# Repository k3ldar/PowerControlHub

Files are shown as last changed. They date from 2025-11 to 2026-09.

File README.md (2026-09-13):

# PowerControlHub  
PowerControlHub is an Arduino-based 12V power distribution and control system for marine and off-grid applications. It provides configurable fused relay switching, multi-protocol sensor telemetry, WiFi/BLE/MQTT connectivity, and a companion touchscreen control panel — all managed through a unified serial command protocol and EEPROM-persisted configuration.

> Current firmware version: **1.0.0.0** — see [`FirmwareVersion.h`](PowerControlHub/FirmwareVersion.h).

---

## Table of Contents

- [Overview](#overview)
- [Prototype PCBs](#prototype-pcbs)
- [Key Features](#key-features)
- [Architecture](#architecture)
- [Board Support](#board-support)
- [Installation](#installation)
- [Configuration](#configuration)
- [Usage](#usage)
- [Subsystem Reference](#subsystem-reference)
- [Limitations and Known Issues](#limitations-and-known-issues)
- [Documentation](#documentation)
- [License](#license)

## Overview

PowerControlHub is a single-unit firmware target running on an Arduino Uno R4 WiFi or ESP32 NodeMCU-32. The Nextion touchscreen display is driven directly by the PCH controller over a dedicated hardware serial port (`Serial2` for GPS; display connected via `NextionControl`).

The firmware entry point is `PowerControlHubApp`, which owns all subsystem instances and wires them together at startup. Host and debug communication uses a text-based framed serial protocol:

```
<CMD>:<key>=<value>;<key>=<value>\n
```

Commands are grouped by prefix (`F`, `C`, `R`, `H`, `W`, `S`, `M`, `N`, `E`, `T`) and are available over serial, USB, and — where applicable — the HTTP REST API. See [Docs/Commands.md](Docs/Commands.md) for the full reference.

---

## Prototype PCBs

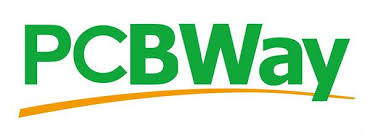
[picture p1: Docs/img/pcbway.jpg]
Prototype PCBs for PowerControlHub were supported by PCBWay

Prototype PCBs for **PowerControlHub** were supported by [PCBWay](https://www.pcbway.com), enabling rapid iteration from design to real-world testing.

See the [PCB Sponsorship & Manufacturing](Docs/pcbway.md) page for photos, build details, and ongoing testing.

---
## Key Features

### Relay Control
- Up to **8 independently configurable relay channels**, pin-assigned at runtime via configuration.
- **Linked relays** — any relay can be configured to mirror the state of another.
- **Default-on state** — individual relays can be initialised to active at boot.
- **Pulse mode** — relay activates for a configurable duration (seconds) then turns off automatically.
- **Named relays** — short name (5 chars) and long name (20 chars) stored in EEPROM for display use.
- **Action types** — relays can be designated as `Default`, `Horn` (COLREGS sound signal output), or `NightRelay` (automatic day/night switching driven by the LDR sensor).
- **Relay status bitmask** broadcast via `MessageBus` on every state change.

### Sensor Pipeline

All sensors inherit from `BaseSensor` and are registered with `SensorController`. The `RemoteSensor` class provides an extensibility point for sensors on external devices that push readings via serial.

| Sensor | Class | Poll Interval | Notes |
|---|---|---|---|
| **DHT11** | `Dht11SensorHandler` | 2 500 ms | Temperature (°C) and relative humidity (%). Raises `TemperatureSensorFailure` warning on read error; clears automatically on recovery. |
| **Light (LDR)** | `LightSensorHandler` | 30 000 ms | Rolling average over 10 readings. 3-reading debounce before day/night state change. Configurable ADC threshold (default 512). Drives a `NightRelay` automatically. |
| **Water Level** | `WaterSensorHandler` | Configurable | 15-reading rolling average. Active-pin corrosion-reduction control (power applied only during measurement). |
| **GPS** | `GpsSensorHandler` | Continuous | GY-GPS6MV2 (NMEA). Reports latitude, longitude, altitude, speed (km/h), course, cumulative distance. Provides UTC time for automatic RTC synchronisation. Raises `GpsFailure` warning if no valid fix for 30 seconds. |
| **System Diagnostics** | `SystemSensorHandler` | Configurable | Free heap memory, CPU usage percentage, WiFi/BT enabled state, SD log file size (bytes), system uptime (`d HH:MM:SS`), active warning count. |

Sensors expose data over Serial, WiFi REST, BLE, and MQTT. Custom local or remote sensors can be added with minimal boilerplate; see [Docs/Sensors.md](Docs/Sensors.md).

### Connectivity

#### WiFi
- Operates in **Access Point** or **Client** mode, selectable via `C12`.
- Implements **persistent HTTP connections** to reduce TCP handshake overhead on resource-constrained hardware.
- Supports up to **8 concurrent clients** (`MaxConcurrentClients`).
- Automatic reconnection with exponential backoff in Client mode.
- RSSI monitoring — raises `WeakWifiSignal` warning when signal falls below −70 dBm.
- Full REST API across 9 route groups:

| Route | Handler | Purpose |
|---|---|---|
| `/api/relay` | `RelayNetworkHandler` | Relay state read/write |
| `/api/sensor` | `SensorNetworkHandler` | Sensor telemetry |
| `/api/sound` | `SoundNetworkHandler` | COLREGS horn signals |
| `/api/system` | `SystemNetworkHandler` | System status, heartbeat, OTA |
| `/api/config` | `ConfigNetworkHandler` | Configuration read/write |
| `/api/warning` | `WarningNetworkHandler` | Warning bitmask access |
| `/api/timer` | `SchedulerNetworkHandler` | Scheduled event read |
| `/api/externalsensor` | `ExternalSensorNetworkHandler` | Remote sensor config |
| `/` | `WebIndexNetworkHandler` | Index page |

Uses a platform-abstraction interface (`IWifiRadio`) to isolate board-specific WiFi drivers from application logic.

#### Bluetooth BLE
- Available on boards with `BLUETOOTH_SUPPORT` defined.
- Exposes three GATT services via `BluetoothManager`:
  - `BluetoothSystemService` — system diagnostics characteristics.
  - `BluetoothSensorService` — sensor telemetry characteristics with notifications.
  - `BluetoothRelayService` — relay state read and write characteristics.
- Single-client model. Advertising restarts automatically after disconnect.
- No pairing or bonding. Device advertises as **"Power Control Hub"**.
- Uses `IBluetoothRadio` interface — higher-level code operates exclusively through the interface pointer, with runtime null-checks replacing compile-time guards.
- **Arduino Uno R4 WiFi constraint:** WiFi and BLE share the RF path on the ANNA-B112/ESP32-S3 modules; `BLUETOOTH_SUPPORT` and `WIFI_SUPPORT` are mutually exclusive on this board. Enforced by a compile-time `#error`. On ESP32, both can operate simultaneously.

#### MQTT
- Custom **MQTT 3.1.1** client implementation (`MQTTClient`) — no third-party MQTT library dependency.
- **Home Assistant auto-discovery** — all sensors and relays register as HA entities on connect.
- Configurable broker address (64 chars), credentials (32 chars each), device ID, discovery prefix, port (default 1883), and keepalive interval (default 60 s).
- Requires `WIFI_SUPPORT`. Guarded by `#if defined(WIFI_SUPPORT)` in `BoardConfig.h`.

### Warning System

A **32-bit bitmask** tracks up to 32 independent typed conditions within `WarningManager`.

- **Sensor failure aggregation**: any sensor warning (bits 21–31) automatically raises `SensorFailure` (bit 20). `SensorFailure` clears only when all sensor warnings are cleared.
- Warning state changes are broadcast on the `MessageBus` via `WarningChanged`.
- Full warning type reference: [Docs/Warnings.md](Docs/Warnings.md).

### Scheduler

Event-driven relay automation engine with EEPROM-persisted configuration.

- Up to **20 events** (6 on boards with ≤ 1 KB EEPROM) stored in `SchedulerSettings`.
- Each event specifies an independent **trigger**, **condition guard**, and **action**.

| Dimension | Supported Values |
|---|---|
| **Triggers** | `TimeOfDay`, `Sunrise`, `Sunset`, `Interval`, `DayOfWeek`, `Date` |
| **Conditions** | `TimeWindow`, `DayOfWeek`, `IsDark`, `IsDaylight`, `RelayIsOn`, `RelayIsOff` |
| **Actions** | `RelayOn`, `RelayOff`, `RelayToggle`, `RelayPulse`, `AllRelaysOn`, `AllRelaysOff`, `SetPinHigh`, `SetPinLow` |

Sunrise and sunset triggers are computed in real time from GPS coordinates by `SunCalculator`. The `IsDark` / `IsDaylight` conditions fall back to the LDR sensor when GPS is unavailable.

### Message Bus

`MessageBus` provides a **lightweight publish/subscribe event system** for internal component decoupling. No dynamic allocation occurs at publish time — subscriber lists use function-local statics.

Key events: `WarningChanged`, `RelayStatusChanged`, `TemperatureUpdated`, `HumidityUpdated`, `LightSensorUpdated`, `WaterLevelUpdated`, `GpsLocationUpdated`, `GpsAltitudeUpdated`, `GpsSpeedUpdated`, `WifiConnectionStateChanged`, `WifiSignalStrengthChanged`, `SystemMetricsUpdated`. Full reference: [Docs/MessageBus.md](Docs/MessageBus.md).

### Over-the-Air Updates (OTA)

- Available on **ESP32 + `WIFI_SUPPORT` + `OTA_AUTO_UPDATE`** only.
- Polls the GitHub Releases API (`k3ldar/PowerControlHub`) every **24 hours**.
- Downloads asset `PowerControlHub-esp32-v{major}.{minor}.{patch}.{build}.bin` with SHA-256 checksum verification.
- TLS connections use pinned root CA certificates (Sectigo E46 for `api.github.com`; ISRG Root X1 for `assets.githubusercontent.com`).
- **Auto-apply is disabled by default.** Enable via `F12:apply=1` or the `OtaFlagAutoApply` bit in `SystemHeader::reserved[0]`.
- OTA state (`idle`, `checking`, `available`, `downloading`, `rebooting`, `failed`, `uptodate`) is queryable at any time via `F13`.

### Diagnostics and Logging

- **SD card logging** via `SdCardLogger` / `MicroSdDriver`. Configurable SPI pins (`C4`). Raises `SpiPinConfigError`, `SdCardMissing`, `SdCardError`, or `SdCardLowSpace` warnings as appropriate.
- Optional **SD card config loader** (`CARD_CONFIG_LOADER`) — reads `config.txt` at boot to override EEPROM settings without reflashing.
- **DS1302 RTC** (`RtcDS1302Driver`) with configurable pins (`C18`). Automatically synchronised from GPS UTC time on each valid GPS fix.
- **CPU usage monitoring** via `SystemCpuMonitor`. Available over serial, WiFi, and MQTT.
- **Boot counter** and **crash counter** tracked in `SystemHeader` with magic number validation (`0x53464201`).
- **RGB LED warning indicator** (HW479) driven on configurable pins (`C8`).
- **PinGuard** — compile-time GPIO validation layer that rejects flash-reserved, input-only, and strapping pins at the point of assignment, returning `ACK:<cmd>=Invalid pin` before the value reaches EEPROM. Board-specific tables are selected automatically from the IDF toolchain macros — no manual configuration required. See [Docs/PinGuard.md](Docs/PinGuard.md).
- **Crash loop guard** — `crashCounter` in `SystemHeader` is incremented at the start of every boot and only reset after full initialisation succeeds. If the counter reaches `CrashCounterThreshold` (default 3), the firmware resets the config to safe defaults before any hardware initialisation runs, breaking a watchdog reset loop caused by invalid pin configuration.

### Nextion Display

- `NavigationController` manages an ordered list of active pages, rebuilt dynamically when the location type changes — no reboot required.
- Maritime-specific pages (buoys, cardinal markers, flags, VHF radio, COLREGS sound signals) are included in the page list only when `LocationType` is `Power`, `Sail`, `Fishing`, or `Yacht`.
- Pages included: Splash, Home, Relay, Relay Settings, Environment, System, Warning, Settings, About, Buoys, Cardinal Markers, Flags, Moon Phase, Sound (Fog / Maneuvering / Overtaking / Emergency / Other / Signals), VHF (Channels / Distress / Radio).

### Security

- **API key and HMAC key** fields (32 chars each) are reserved in the `Config` struct for future HTTP authentication.

---

## Architecture

### Repository Structure

```
PowerControlHub/    Firmware source (relays, sensors, WiFi, BLE, MQTT, OTA, SD, Nextion display)
Docs/            Reference documentation
TestData/        Serial command test scripts
```

### Subsystem Dependency Graph

```
PowerControlHubApp
├── MessageBus                  Pub/sub event bus (no dynamic allocation)
├── RelayController             Relay switching, linking, pulse, action types
├── SoundController             COLREGS signal sequencer -> horn relay
├── SensorController            Sensor pipeline (local + remote)
│   ├── Dht11SensorHandler
│   ├── LightSensorHandler
│   ├── WaterSensorHandler
│   ├── GpsSensorHandler
│   ├── SystemSensorHandler
│   └── RemoteSensor (xN)
├── ConfigController            EEPROM config lifecycle
├── WarningManager              32-bit bitmask, sensor failure aggregation
├── ScheduleController          Event engine: trigger -> condition -> action
├── WifiController              WiFi lifecycle, HTTP REST API
│   └── WifiServer              Connection state machine, request routing
├── BluetoothController         BLE lifecycle (BLUETOOTH_SUPPORT)
│   └── BluetoothManager
│       ├── BluetoothSystemService
│       ├── BluetoothSensorService
│       └── BluetoothRelayService
├── MQTTController              MQTT 3.1.1 client, HA auto-discovery (MQTT_SUPPORT)
├── SdCardLogger                SD card log writer (SD_CARD_SUPPORT)
├── RtcDS1302Driver             DS1302 real-time clock
├── OtaManager                  GitHub OTA (OTA_AUTO_UPDATE + ESP32 + WIFI_SUPPORT)
├── BroadcastManager            Centralised serial broadcast to computer/debug port
├── NavigationController        Nextion page navigation (NEXTION_DISPLAY_DEVICE)
└── SerialCommandManager        Framed serial command dispatch (USB/debug)
```

### Interface Abstraction Pattern

WiFi and Bluetooth subsystems are each accessed through a platform-agnostic interface (`IWifiRadio`, `IBluetoothRadio`). Board-specific drivers (`R4WifiRadio`, `Esp32WifiRadio`, `BluetoothController`) are constructed only inside `PowerControlHubApp` under the appropriate `#if defined(...)` guard. All higher-level code operates through interface pointers with runtime null-checks, minimising preprocessor usage and enabling straightforward test doubles.

### Configuration Persistence

The `Config` struct is a versioned, packed POD serialised to EEPROM. The current layout version is **6** (`ConfigVersion6`). The `SystemHeader` (32 bytes) precedes the config payload and contains a magic number (`0x53464201`), boot count, crash counter, reset reason, OTA flags, and a 16-bit checksum. A config version mismatch triggers migration logic in `ConfigManager` and raises `DefaultConfigurationFuseBox`.

---

## Board Support

| Board | WiFi | BLE | MQTT | OTA | Notes |
|---|---|---|---|---|---|
| **Arduino Uno R4 WiFi** | Yes | Yes | Yes | No | WiFi and BLE are mutually exclusive (shared RF path) |
| **Arduino Uno R4 Minima** | No | No | No | No | Serial and sensor support only |
| **ESP32 NodeMCU-32** | Yes | Yes | Yes | Yes | Full feature support; WiFi and BLE simultaneous |

Board selection is controlled by a single `#define` in `Local.h` using the trailing-underscore convention. `BoardConfig.h` derives all capability flags, EEPROM limits, and enforces incompatible feature combinations at compile time.

---

## Installation

### Prerequisites

| Requirement | Details |
|---|---|
| **Arduino IDE** | 1.8.19 or Arduino IDE 2.x |
| **Git for Windows** | Standard installation |
| **Windows 10 / 11** | No special configuration required |

### Required Libraries (Arduino Library Manager)

| Library | Source |
|---|---|
| `SerialCommandManager` | Si Carter |
| `DHT sensor library` | Adafruit |
| `QMC5883LCompass` | Arduino Library Manager |
| `NextionControl` | Custom — copy `NextionControl/` folder to Arduino `libraries/` directory |

### Steps

1. Clone the repository:

   ```
   git clone https://github.com/k3ldar/PowerControlHub
   ```

2. Install all required libraries via the Arduino IDE Library Manager, and copy `NextionControl` manually.

3. Open `k3ldar/PowerControlHub.ino` in the Arduino IDE.

4. Edit `Local.h` to activate the correct board and feature flags (see [Configuration](#configuration)).

5. Select the target board and COM port, then upload.

Full setup walkthrough: [Docs/SETUP.md](Docs/SETUP.md).

---

## Configuration

All hardware-specific configuration is isolated in a single file: `PowerControlHub/Local.h`. No other file requires modification for a standard hardware setup.

### Board Selection

Exactly one board define must be active. Remove the trailing underscore to activate:

```cpp
#define ARDUINO_UNO_R4       // Arduino Uno R4 WiFi
#define ARDUINO_R4_MINIMA_   // Arduino Uno R4 Minima (inactive)
#define ESP32_NODE_32_       // ESP32 NodeMCU-32 (inactive)
```

### Feature Flags

| Define | Default | Approx. Flash | Description |
|---|---|---|---|
| `FUSE_BOX_CONTROLLER` | Active | — | Enables the full SFB subsystem stack |
| `WIFI_SUPPORT` | Active | — | WiFi controller and HTTP REST API |
| `MQTT_SUPPORT` | Active | ~40 KB | MQTT client and HA auto-discovery (requires `WIFI_SUPPORT`) |
| `BLUETOOTH_SUPPORT` | Inactive | ~144 KB | BLE services (mutually exclusive with WiFi on Uno R4) |
| `SD_CARD_SUPPORT` | Active | ~32 KB | SD card logger and SPI driver |
| `NEXTION_DISPLAY_DEVICE` | Active | ~52 KB | Nextion display page system |
| `OTA_AUTO_UPDATE` | Active | ~165 KB | GitHub OTA (ESP32 + WiFi only) |
| `LED_MANAGER` | Inactive | — | Arduino R4 WiFi LED matrix (experimental) |
| `CARD_CONFIG_LOADER` | Inactive | — | Load config overrides from SD `config.txt` at boot |

### Relay Count

```cpp
constexpr uint8_t ConfigRelayCount = 8;  // number of relay channels
```

Pins are assigned at runtime via the `R11` serial command and persisted to EEPROM. `0xFF` marks a pin as unassigned.

Full configuration reference: [Docs/Local.md](Docs/Local.md).

---

## Usage

### Serial / USB Commands (Quick Reference)

Commands follow the frame format: `<CMD>:<key>=<value>;<key>=<value>\n`

```
# Save config to EEPROM
C0

# Enable WiFi in client mode, set SSID and password
C11:v=1
C12:v=1
C13:YourSSID
C14:YourPassword
C0

# Switch relay 0 on / off
R3:i=0;v=1
R3:i=0;v=0

# Query all relay states
R2

# Read temperature and humidity
S0
S1

# Enable MQTT and set broker
M0:v=1
M1:192.168.1.100
C0

# Enable Home Assistant auto-discovery
M6:v=1

# Query OTA status (ESP32 only)
F13

# Check for firmware update
F12

# Apply firmware update immediately
F12:apply=1
```

Full command reference (all groups, all parameters): [Docs/Commands.md](Docs/Commands.md).

### HTTP REST API (WiFi)

```
# Relay control
POST /api/relay/R3?i=0&v=1

# Sensor data
GET /api/sensor/S0

# System status
GET /api/system/F2

# OTA status
GET /api/system/F13
```

---

## Subsystem Reference

| Document | Contents |
|---|---|
| [Docs/Commands.md](Docs/Commands.md) | Full serial and REST command reference (all groups F, C, R, H, W, S, M, N, E, T) |
| [Docs/Local.md](Docs/Local.md) | `Local.h` configuration reference: board selection, feature flags, pin layout |
| [Docs/PinGuard.md](Docs/PinGuard.md) | GPIO validation: board pin tables, blocked pin tiers, crash loop guard |
| [Docs/Sensors.md](Docs/Sensors.md) | Sensor classes, poll intervals, MQTT channels, warning behaviour, extensibility guide |
| [Docs/Warnings.md](Docs/Warnings.md) | 32-bit warning type reference, `WarningManager` API, propagation model |
| [Docs/Wifi.md](Docs/Wifi.md) | WiFi architecture: connection state machine, persistent connection model, handler pattern |
| [Docs/BluetoothBle.md](Docs/BluetoothBle.md) | BLE service/characteristic reference, connection model, adding new services |
| [Docs/ScheduleEvents.md](Docs/ScheduleEvents.md) | Scheduler data structures, trigger/condition/action types, EEPROM layout |
| [Docs/MessageBus.md](Docs/MessageBus.md) | Event reference, publish/subscribe API |
| [Docs/SETUP.md](Docs/SETUP.md) | Prerequisites, library installation, build instructions |
| [Docs/BOM.md](Docs/BOM.md) | Bill of materials: hardware, fasteners, connectors, 3D-printed parts |

---

## Limitations and Known Issues

- **Arduino Uno R4 WiFi**: WiFi and BLE cannot operate simultaneously due to the shared RF hardware path. This is enforced at compile time.
- **Arduino Uno R4 Minima**: No radio support. Serial, sensors, and Nextion display only.
- **OTA updates**: Restricted to ESP32 targets with WiFi in client mode and `OTA_AUTO_UPDATE` defined. Not available on Arduino Uno R4.
- **Scheduler capacity**: Limited to 6 events on boards with 1 KB or less of EEPROM.
- **LED matrix manager** (`LED_MANAGER`): Experimental on Arduino R4 WiFi; not recommended for production use.
- **SD card support**: Marked experimental in `Local.h`. SPI pin configuration must be correct or `SpiPinConfigError` is raised.
- **Single BLE client**: Only one BLE central can be connected at a time. No pairing or bonding is implemented.

---

## Documentation

| Getting Started | Configuration | Connectivity |
|:---|:---|:---|
| [Setup Guide](Docs/SETUP.md) | [Local.h Reference](Docs/Local.md) | [WiFi Architecture](Docs/Wifi.md) |
| [Bill of Materials](Docs/BOM.md) | [Scheduled Events](Docs/ScheduleEvents.md) | [Bluetooth BLE](Docs/BluetoothBle.md) |
| [Sensor Reference](Docs/Sensors.md) | [Warning System](Docs/Warnings.md) | [Message Bus](Docs/MessageBus.md) |
| [Command Reference](Docs/Commands.md) | [PinGuard & Crash Loop](Docs/PinGuard.md) | |

---

## License

PowerControlHub is released under the **GNU General Public License v3.0**.  
See [LICENSE](LICENSE) for the full licence text.

Copyright &copy; 2025 Simon Carter (`s1cart3r@gmail.com`)

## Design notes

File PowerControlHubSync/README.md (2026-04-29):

# SmartFuseSync

A lightweight console utility for applying configuration updates to SmartFuseBox devices over a COM port serial connection.

---

## Commands

Run `SmartFuseSync -?` for a full list of available commands.

### `Config Update` — Apply a configuration file to a device

Reads a `.dat` configuration file and sends each non-blank line to the device one at a time, waiting for an `ACK` or `ERR` response before proceeding to the next command.

| Option | Abbreviation | Required | Description |
|---|---|---|---|
| `filePath` | `-f` | Yes | Path to the `.dat` configuration file |
| `portName` | `-p` | Yes | COM port name (e.g. `COM3`, `COM7`) |
| `baudRate` | `-b` | No | Baud rate (default: `9600`) |

**Examples:**

Using full option names:
```
SmartFuseSync Config Update --filePath:"C:\Configs\MyDevice.dat" --portName:COM7 --baudRate:115200
```

Using abbreviations:
```
SmartFuseSync Config Update -f:"C:\Configs\MyDevice.dat" -p:COM7 -b:115200
```

**Using a `.bat` file (recommended for repeated use):**

Create a `.bat` file with the same base name as your `.dat` file, e.g. `UpdateBasementSensor.bat`:
```bat
SmartFuseSync Config Update -f:"C:\GitProjects\SFB\UpdateBasementSensor.dat" -p:COM7 -b:115200
```

Double-click the `.bat` file or run it from a terminal to apply the configuration.

---

### `Config ListPorts` — List available COM ports

Displays all COM ports currently detected on the system. Useful for identifying the correct port before running an update.

```
SmartFuseSync Config ListPorts
```

---

### `Config Test` — Test connection to a device

Opens the specified COM port and confirms a connection can be established.

| Option | Abbreviation | Required | Description |
|---|---|---|---|
| `portName` | `-p` | Yes | COM port name (e.g. `COM3`, `COM7`) |
| `baudRate` | `-b` | No | Baud rate (default: `9600`) |

```
SmartFuseSync Config Test -p:COM7 -b:115200
```

---

### `Config Read` — Read current configuration from a device

Sends a `READ_CONFIG` request to the device and displays the response. Optionally saves the output to a file.

| Option | Abbreviation | Required | Description |
|---|---|---|---|
| `portName` | `-p` | Yes | COM port name (e.g. `COM3`, `COM7`) |
| `outputPath` | `-o` | No | File path to save the received configuration |
| `baudRate` | `-b` | No | Baud rate (default: `9600`) |

```
SmartFuseSync Config Read -p:COM7 -b:115200
SmartFuseSync Config Read -p:COM7 -b:115200 -o:"C:\Configs\Backup.dat"
```

---

## Configuration file format

Configuration files (`.dat`) contain one command per line. Blank lines are ignored. Each line is sent verbatim to the device.

**Example `UpdateBasementSensor.dat`:**
```
C11:v=1
C12:v=MyNetwork
M0:v=1
M1:v=0
```

The device responds to each command with:
- `ACK:<command>=ok:...` — command accepted
- `ERR:<command>:...` — command rejected (logged as a warning, processing continues)

---

## Serial port settings

All commands use the following fixed serial settings:

| Setting | Value |
|---|---|
| Parity | None |
| Data bits | 8 |
| Stop bits | 1 |
| Handshake | None |

The baud rate is configurable via `-b` (default `9600`). Use `-b:115200` for faster devices.

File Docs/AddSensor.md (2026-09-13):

# Adding a New Sensor Type

This guide lists every file that must be touched when adding a new local sensor type to PowerControlHub. It uses the Reed contact sensor (`S24`, `SensorIdList::ReedSensor` / `SensorType.ReedSwitch`) as the reference implementation.

## Overview

A sensor type spans two projects:

| Project | Path | Language |
|---|---|---|
| Firmware | `PowerControlHub\` | C++ (Arduino / ESP32) |
| App | `PowerControlHubApp\` | C# / .NET MAUI |

Configuration plumbing (add / remove / rename / pin / options) is **type-agnostic** and driven by the `SensorDescriptors` table in `SensorConfig.h`. Most of the integration work is metadata: describe the sensor's pins and options, then implement its runtime behaviour.

## Quick-reference touch-point table

| # | File | Change |
|---|---|---|
| 1 | `PowerControlHub\SystemDefinitions.h` | Add `SensorIdList` value + telemetry command constant |
| 2 | `PowerControlHub\SensorConfig.h` | Add `SensorTypeDescriptor` entry |
| 3 | `PowerControlHub\<NewSensor>Handler.h` | New handler class |
| 4 | `PowerControlHub\SensorFactory.h` | `#include` + factory `case` |
| 5 | `PowerControlHub\SensorNetworkHandler.cpp` | WiFi telemetry dispatch |
| 6 | `PowerControlHub\SensorCommandHandler.cpp/.h` | Serial query/push (only if polled over COM) |
| 7 | `PowerControlHub\WarningType.h` | New failure warning (only if needed) |
| 8 | `PowerControlHubApp\Models\SensorType.cs` | App enum mirror |
| 9 | `PowerControlHubApp\Internal\Constants.cs` | `SensorEnumXxx` constant |
| 10 | `PowerControlHubApp\Models\LocalSensorConfigModel.cs` | `TypeName` switch case |
| 11 | `PowerControlHubApp\Models\ExternalSensorConfigModel.cs` | `SensorIdNames` array entry |
| 12 | `PowerControlHubApp\Views\Templates\SensorTemplateSelector.cs` | Template mapping |
| 13 | `PowerControlHubApp\ViewModels\LocalSensorDetailViewModel.cs` | Fallback picker entry |
| 14 | `PowerControlHubApp\ViewModels\ExternalSensorDetailViewModel.cs` | Fallback picker entry |
| 15 | `PowerControlHubApp\Resources\Localization\AppResources.resx` (+ locales + `.Designer.cs`) | Display strings |
| 16 | `PowerControlHubApp\Models\Json\SensorsModel.cs` (+ optional XAML template) | Dashboard card fields |
| 17 | `Docs\Commands.md` | Command documentation |

---

## 1. Firmware

### 1.1 `SystemDefinitions.h`

Two additions:

1. A unique enum value in `SensorIdList`, inserted **before** `Count` (`None = 0xFF` stays last):

```cpp
enum class SensorIdList : uint8_t
{
    // ... existing values ...
    ReedSensor = 0x7,

    Count,
    None = 0xFF
};
```

2. A telemetry command ID constant. Pick the next free number after the existing `S7`–`S21` range (Binary Presence is `S22`, Voltage is `S23`, Reed is `S24`):

```cpp
constexpr char SensorReed[] = "S24";
```

### 1.2 `SensorConfig.h`

Add a `SensorTypeDescriptor` entry indexed by the new enum value. This table drives the MAUI config UI (pin slots, options, ranges, defaults) and PinGuard validation, so it is the single source of truth for how the sensor is configured over both COM and WiFi.

```cpp
[static_cast<size_t>(SensorIdList::ReedSensor)] = {
    .name = "Reed",
    .pins = {
        { "Sensor Pin", "gpio", 0, 39, 255, PinUse::Sensor },
        { "Active Pin", "gpio", 0, 39, 255, PinUse::Output },
        { "Unused", "none", 0, 0, 0, PinUse::Sensor },
        { "Unused", "none", 0, 0, 0, PinUse::Sensor },
    },
    .options1 = {
        { "NO/NC", "int8", 0, 1, 0, PinUse::Sensor },
        { "Unused", "none", 0, 0, 0, PinUse::Sensor },
    },
    .options2 = { { "Unused", "none", 0, 0, 0, PinUse::Sensor }, { "Unused", "none", 0, 0, 0, PinUse::Sensor } },
},
```

Notes:

- `pins` has `ConfigMaxSensorPins` (4) slots; `options1`/`options2` have 2 slots each.
- `type` is `"gpio"`, `"int8"`, `"int16"`, or `"none"`. Only `"gpio"` slots go through PinGuard.
- `defaultValue` `255` (`PinDisabled`) means "not fitted" for a pin.
- The existing `static_assert(std::size(SensorDescriptors) == SensorIdList::Count, ...)` will fail until you add this entry.

### 1.3 Create the handler class

Create `PowerControlHub\<NewSensor>Handler.h`. Derive from `BaseSensor` (and `BroadcastLoggerSupport` if the sensor sends debug/telemetry):

| Member | Purpose |
|---|---|
| `initialize()` | Set `pinMode`, initial state, optional output pin |
| `update()` | Poll the hardware; return the poll interval in ms; publish state changes |
| `formatStatusJson()` | Serialize current values; this becomes the sensor's dashboard JSON |
| `getSensorIdType()` | Return the new `SensorIdList` value |
| `getSensorType()` | Return `SensorType::Local` |
| `getSensorCommandId()` | Return the `SensorXxx` command constant |
| `getMqttChannelCount()/getMqttChannel()/getMqttValue()` | MQTT channel metadata (under `#if defined(MQTT_SUPPORT)`) |

For binary sensors, `formatStatusJson()` should emit a `"state":"detected"|"clear"` string — the app's `SensorsModel` maps these to red/green icons.

Self-broadcasting sensors call `sendCommand(SensorXxx, params, count)` from `update()` to push telemetry over serial/WiFi. See `ReedSensorHandler.h`, `BinaryPresenceSensor.cpp`, and `VoltageSensorHandler.h` for the pattern.

### 1.4 `SensorFactory.h`

1. Add `#include "<NewSensor>Handler.h"` at the top.
2. Add a `case SensorIdList::<NewSensor>:` inside `createOne()`. Validate the required pin (`entry.pins[0] != PinDisabled`), raise the appropriate `WarningType` on failure, and map `entry.pins`/`entry.options1`/`entry.options2` into the constructor arguments.

### 1.5 `SensorNetworkHandler.cpp`

Add the new command constant to the `S7`–`S24` telemetry dispatch condition so `/api/sensor` can query the sensor's status over WiFi:

```cpp
SystemFunctions::commandMatches(command, SensorReed)
```

### 1.6 `SensorCommandHandler.cpp` / `.h` (serial COM)

This centralized handler stores last values for `S7`–`S21` and answers no-param serial polls. Sensors such as Binary Presence (`S22`), Voltage (`S23`), and Reed (`S24`) **self-broadcast** via `BroadcastLoggerSupport::sendCommand` instead of storing state here.

- If the new sensor self-broadcasts and does **not** need a serial poll query, no change is required.
- If you want a no-param serial poll (e.g. `S24` returns the current value), add a query branch in `handleCommand()` and the command to `supportedCommands()`.

### 1.7 `WarningType.h` (conditional)

Only if the new sensor needs its own distinct failure warning. Add a bit flag and a `PROGMEM` string, then raise it from `SensorFactory::createOne()`. Otherwise reuse an existing warning (e.g. `SensorFailure` or `BinarySensorFailure`).

`Config.h` needs **no change** for a typical sensor — `SensorEntry` already provides `pins[4]`, `options1[2]`, and `options2[2]`.

---

## 2. MAUI app

The app mirrors the firmware enum and provides config UI and dashboard rendering.

### 2.1 `Models\SensorType.cs`

Add an enum value matching the firmware `SensorIdList` numeric value:

```csharp
ReedSwitch = 0x7,
```

### 2.2 `Internal\Constants.cs`

Add the numeric constant used by the config models:

```csharp
public const int SensorEnumReed = 7;
```

### 2.3 `Models\LocalSensorConfigModel.cs`

Add a `SensorEnumXxx => SensorTypeXxx` case to the `TypeName` switch.

### 2.4 `Models\ExternalSensorConfigModel.cs`

Add an entry to the `SensorIdNames` array at the index matching the enum value:

```csharp
SensorTypeReed,        // 7  Reed
```

### 2.5 `Views\Templates\SensorTemplateSelector.cs`

Map the new `SensorType` to an existing template (e.g. `BinaryPresenceTemplate`) or `GenericTemplate`:

```csharp
SensorType.ReedSwitch => BinaryPresenceTemplate ?? GenericTemplate,
```

### 2.6 View models (config picker fallback)

Add the picker label to the fallback list in **both**:

- `ViewModels\LocalSensorDetailViewModel.cs`
- `ViewModels\ExternalSensorDetailViewModel.cs`

```csharp
SensorTypeOptions.Add(SensorTypeReedPicker);
```

(This fallback is only used when the device's `?meta=1` descriptor cache is unavailable; otherwise the list is built from `SensorDescriptors`.)

### 2.7 Localization strings

Add `SensorTypeReed` ("Reed") and `SensorTypeReedPicker` ("Reed (7)") to:

- `Resources\Localization\AppResources.resx`
- each localized variant (e.g. `AppResources.de-DE.resx`, etc.)
- `AppResources.Designer.cs` (regenerated by Visual Studio from the `.resx`)

### 2.8 Dashboard card (optional)

- `Models\Json\SensorsModel.cs`: add computed properties that read the new sensor's fields from `ExtraFields` (parsed from `formatStatusJson()`).
- If a dedicated card is wanted, create `Views\Templates\<NewSensor>Template.xaml` (+ code-behind), register it in `Views\DashboardPage.xaml`, and add a `DataTemplate` property to `SensorTemplateSelector`.

`Services\DashboardConnection.cs` already casts the firmware `idType` to `SensorType` via `(SensorType)idType`, so no change is needed there as long as the enum value matches.

---

## 3. Documentation

Update `Docs\Commands.md`:

1. Add the new value to the `SensorIdList` table.
2. Add a field-mapping row for the sensor's pins/options under sensor configuration.
3. Add a telemetry row under `Sensor Telemetry — S7–S24` describing the params it emits.

---

## 4. Verification checklist

1. Firmware builds (Visual Micro / VS `PowerControlHub.ino` project).
2. MAUI app builds (`dotnet build` on `PowerControlHubApp.csproj`).
3. Sensor appears in `?meta=1` descriptors and can be added/configured over COM (`S0`–`S6`) and WiFi (`/api/sensorconfig`).
4. Telemetry appears in `/api/index` (`formatStatusJson`) and, if applicable, the serial telemetry query.
5. MQTT discovery publishes the expected channels (when `MQTT_SUPPORT` is enabled).

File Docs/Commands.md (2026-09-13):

# PowerControlHub Command Reference

## Overview

This document describes every command the PowerControlHub (PCH) firmware understands.
Commands travel over two transports:

| Transport | Format | Direction |
|---|---|---|
| **Serial / USB** | `<CMD>:<key>=<val>;<key>=<val>\n` | Bidirectional |
| **WiFi REST** | `POST /api/<group>/<CMD>?<key>=<val>&…` | Client → PCH |

### Command-group prefix summary

| Prefix | Group | Handler | WiFi route |
|---|---|---|---|
| `F` | System | `SystemCommandHandler` | `/api/system` |
| `C` | Configuration | `ConfigCommandHandler` / `ConfigNetworkHandler` | `/api/config` |
| `R` | Relay control & config | `RelayCommandHandler` / `RelayNetworkHandler` | `/api/relay` |
| `H` | Sound / fog-horn signals | `SoundCommandHandler` / `SoundNetworkHandler` | `/api/sound` |
| `W` | Warnings | `WarningCommandHandler` / `WarningNetworkHandler` | `/api/warning` |
| `S` | Sensor config & telemetry | `SensorConfigCommandHandler` / `SensorCommandHandler` / `SensorNetworkHandler` | `/api/sensor` |
| `M` | MQTT configuration | `MQTTConfigCommandHandler` | `/api/config` |
| `N` | Nextion display config | `NextionConfigCommandHandler` / `ConfigNetworkHandler` | `/api/config` |
| `E` | External (remote) sensor config | `ExternalSensorConfigCommandHandler` / `ExternalSensorNetworkHandler` | `/api/externalsensor` |
| `T` | Timer / scheduler | `SchedulerCommandHandler` / `SchedulerNetworkHandler` | `/api/timer` |
| `ACK` | Acknowledgement | `AckCommandHandler` | — |

### General conventions

- All commands and parameters are **case-sensitive**.
- Serial frame format: `CMD:key=val;key=val\n` — delimiter `:`, param separator `;`, key/value separator `=`.
- Up to **5 parameters** per command on the serial transport.
- Responses follow the same frame format; multi-value responses send multiple frames.
- Every mutating command that requires a **reboot** to take effect returns `reboot=1` in its ACK.
- Use `C0` (Save Settings) to persist in-memory changes to EEPROM before powering off.
- `255` / `0xFF` means **disabled / not fitted** for any pin field.

---

## System Commands — `F`

These are commands used to configure the system settings and can only be sent from a computer, they are not used for internal communication.

| Command | Example | Purpose |
|---|---|---|
| `F0` — Heart beat | `F0:w=0x00` or `F0:w=0x00;t=1733328600` | Send at rated intervals to monitor connection health. If no ACK received, indicates connection loss. **Params:** `w=<hex_warnings>` - bitmask of active local warnings (hex format). `t=<timestamp>` - Unix timestamp for continuous time sync. PowerControlHub automatically updates clock from `t=` parameter. |
| `F1` — System Initialized | `F1` | Sent by the system when initialization is complete to signal readiness. No params. Used to notify connected devices or software that the control panel is ready for operation. |
| `F2` — Free Memory | `F2` | When received will return the amount of free memory. |
| `F3` — Cpu Usage | `F3` | When received will return the current CPU usage. No params. |
| `F4` — Bluetooth Enabled | `F4` | When received will return the current enabled state of bluetooth 0 off 1 on. No params. |
| `F5` — Wifi Enabled | `F5` | When received will return the current enabled state of wifi 0 off 1 on. No params. |
| `F6` — Set DateTime | `F6:v=1733328600` | Set current date/time. Accepts Unix timestamp (seconds since epoch). Returns current stored time. |
| `F7` — Get DateTime | `F7` | Get current date/time as ISO 8601 datetime string `YYYY-MM-DDTHH:MM:SS`. |
| `F8` — SD Card Present | `F8` | Query if SD card is present. Returns `v=0` (not present) or `v=1` (present). No params. |
| `F9` — SD Card Log File Size | `F9` | Get current log file size in bytes. Returns `v=<bytes>` where bytes is the size of the active log file. Returns `v=0` if no file is open. No params. |
| `F10` — RTC Diagnostic | `F10` | Perform DS1302 RTC diagnostics. Returns status message with RTC health (availability, running state, write protection, time validity). Returns error message if RTC fails any check. No params. |
| `F11` — Uptime | F11 | Returns system uptime as "days HH:MM:SS" (e.g. 2d 03:12:45). No params. |
| `F12` — OTA Check / Apply | `F12` or `F12:apply=1` | Trigger an OTA firmware check against the latest GitHub release. Without params (or `apply=0`) checks only and returns current status. With `apply=1` downloads and applies the update if one is available (or queues apply if a check is already in progress). Response params: `v=<current>` current firmware version, `av=<available>` available version tag (empty if none found yet), `s=<state>` OTA state string. **PCH only** — requires `OTA_AUTO_UPDATE`, ESP32 and WiFi in client mode. |
| `F13` — OTA Status | `F13` | Query current OTA state without triggering a check. Response params: `v=<current>` current firmware version, `av=<available>` available version tag, `s=<state>` OTA state string (`idle`, `checking`, `available`, `downloading`, `rebooting`, `failed`, `uptodate`), `auto=<0\|1>` whether auto-apply is enabled. **PCH only** — requires `OTA_AUTO_UPDATE`, ESP32 and WiFi in client mode. |
| `F14` — PinGuard Mode | `F14` or `F14:a=true` or `F14:a=false;b=false` | Read or write the persistent PinGuard mode flags stored in `SystemHeader::pinGuardFlags`. **Params:** `a=<bool>` — AllowAdvisory: when `true`, advisory (strapping/UART) pins are permitted. `b=<bool>` — Bypass: when `true`, all PinGuard checks are skipped (no validation at all). If both `a` and `b` are `true`, Bypass takes precedence and the system returns `Safe` immediately. Changes are persisted immediately via `saveHeader()` and take effect at runtime without reboot. **Response:** `a=<0\|1>` current AllowAdvisory state, `b=<0\|1>` current Bypass state. No params = read-only. |
| `F15` — Pin Usage | `F15` | Returns a list of all GPIO pins currently assigned in configuration. Pins set to `0xFF` (disabled / not fitted) are omitted. **Serial response:** `v=pin1,pin2,...` (single frame). **WiFi response:** JSON object with a `pins` array. No params. |
| `F16` — Pin Restrictions | `F16` | Returns the compile-time pin restriction table for the current target MCU. Pins are classified as `Hard` (always blocked, e.g. flash-reserved, PSRAM) or `Advisory` (strapping, UART0, USB, JTAG — usable only when PinGuard AllowAdvisory is enabled). **Serial response:** one line per pin as `pin - category` followed by `ACK:F16=ok`. **WiFi response:** JSON object with `"hard"` and `"advisory"` integer arrays. No params. |
| `F17` — Location Types | `F17` | Returns all `LocationType` enum values as descriptors. Each entry has `id` (uint8), `type` (`boat` or `other`), and `desc` (human-readable name). **Serial response:** one line per descriptor as `F17:id=<id>;type=<boat\|other>;desc=<name>` followed by `ACK:F17=ok`. **WiFi response:** JSON object with `"success"`, `"command"`, and `"locations"` array of `{"id", "type", "description"}` objects. No params. |

**OTA behaviour (F12 / F13):**
- Automatic periodic check every 24 hours (first check fires 24 h after boot).
- `F12` without params (or `apply=0`) triggers a check only — it does **not** apply automatically.
- `F12:apply=1` downloads and applies immediately; if a check is in progress the apply is queued.
- Auto-apply is **off by default**; enable via `OtaFlagAutoApply (0x01)` in `SystemHeader::reserved[0]`.
- State transitions broadcast an `F12` automatically as they occur.
- `F13` is read-only — it never triggers any OTA activity.
- OTA is only active when `OTA_AUTO_UPDATE` is defined, the board is an ESP32, `WIFI_SUPPORT` is defined, and WiFi is in connected client mode.

### WiFi system commands
Route: `/api/system/{command}`  
Example: `GET /api/system/F2`

---

## Configuration Commands — `C`

| Command | Example | Purpose |
|---|---|---|
| `C0` — Save Settings | `C0` | Persist current in-memory config to EEPROM. Responds `SAVED` on success. No params. |
| `C1` — Get Settings | `C1` | Request full config dump. PCH replies with multiple frames covering all groups (see below). No params. |
| `C2` — Reset Settings | `C2` | Full reset of all config to factory defaults. No params. |
| `C3` — Rename Location | `C3:Sea Wolf` | Set the location name. Value directly, no `v=` prefix. Empty name → error. |
| `C4` — SPI Pins | `C4:sck=12;mosi=11;miso=13` | Set SD card SPI bus pins. Params: `sck=<pin>;mosi=<pin>;miso=<pin>`. Use `255` to clear any pin. Call `C0` to persist. |
| `C5` — Map Home Button | `C5:1=3` (map) — `C5:1=255` (unmap) | Map a home-page slot (0..3) to a relay (0..7), or `255` to unmap. |
| `C6` — XpdzTone Pin | `C6:v=12` | Set XpdzTone buzzer/piezo pin. `v=255` to disable. Call `C0` to persist. |
| `C7` — Location Type | `C7:v=1` | Set location type: `0`=Motor, `1`=Sail, `2`=Fishing, `3`=Yacht. |
| `C8` — Hw479Rgb Pins | `C8:r=12;g=13;b=14` | Set RGB LED warning indicator pins. Use `255` for any pin not fitted. Call `C0` to persist. |
| `C9` — Sound Start Delay | `C9:v=500` | Delay in milliseconds before sound starts, allowing other processing to complete. |
| `C10` — Bluetooth Enabled | `C10:v=1` | Enable (`1`) / disable (`0`) Bluetooth. Restart required. |
| `C11` — WiFi Enabled | `C11:v=1` | Enable (`1`) / disable (`0`) WiFi. Restart required. |
| `C12` — WiFi Access Mode | `C12:v=1` | Access mode: `0`=AP, `1`=Client. |
| `C13` — WiFi SSID | `C13:RouterName` | Set WiFi SSID (client mode only). Value directly, no `v=` prefix. |
| `C14` — WiFi Password | `C14:Password123` | Set WiFi password. Value directly, no `v=` prefix. |
| `C15` — WiFi Port | `C15:v=80` | Set listen port. Default `80`. Zero or invalid → error. |
| `C16` — WiFi Connection State | `C16` | Returns current `WifiConnectionState` value. Read-only, no params. |
| `C17` — WiFi AP IP Address | `C17:192.168.4.1` | Set AP-mode IP address. Value directly, no `v=` prefix. |
| `C18` — RTC Pins | `C18:dat=4;clk=5;rst=6` | Set DS1302 RTC pins. Use `255` for any pin not fitted. Call `C0` to persist. |
| `C19` — Network Authentication | `C19:e=1;k=MyApiKey;h=MyHmacKey` or `C19:g=1` | Configure WiFi API authentication. **Params:** `e=<0\|1>` enable/disable auth (disabled by default). `k=<key>` set API key (max 31 chars). `h=<key>` set HMAC-SHA256 key (max 31 chars). `g=1` auto-generate device-unique keys from the WiFi MAC address. No params returns current state as `e=<0\|1>;k=<apiKey>;h=<hmacKey>`. Call `C0` to persist. When enabled, all `/api/*` endpoints require either an `X-API-Key` header matching the configured key, or valid `X-Auth-Timestamp` + `X-Auth-Signature` HMAC headers. See [Network Authentication](#network-authentication) below. |
| `C20` — Timezone Offset | `C20:v=-5` | Set UTC timezone offset in hours. Valid range: −12 to +14. |
| `C21` — MMSI | `C21:v=123456789` | Set 9-digit Maritime Mobile Service Identity. Value directly. |
| `C22` — Call Sign | `C22:v=ABCD123` | Set location call sign. Value directly, truncated to max length. |
| `C23` — Home Port | `C23:v=Miami` | Set location home port. Value directly, truncated to max length. |
| `C24` — LED Color | `C24:t=0;c=0;r=255;g=50;b=213` | Set LED RGB color. `t`: `0`=day, `1`=night. `c`: `0`=good, `1`=bad. RGB values 0–255. |
| `C25` — LED Brightness | `C25:t=0;b=75` | Set LED brightness 0–100. `t`: `0`=day, `1`=night. |
| `C26` — LED Auto Switch | `C26:v=1` | Enable/disable automatic day/night LED switching. |
| `C27` — LED Enable States | `C27:g=1;w=1;s=0` | Enable/disable individual LEDs. `g`=GPS, `w`=Warning, `s`=System. |
| `C28` — Control Panel Tones | `C28:t=0;h=400;d=500;p=0;r=30000` | Configure tones. `t`: `0`=good, `1`=bad. `h`=Hz, `d`=duration ms. `p`=preset: `0`=custom, `1`=submarine ping, `2`=double beep, `3`=rising chirp, `4`=descending alert, `5`=nautical bell, `255`=silent. `r`=repeat interval ms (bad only, `0`=no repeat). |
| `C29` — Reload Config from SD | `C29` | **Serial only.** Reload configuration from SD card `config.txt`. |
| `C30` — Export Config to SD | `C30` | **Serial only.** Export current config to SD card. |
| `C31` — SD Card Init Speed | `C31:v=4` | Set SD card SPI init speed in MHz. Valid: 4, 8, 12, 16, 20, 24. Default 4 MHz. Higher speeds should only be used with cards that support high-speed SPI; reduce to 4–8 MHz if experiencing init failures. |
| `C32` — SD Card CS Pin | `C32:v=10` | Set SD card chip-select GPIO pin. Use `255` to disable. Call `C0` to persist. |
| `C33` — Light Sensor Threshold | `C33:v=512` | Analogue threshold (0–1023) above which daytime is detected. Default 512. Uses a rolling average of the last 10 samples; 3 consecutive consistent readings required before day/night state changes (see `S16`). |

**C1 response sequence:**  
PCH sends back: `C3` (name), `C4` (SPI pins), `C5` (home-button mappings), `C7` (location type), `C9` (sound delay), `C10`–`C17` (WiFi/Bluetooth — PCH only), `C18` (RTC pins), `C19` (network auth), `C20`–`C23` (location identity), `C24`–`C27` (LED config), `C28` (tones), `N1`–`N6` (Nextion config), `R6` per relay (names), `R7` per relay (colours), `R8` per relay (default states), `R9` (linked pairs), `R10` (action types), `R11` (pins), `S0` per sensor (sensor config), then `ACK:C1=ok`.

Common errors: `Missing param`, `Empty name`, `Invalid boat type`, `Invalid offset (-12 to +14)`, `MMSI must be 9 digits`, `Invalid speed (4, 8, 12, 16, 20, or 24 MHz)`, `Config not available`, `EEPROM commit failed`.

### WiFi configuration commands
Route: `/api/config/{command}`  
Example: `POST /api/config/C6?v=12`

---

## Nextion Display Configuration Commands — `N`

Each field is its own command so no message exceeds the 5-parameter serial limit.  
**Reboot required** for changes to take effect. Every mutating ACK carries `reboot=1`.  
Serial and network share the same handler — N-commands travel via `/api/config` on the network transport.

| Command | Example | Purpose |
|---|---|---|
| `N0` — Get Nextion Config | `N0` | Returns current config as individual `N1`–`N6` responses. No params. |
| `N1` — Enabled | `N1:v=1` | Enable (`1`) / disable (`0`) the Nextion display. Call `C0` to persist. |
| `N2` — Hardware Serial | `N2:v=1` | Serial mode: `1`=HardwareSerial, `0`=SoftwareSerial (uses rxPin/txPin). Call `C0` to persist. |
| `N3` — RX Pin | `N3:v=16` | Set RX pin. Use `255` to clear. Call `C0` to persist. |
| `N4` — TX Pin | `N4:v=17` | Set TX pin. Use `255` to clear. Call `C0` to persist. |
| `N5` — Baud Rate | `N5:v=9600` | Set serial baud rate. Call `C0` to persist. |
| `N6` — UART Number | `N6:v=1` | ESP32 UART peripheral index. Valid values: `1` or `2` (UART0 reserved for USB/debug). Call `C0` to persist. |

**WiFi route:** `/api/config/{command}`  
**Example:** `POST /api/config/N1?v=1`

**Setup example:**
```
N1:v=1    # Enable Nextion
N2:v=1    # Hardware serial
N3:v=16   # RX pin
N4:v=17   # TX pin
N5:v=9600 # Baud rate
N6:v=1    # UART1
C0        # Save to EEPROM
```

---

## External Sensor Configuration Commands — `E`

These commands configure the `RemoteSensorsConfig` array used to construct `RemoteSensor` instances dynamically at boot. Because each sensor record has more fields than the 5-parameter serial limit, add/update is split across two commands (`E1` for core fields, `E2` for MQTT detail fields).

**Reboot required** for changes to take effect. Every mutating ACK carries `reboot=1`.

| Command | Example | Purpose |
|---|---|---|
| `E0` — Get All | `E0` | Returns two frames per configured sensor (core fields then MQTT fields). No params. |
| `E1` — Set Core Fields | `E1:i=0;id=3;n=Gps;mn=Latitude;ms=latitude` | Set identity and core MQTT fields for sensor at index `i`. Params: `i=<idx>` (0-based, max `ConfigMaxSensors`); `id=<sensorId>` (`SensorIdList` enum value); `n=<name>` (≤20 chars — also used as the serial command ID that external devices push updates to); `mn=<mqttName>` (≤15 chars); `ms=<mqttSlug>` (≤15 chars). Call `C0` to persist. |
| `E2` — Set MQTT Fields | `E2:i=0;mt=latitude;md=;mu=°;bin=0` | Set MQTT type/device-class/unit fields for sensor at index `i`. Params: `i=<idx>`; `mt=<mqttTypeSlug>` (≤15 chars); `md=<mqttDeviceClass>` (≤15 chars, empty to clear); `mu=<mqttUnit>` (≤10 chars, empty to clear); `bin=<0\|1>` (binary sensor flag). Call `C0` to persist. |
| `E3` — Remove | `E3:0` | Remove sensor at index. Remaining entries are compacted down. Call `C0` to persist. |
| `E4` — Rename | `E4:0=GpsUnit` | Rename sensor at index. Param format: `<idx>=<name>`. Call `C0` to persist. |

**`E0` response format (two frames per sensor):**
```
E0:i=<idx>;id=<sensorId>;n=<name>;mn=<mqttName>;ms=<mqttSlug>
E0:i=<idx>;mt=<mqttTypeSlug>;md=<mqttDeviceClass>;mu=<mqttUnit>;bin=<0|1>
```

**`SensorIdList` values for the `id` parameter:**

| Value | Name |
|---|---|
| `0` | WaterSensor |
| `1` | Dht11Sensor |
| `2` | LightSensor |
| `3` | GpsSensor |
| `4` | SystemSensor |
| `5` | BinaryPresenceSensor |
| `6` | VoltageSensor |
| `7` | ReedSensor |

**How external sensors receive value updates:**  
After boot the `name` field doubles as the sensor's serial command ID. An external device pushes readings by sending the name as a command:
```
Gps:lat=51.507351;lon=-0.127758
```
`SensorCommandHandler` routes this to the matching `RemoteSensor` which stores the values for MQTT publishing and status queries.

**WiFi route:** `/api/externalsensor/{command}`  
**GET** `/api/externalsensor/` returns a JSON status block with all configured sensors.  
**Example:** `POST /api/externalsensor/E1?i=0&id=3&n=Gps&mn=Latitude&ms=latitude`

**Setup example (GPS sensor with two channels):**
```
E1:i=0;id=3;n=Gps;mn=Latitude;ms=latitude
E2:i=0;mt=latitude;md=;mu=°;bin=0
E1:i=1;id=3;n=Gps;mn=Longitude;ms=longitude
E2:i=1;mt=longitude;md=;mu=°;bin=0
C0    # Save to EEPROM — reboot to activate
```

Common errors: `Config not available`, `Invalid sensor index`, `Invalid or missing parameters`, `Missing sensor index`, `Missing parameters`, `Missing name`.

---

## Acknowledgement — `ACK`

Every command returns an ACK frame on the serial transport:

| Example | Meaning |
|---|---|
| `ACK:R3=ok` | Command `R3` processed successfully. |
| `ACK:R3=Index out of range` | Command `R3` failed with the given error message. |

WiFi commands return JSON (`{"success":true}` or `{"success":false,"message":"…"}`) rather than ACK frames.

---

## Relay Control & Configuration Commands — `R`

| Command | Example | Purpose |
|---|---|---|
| `R0` — Turn All Off | `R0` | Turn off all relays. No params. |
| `R1` — Turn All On | `R1` | Turn on all relays. No params. |
| `R2` — Retrieve States | `R2` | Return the current state of all relays. |
| `R3` — Set Relay State | `R3:3=1` | Set relay `idx` on (`1`) or off (`0`). Param: `<idx>=<state>`. `idx` 0..7. |
| `R4` — Get Relay State | `R4:3` | Return state of relay at `idx`. Param: `<idx>`. |
| `R5` — Get All Relay Config | `R5` | Returns full relay config as a series of `R6`–`R11` responses. No params. |
| `R6` — Relay Rename | `R6:2=Bilge` or `R6:2=Bilge\|Bilge Pump` | Rename relay `idx`. Param: `<idx>=<shortName>` or `<idx>=<short\|long>`. Short ≤5 chars (home page), long ≤20 chars (buttons page). |
| `R7` — Set Button Color | `R7:2=4` or `R7:2=255` (clear) | Set active (on) button colour for relay `idx`. `0`=Blue, `1`=Green, `2`=Orange, `3`=Purple, `4`=Red, `5`=Yellow, `255`=clear. |

| `R7` — Set Button Color | `R7:2=4` or `R7:2=255` (clear) | Set active (on) button colour for relay `idx`. Accepts Nextion picture IDs (as stored on the device): `2`=Blue, `3`=Green, `4`=Grey, `5`=Orange, `6`=Red, `7`=Yellow, `255`=clear. |
| `R8` — Set Default State | `R8:3=1` | Power-on default state for relay `idx`: `0`=off, `1`=on. |
| `R9` — Link Relays | `R9:3=4` (link) — `R9:3=255` (unlink) | Link two relays so toggling one toggles the other. `255` to unlink. |
| `R10` — Set Action Type | `R10:2=0` / `R10:2=1` / `R10:2=2` | Set relay action type: `0`=Default, `1`=Horn (activates sound system), `2`=NightRelay (activates at night per light sensor). Only one relay per type at a time. |
| `R11` — Set Pin | `R11:2=15` | Set GPIO pin for relay `idx`. Must be a valid non-zero pin number or 255 to disable |

### WiFi relay commands
Route: `/api/relay/{command}`  
Example: `POST /api/relay/R3?3=1`

---

## Sound / Fog-Horn Signal Commands — `H`

| Command | Example | Purpose |
|---|---|---|
| `H0` — Cancel All | `H0` | Cancel all active sound signals immediately. No params. |
| `H1` — Is Active | `H1` | Returns active status as `<SoundType>=<SoundState>` pairs. No params. |
| `H2` — SOS / Danger | `H2` | Activates SOS horn sound (`...---...`) until cancelled. No params. |
| `H3` — Fog Signal | `H3` | Activates fog signal (location-type dependent) every 2 minutes until cancelled. No params. |
| `H4` — Manoeuvre Starboard | `H4` | One short blast. No params. |
| `H5` — Manoeuvre Port | `H5` | Two short blasts. No params. |
| `H6` — Manoeuvre Astern | `H6` | Three short blasts. No params. |
| `H7` — Manoeuvre Danger | `H7` | Five short rapid blasts. No params. |
| `H8` — Overtake Starboard | `H8` | Two prolonged + one short blast. No params. |
| `H9` — Overtake Port | `H9` | Two prolonged + two short blasts. No params. |
| `H10` — Overtake Consent | `H10` | One prolonged + one short + one prolonged + one short blast. No params. |
| `H11` — Overtake Danger | `H11` | Five short rapid blasts. No params. |
| `H12` — Test | `H12` | Test the horn/buzzer. No params. |

### WiFi sound commands
Route: `/api/sound/{command}`  
Example: `POST /api/sound/H3`

---

## Warning Commands — `W`

| Command | Example | Purpose |
|---|---|---|
| `W0` — Warnings Active | `W0:v=3` | Sent by SFB; indicates count of currently active warnings. |
| `W1` — List Warnings | `W1` | Retrieve warning list. Returns one `W2` frame per warning. No params. |
| `W2` — Warning Status | `W2:0x05=1` | Status of a single warning type. Param: `<WarningType>=<0\|1>`. |
| `W3` — Clear Warnings | `W3` | Clear all active warnings. No params. |
| `W4` — Set Warning Status | `W4:0x06=1` | Raise (`1`) or clear (`0`) a specific warning. Param: `<WarningType>=<0\|1>`. |
| `W5` — List Warning Text | `W5` | Returns one `W5:<hex>=<description>` frame per active warning and ends with `ACK:W5=ok`. Use this to get human-readable descriptions of all active warnings. No params. **WiFi response:** `{"success":true,"warnings":["desc1","desc2"]}`. |

### WiFi warning commands
Route: `/api/warning/{command}`  
Example: `GET /api/warning/W1`

---

## MQTT Configuration Commands — `M` (SFB only)

Requires `MQTT_SUPPORT` to be defined. M-commands share the `/api/config` network route.

| Command | Example | Purpose |
|---|---|---|
| `M0` — MQTT Enabled | `M0:v=1` | Enable (`1`) / disable (`0`) MQTT. Query without params returns current state. |
| `M1` — Broker Address | `M1:192.168.1.100` | Set broker hostname or IP. Value directly, no `v=` prefix. |
| `M2` — Broker Port | `M2:v=1883` | Set broker port. Default 1883. |
| `M3` — Username | `M3:myuser` | Set MQTT username. Leave empty for unauthenticated. |
| `M4` — Password | `M4:mypassword` | Set MQTT password. |
| `M5` — Device ID | `M5:boat_seawolf_01` | Set unique device identifier used in all topic paths: `<prefix>/<deviceId>/…`. |
| `M6` — HA Discovery | `M6:v=1` | Enable/disable Home Assistant auto-discovery messages. |
| `M7` — Keep-Alive | `M7:v=60` | PING interval in seconds. Default 60. |
| `M8` — Connection State | `M8` | Returns `v=0` (disconnected) or `v=1` (connected). Read-only. |
| `M9` — Discovery Prefix | `M9:homeassistant` | Base topic prefix. Default `homeassistant`. Used in all discovery and state topics. |

**MQTT topic structure:**
- Relay state / command: `<prefix>/<deviceId>/relay/<idx>/state` / `.../set`
- Sensor data: `<prefix>/<deviceId>/sensor/<type>/state`
- System metrics: `<prefix>/<deviceId>/system/<metric>/state`
- Warnings: `<prefix>/<deviceId>/warning/active/state`
- HA discovery: `<prefix>/switch/<deviceId>/relay<idx>/config`

**Setup example:**
```
M0:v=1              # Enable MQTT
M1:192.168.1.100    # Broker IP
M5:boat_seawolf_01  # Device ID
C0                  # Save to EEPROM
```

### WiFi MQTT commands
Route: `/api/config/{command}` (shares the config route)

---

## Sensor Commands — `S`

`S0`–`S6` are configuration commands (persisted in EEPROM, **reboot required**).  
`S7`–`S24` are live telemetry commands (sensor readings).

### Sensor Configuration — `S0`–`S6`

| Command | Example | Purpose |
|---|---|---|
| `S0` — Get All Sensor Config | `S0` or `S0?meta=1` | Returns one `S0` frame per configured sensor: `i=<idx>;t=<type>;n=<name>;p0=<pin>;p1=<pin>;u0=<opt1_0>;u1=<opt1_1>;o0=<opt2_0>;o1=<opt2_1>;en=<0\|1>`. The labels in the response are read-only aliases: `p0`/`p1` = `pins[0]`/`pins[1]`; `u0`/`u1` = `options1[0]`/`options1[1]` (signed byte); `o0`/`o1` = `options2[0]`/`options2[1]` (signed 16-bit). **WiFi only:** Append `?meta=1` to include a `"meta"` block with sensor type descriptors (field labels, types, ranges, defaults) for self-describing dynamic UI. No serial params. |
| `S1` — Add / Update Sensor | `S1:i=<idx>;t=<type>;o0=<val>;o1=<val>` | Add or update sensor at index `i`. **Only four params are accepted:** `i` (sensor index), `t` (type — `SensorIdList` enum value), `o0` (writes `options1[0]`), `o1` (writes `options1[1]`). Pins and all other options must be set separately via `S4` and `S6` **after** `S1`. All four params are required. ACK carries `reboot=1`. |
| `S2` — Remove Sensor | `S2:v=0` | Remove (clear) sensor at index. Param: `v=<idx>`. ACK carries `reboot=1`. |
| `S3` — Rename Sensor | `S3:0=Bilge Pump` | Rename sensor at index. Param: `<idx>=<name>`. ACK carries `reboot=1`. |
| `S4` — Set Sensor Pin | `S4:i=0;s=0;v=34` | Set a GPIO pin for sensor `i`. **All three params are required:** `i` (sensor index), `s` (pin slot, 0..`ConfigMaxSensorPins-1`), `v` (GPIO pin number; `255` to clear). Each sensor type uses specific slots — see the sensor type table below. ACK carries `reboot=1`. |
| `S5` — Set Sensor Enabled | `S5:0=1` | Enable (`1`) / disable (`0`) sensor at index. ACK carries `reboot=1`. |
| `S6` — Set Sensor Option | `S6:i=0;s=0;o=0;v=1` | Set an option value for sensor `i`. **All four params are required:** `i` (sensor index), `s` (slot, 0 or 1), `o` (group: `0`=`options1` signed byte, `1`=`options2` signed 16-bit), `v` (value). See the sensor type table below for which slot/group each sensor uses. ACK carries `reboot=1`. |

> **Understanding the field storage and response labels**
>
> Sensor configuration is stored in three arrays inside `SensorEntry`. The `S0` response exposes these with short labels for readability, but you **cannot use those labels as input to `S1`**:
>
> | `S0` response label | Underlying storage | Command to write it |
> |---|---|---|
> | `p0` | `pins[0]` | `S4:i=<idx>;s=0;v=<pin>` |
> | `p1` | `pins[1]` | `S4:i=<idx>;s=1;v=<pin>` |
> | `u0` | `options1[0]` (signed byte) | `S6:i=<idx>;s=0;o=0;v=<val>` |
> | `u1` | `options1[1]` (signed byte) | `S6:i=<idx>;s=1;o=0;v=<val>` |
> | `o0` | `options2[0]` (signed 16-bit) | `S6:i=<idx>;s=0;o=1;v=<val>` |
> | `o1` | `options2[1]` (signed 16-bit) | `S6:i=<idx>;s=1;o=1;v=<val>` |
>
> `S1` only writes `options1[0]` and `options1[1]` (its `o0`/`o1` params). Everything else requires a separate `S4` or `S6` call.

**Sensor type values (`t` for `S1`) — field mapping:**

The table below shows what each storage field means for each sensor type and which command sets it.

| Value | Name | Field | Meaning | Command |
|---|---|---|---|---|
| `0` | Water Sensor | `pins[0]` | Data pin | `S4:i=<idx>;s=0;v=<pin>` |
| | | `pins[1]` | Power pin | `S4:i=<idx>;s=1;v=<pin>` |
| `1` | DHT11 | `pins[0]` | Data pin | `S4:i=<idx>;s=0;v=<pin>` |
| `2` | Light Sensor | `pins[0]` | Analogue pin | `S4:i=<idx>;s=0;v=<pin>` |
| | | `options1[0]` | `1`=digital mode, `0`=analogue mode | `S1:…;o0=<val>;o1=0` |
| `3` | GPS Sensor | `pins[0]` | RX pin (**required** — `255` raises `GpsInvalidConfig`) | `S4:i=<idx>;s=0;v=<pin>` |
| | | `pins[1]` | TX pin (**required** — `255` raises `GpsInvalidConfig`) | `S4:i=<idx>;s=1;v=<pin>` |
| | | `options1[0]` | UART number: `1` or `2` (ESP32 only; other values default to `2`). Baud rate fixed at 9600. | `S6:i=<idx>;s=0;o=0;v=<uart>` |
| `4` | System Sensor | — | No pin or option required | — |
| `5` | Binary Presence Sensor | `pins[0]` | Sensor pin | `S4:i=<idx>;s=0;v=<pin>` |
| | | `pins[1]` | onDetected payload | `S4:i=<idx>;s=1;v=<val>` |
| | | `pins[2]` | onClear payload | `S4:i=<idx>;s=2;v=<val>` |
| | | `options1[0]` | Active state: `1`=HIGH, `0`=LOW | `S1:…;o0=<val>;o1=0` |
| | | `options1[1]` | onDetected action | `S6:i=<idx>;s=1;o=0;v=<val>` |
| | | `options2[1]` | onClear action | `S6:i=<idx>;s=1;o=1;v=<val>` |
| `6` | Voltage Sensor | `pins[0]` | Analogue input pin | `S4:i=<idx>;s=0;v=<pin>` |
| | | `options1[0]` | ADC Vref in tenths of a volt (`50`=5.0 V, `33`=3.3 V; `0`=default 5.0 V) | `S6:i=<idx>;s=0;o=0;v=<val>` |
| | | `options1[1]` | R2 in tenths of kΩ (`75`=7.5 kΩ; `0`=default 7.5 kΩ) | `S6:i=<idx>;s=1;o=0;v=<val>` |
| | | `options2[0]` | R1 in whole kΩ (`30`=30 kΩ; `0`=default 30 kΩ) | `S6:i=<idx>;s=0;o=1;v=<val>` |
| | | `options2[1]` | Low-voltage warning threshold in tenths of a volt (`114`=11.4 V; `0`=disabled) | `S6:i=<idx>;s=1;o=1;v=<val>` |
| `7` | Reed Sensor | `pins[0]` | Sensor pin | `S4:i=<idx>;s=0;v=<pin>` |
| | | `pins[1]` | Active output pin (driven HIGH while contact active; `255`=disabled) | `S4:i=<idx>;s=1;v=<pin>` |
| | | `options1[0]` | Contact type: `0`=normally open (NO), `1`=normally closed (NC) | `S1:…;o0=<val>;o1=0` |

**Voltage sensor setup example (30 kΩ / 7.5 kΩ divider, 12 V system, warn below 11.4 V):**
```
S1:i=1;t=6;o0=0;o1=0   # Add Voltage sensor (type 6)
S3:1=Battery            # Name it
S4:i=1;s=0;v=34         # Analogue pin = 34
S6:i=1;s=0;o=0;v=50     # Vref = 5.0 V (50 tenths)
S6:i=1;s=1;o=0;v=75     # R2 = 7.5 kΩ (75 tenths)
S6:i=1;s=0;o=1;v=30     # R1 = 30 kΩ
S6:i=1;s=1;o=1;v=114    # Low-voltage warn at 11.4 V (114 tenths); use 0 to disable
S5:1=1                  # Enable sensor
C0                      # Save to EEPROM — reboot to activate
```

Common sensor config errors: `Config not available`, `Invalid sensor index`, `Missing sensor index`, `Missing parameters`, `Missing name`, `Invalid pin slot`, `Invalid option slot`.

**GPS setup example (ESP32 NodeMCU-32S — Nextion on UART2, GPS remapped to UART1 on pins 25/26):**
```
S1:i=0;t=3;o0=0;o1=0   # Add GPS sensor (type 3)
S3:0=GPS                # Name it
S4:i=0;s=0;v=25         # RX pin = 25
S4:i=0;s=1;v=26         # TX pin = 26
S6:i=0;s=0;o=0;v=1      # UART number = 1 (avoids conflict with Nextion on UART2)
S5:0=1                  # Enable sensor
C0                      # Save to EEPROM — reboot to activate
```
> **Note:** If either RX or TX pin is `255` (disabled) the GPS sensor will **not** be created at boot and a `GpsInvalidConfig` warning will be raised. Both pins must be set before saving.

### Sensor Telemetry — `S7`–`S24`

| Command | Example | Purpose |
|---|---|---|
| `S7` — Temperature | `S7:v=72.5` | Temperature reading. |
| `S8` — Humidity | `S8:v=55.2` | Humidity reading. |
| `S9` — Bearing | `S9:v=128` | Compass bearing in degrees. |
| `S10` — Direction | `S10:v=NNW` | Cardinal direction string. |
| `S11` — Speed | `S11:v=3.4` | Speed reading. |
| `S12` — Compass Temp | `S12:v=23.4` | Compass module temperature. |
| `S13` — Water Level | `S13:v=3.4` | Water level reading. |
| `S14` — Water Pump Active | `S14:v=1` | Water pump state: `0`=off, `1`=on. |
| `S15` — Horn Active | `S15:v=1` | Horn state: `0`=off, `1`=on. |
| `S16` — Light Sensor | `S16:v=1` | Daytime state: `0`=night, `1`=day. See `C33` for threshold. |
| `S17` — GPS Lat/Long | `S17:lat=51.507351;lon=-0.127758` | GPS coordinates in decimal degrees (6 d.p.). |
| `S18` — GPS Altitude | `S18:v=125.50` | Altitude in metres (2 d.p.). |
| `S19` — GPS Speed | `S19:v=15.75;course=245.30;dir=NNW` | Speed km/h, course degrees (0–360), optional cardinal direction. |
| `S20` — GPS Satellites | `S20:v=8` | Number of connected satellites. |
| `S21` — GPS Distance | `S21:v=1.23` | Total distance travelled. |
| `S22` — Binary Presence | `S22:v=1;name=PIR` | Pin-change event: `v=1` detected, `v=0` clear. `name` = configured sensor name. |
| `S23` — Voltage | `S23:v=12.45;avg=12.41` | Voltage reading from the DC 0–25 V module. `v`=latest sample in volts (2 d.p.), `avg`=10-reading rolling average in volts (2 d.p.). Raises `LowVoltage` warning when `avg` drops below the configured threshold; clears when it recovers. |
| `S24` — Reed | `S24:v=1;name=Reed` | Contact state-change event: `v=1` active (detected), `v=0` clear. Sent only when the contact changes state. `name` = configured sensor name. |

### WiFi sensor commands
Route: `/api/sensor/`  
Example: `GET /api/sensor/`

---

## Timer / Scheduler Commands — `T`

Up to 20 scheduled events stored in EEPROM (6 max on platforms with < 1 KB EEPROM). Each event has a **trigger**, an optional **condition**, and an **action**.

| Command | Example | Purpose |
|---|---|---|
| `T0` — List Events | `T0` | Returns `count=<n>;s=<0,1,0,…>` — enabled state for every slot. |
| `T1` — Get Event | `T1:v=2` | Returns full detail of event at index `v` in `T2` format. Error if slot empty. |
| `T2` — Set Event | `T2:i=0;e=1;t=1,18,30,0,0;c=0,0,0,0,0;a=2,2,0,0,0` | Add/update event at index `i`. Params: `i=<idx>;e=<enabled>;t=<type,b0,b1,b2,b3>;c=<type,b0,b1,b2,b3>;a=<type,b0,b1,b2,b3>`. Each field is 5 comma-separated values (type + 4 payload bytes). Call `C0` to persist. |
| `T3` — Delete Event | `T3:v=2` | Clear event at index `v`. Call `C0` to persist. |
| `T4` — Enable / Disable | `T4:i=2;v=1` | Enable (`v=1`) or disable (`v=0`) event at index `i`. Call `C0` to persist. |
| `T5` — Clear All | `T5` | Remove all 20 events. Call `C0` to persist. |
| `T6` — Trigger Now | `T6:v=2` | Execute the action of event `v` immediately, bypassing trigger and condition. Useful for testing. |

**Trigger types (`t` first value):**

| Type | Name | Payload `b0..b3` |
|---|---|---|
| `0` | None | Never fires automatically |
| `1` | TimeOfDay | `b0`=hour (0–23), `b1`=minute (0–59) |
| `2` | Sunrise | `b0..b1`=int16 offset minutes (+after, −before) |
| `3` | Sunset | `b0..b1`=int16 offset minutes |
| `4` | Interval | `b0..b1`=uint16 interval minutes |
| `5` | DayOfWeek | `b0`=bitmask (bit0=Mon…bit6=Sun). Mon–Fri=31, weekends=96, all days=127 |
| `6` | Date | `b0`=day (1–31), `b1`=month (1–12) |

**Condition types (`c` first value):**

| Type | Name | Payload `b0..b3` |
|---|---|---|
| `0` | None | Always fires |
| `1` | TimeWindow | `b0`=start_hour, `b1`=start_min, `b2`=end_hour, `b3`=end_min |
| `2` | DayOfWeek | `b0`=bitmask (same layout as trigger DayOfWeek) |
| `3` | IsDark | True between sunset and sunrise |
| `4` | IsDaylight | True between sunrise and sunset |
| `5` | RelayIsOn | `b0`=relay index |
| `6` | RelayIsOff | `b0`=relay index |

**Action types (`a` first value):**

| Type | Name | Payload `b0..b3` |
|---|---|---|
| `0` | None | Nothing happens |
| `1` | RelayOn | `b0`=relay index |
| `2` | RelayOff | `b0`=relay index |
| `3` | RelayToggle | `b0`=relay index |
| `4` | RelayPulse | `b0`=relay index, `b1..b2`=uint16 duration seconds (little-endian) |
| `5` | AllRelaysOn | — |
| `6` | AllRelaysOff | — |
| `7` | SetPinHigh | `b0`=GPIO pin number |
| `8` | SetPinLow | `b0`=GPIO pin number |

**Examples:**
```
# At 18:30 turn Relay 3 off (relay index 2, 0-based)
T2:i=0;e=1;t=1,18,30,0,0;c=0,0,0,0,0;a=2,2,0,0,0
C0

# 10 minutes after sunset turn Relay 2 on (relay index 1, offset +10 min)
T2:i=1;e=1;t=3,10,0,0,0;c=0,0,0,0,0;a=1,1,0,0,0
C0

# At sunrise on weekdays only, toggle Relay 1 (relay index 0, Mon–Fri bitmask=31)
T2:i=2;e=1;t=2,0,0,0,0;c=2,31,0,0,0;a=3,0,0,0,0
C0

# Every 30 minutes, pulse Relay 5 for 10 seconds (relay index 4, interval=30, duration=10)
T2:i=3;e=1;t=4,30,0,0,0;c=0,0,0,0,0;a=4,4,10,0,0
C0
```

Common errors: `Index out of range`, `Missing params`, `Invalid trigger type`, `Invalid condition type`, `Invalid action type`, `Invalid enabled value (0 or 1)`, `Slot is empty`.

### WiFi timer commands
Route: `/api/timer/{command}`  
Example: `GET /api/timer/T0`

---

## Network Authentication

When network auth is enabled (`C19:e=1`), every request to `/api/*` endpoints must include authentication credentials. Two authentication methods are supported; clients may use either one.

### API Key (simple)

Include the `X-API-Key` header with the value of the configured API key:

```bash
curl -H "X-API-Key: ak-sfb-A1B2C3" http://DEVICE/api/system/F7
```

### HMAC-SHA256 (strong)

Include two headers: `X-Auth-Timestamp` (Unix epoch seconds) and `X-Auth-Signature` (lowercase hex HMAC-SHA256 of the canonical request).

**Canonical signing input format:**
```
<timestamp>\n<METHOD>\n<path>\n<body>
```

- `timestamp` — same value as `X-Auth-Timestamp`
- `METHOD` — HTTP method: `GET`, `POST`, etc.
- `path` — request path, e.g. `/api/relay/R3`
- `body` — raw request body for POST; empty string for GET

**Example (Bash):**
```bash
TS=$(date +%s)
PATH="/api/system/F7"
METHOD="GET"
BODY=""
HMAC_KEY="hk-sfb-A1B2C3"

SIGN_INPUT="${TS}\n${METHOD}\n${PATH}\n${BODY}"
SIG=$(echo -ne "$SIGN_INPUT" | openssl dgst -sha256 -hmac "$HMAC_KEY" | awk '{print $NF}')

curl -H "X-Auth-Timestamp: ${TS}" -H "X-Auth-Signature: ${SIG}" http://DEVICE${PATH}
```

### Timestamp window and clock bootstrap

- The HMAC timestamp must be within ±300 seconds (5 minutes) of the device's clock.
- **`F6` (Set DateTime) is always permitted via all transports**, even when auth is enabled, as long as the device clock has **never** been synchronized. Once time is set, `F6` requires authentication like all other commands. This prevents a deadlock where the client needs auth to set the clock but the clock is wrong, causing HMAC verification to fail.
- Clients can use an **API Key** to bootstrap the clock via `F6`, then switch to HMAC for stronger ongoing security.

### Best practices

1. **Enable auth after initial setup:** `C19:g=1` to generate per-device unique keys, then `C19:e=1` to enable.
2. **Persist changes:** Call `C0` (Save Settings) after configuring auth to survive power cycles.
3. **Synchronize the clock:** Use `F0:w=0x00;t=<timestamp>` heartbeat or `F6:v=<timestamp>` to keep the device clock accurate for HMAC.
4. **Rotate keys periodically:** `C19:k=<newkey>` and `C19:h=<newkey>` then `C0` to persist.

Common errors: `API key too long`, `HMAC key too long`.

---

## Notes

- All commands and parameters are case-sensitive.
- Commands must be sent in the exact format shown, including delimiters.
- All WiFi responses are JSON formatted.
- Changes to sensor config (`S`), external sensor config (`E`), and Nextion display config (`N`) require a **reboot** to take effect.
- Always call `C0` (Save Settings) after making config changes you want to survive a power cycle.

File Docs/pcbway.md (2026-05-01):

# PCB Sponsorship & Manufacturing

The prototype PCBs for **PowerControlHub** were kindly supported by [PCBWay](https://www.pcbway.com).

From initial upload through to delivery, the process was smooth and well handled. The engineering review helped catch potential manufacturing issues early, and communication throughout was clear and responsive.

The boards arrived well packaged and the overall build quality is excellent — clean silkscreen, solid solder mask, and consistent alignment across all layers. Assembly was completed accurately, with components correctly placed and ready for bring-up and testing.

This support has made it possible to move quickly from design to real-world validation, which is a significant step forward for the project.

---

## Prototype Boards

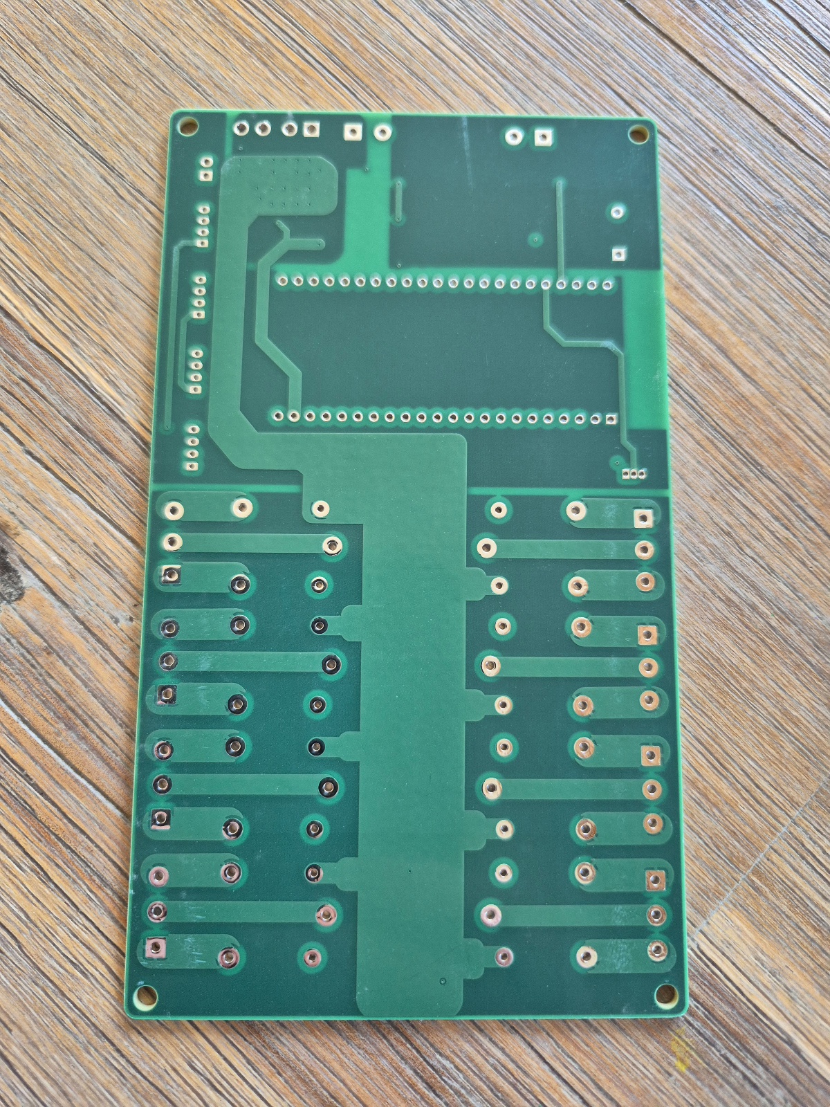
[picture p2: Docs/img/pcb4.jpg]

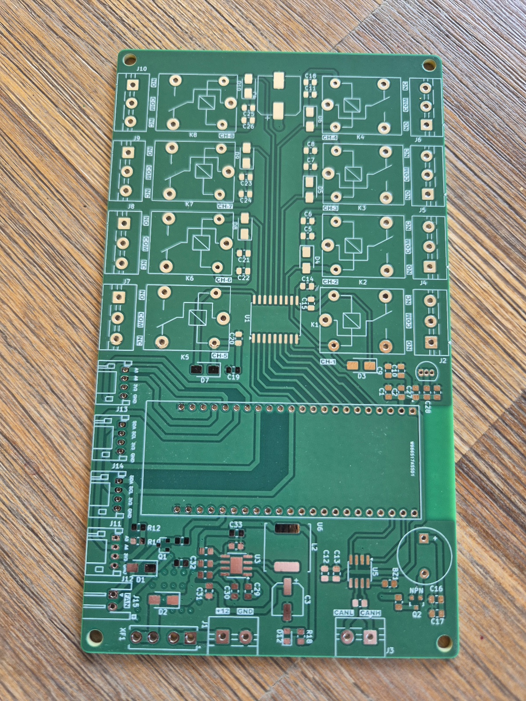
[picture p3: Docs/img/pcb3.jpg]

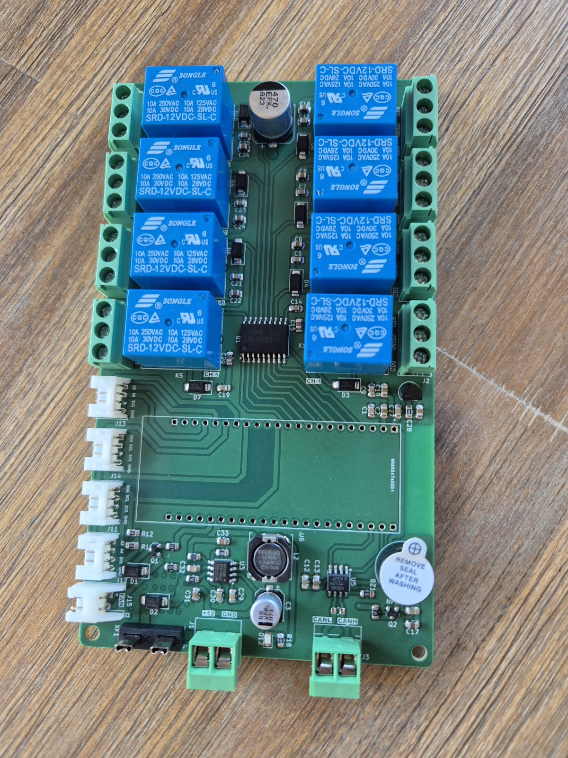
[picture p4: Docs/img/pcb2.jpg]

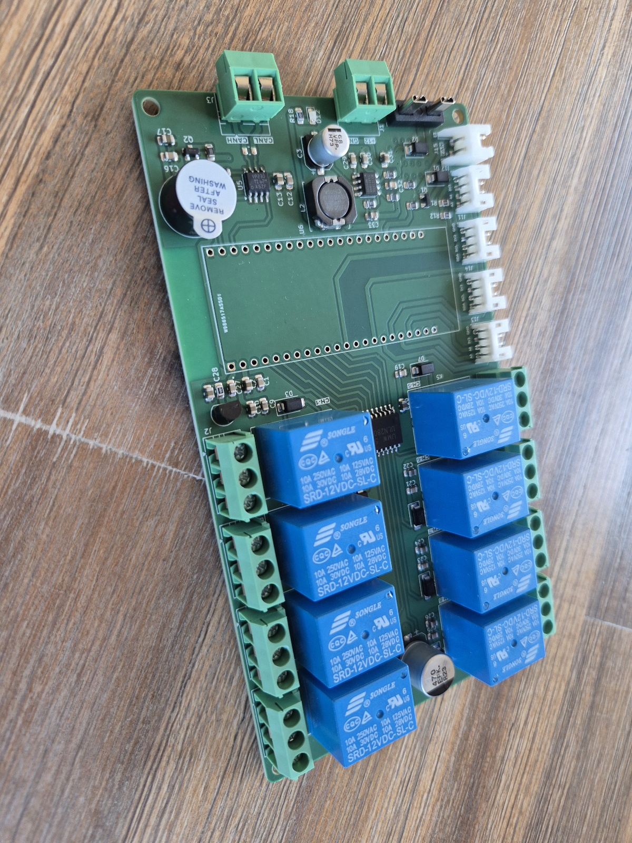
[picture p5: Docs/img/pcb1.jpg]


---

## What’s Next

These boards will be used for real-world testing, including:

- Relay control under load (12V devices: lighting, radio, horn, etc.)
- ESP32 integration and communication
- Sensor inputs and external component support
- Thermal behaviour inside an enclosed fuse box environment

Updates and findings will be added here as testing progresses.

---

## Hardware Design

The current design is based around an **8-relay configuration**, with full KiCad source files available in the repository:

If you're interested in adapting the design:

> A **4-relay variant** could be a useful smaller/cheaper option — if you’d like to design one, feel free to fork the project or submit a PR.

---

## Enclosure (Work in Progress)

A custom **3D-printed enclosure** is currently being developed to house the board and associated components.

- Designed for real-world installation (e.g. marine / vehicle use)
- Integrated mounting and cable management
- Thermal considerations (including airflow / fan support)

Preview images and STL files will be added soon.

---

## Acknowledgement

PCB prototyping and assembly support for this project was provided by [PCBWay](https://www.pcbway.com), enabling rapid iteration from concept to physical hardware.

---

*If you're working on your own hardware project and need PCB fabrication or assembly, PCBWay is well worth considering: https://www.pcbway.com*

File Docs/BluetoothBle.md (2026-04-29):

# PowerControlHub – Bluetooth BLE

This document covers the Bluetooth BLE subsystem: component responsibilities, service and characteristic reference, connection lifecycle, and how to add a new service.

---

## Availability

BLE is available on boards that define `BLUETOOTH_SUPPORT` in `Local.h`. The compile-time guard is only required at the composition layer where the concrete `BluetoothController` is instantiated — all other code uses the platform-agnostic `IBluetoothRadio` interface.

> **⚠️ Arduino Uno R4 WiFi constraint:** The ANNA-B112 (BLE) and ESP32-S3 (WiFi) modules share the same RF path. `BLUETOOTH_SUPPORT` and `WIFI_SUPPORT` **cannot both be active** on this board — a compile-time `#error` enforces this. On ESP32, both can run simultaneously.

---

## Architecture

```
IBluetoothRadio (interface)
       ↑
       │ implements
       │
BluetoothController
└── BluetoothManager
    ├── BluetoothSystemService    (system diagnostics)
    ├── BluetoothSensorService    (sensor data)
    └── BluetoothRelayService     (relay state + control)
```

### Interface Pattern

The Bluetooth subsystem uses a lightweight interface (`IBluetoothRadio`) to decouple higher-level application code from platform-specific BLE driver code. This pattern:

- **Minimizes preprocessor usage** — `#if defined(BLUETOOTH_SUPPORT)` is only required where the concrete `BluetoothController` is constructed (`PowerControlHubApp`).
- **Enables runtime control** — higher-level controllers (`ConfigController`, `SystemSensorHandler`, etc.) accept nullable `IBluetoothRadio*` pointers and use runtime null-checks instead of compile-time guards.
- **Simplifies testing** — test doubles can implement `IBluetoothRadio` without requiring Arduino/BLE libraries.
- **Mirrors Wi-Fi pattern** — follows the same architecture as `IWifiRadio` for consistency.

### `IBluetoothRadio`

Platform-agnostic interface header. Always compiled; contains no Arduino or BLE-specific includes.

Key methods:

| Method | Description |
|---|---|
| `bool isEnabled() const` | Returns whether the radio is currently enabled |
| `bool setEnabled(bool)` | Enables or disables BLE; returns true on success |
| `void applyConfig(const Config*)` | Applies runtime configuration (typically reads `config.bluetoothEnabled`) |
| `void loop()` | Per-loop processing; must be called from main loop |

### `BluetoothController`

Concrete implementation of `IBluetoothRadio`. Top-level lifecycle owner that manages the ArduinoBLE stack and all services. Constructed inside `PowerControlHubApp` only when `BLUETOOTH_SUPPORT` is defined.

**Composition:** `PowerControlHubApp` exposes a `bluetoothController()` accessor that returns `IBluetoothRadio*`:
- Returns `&_bluetoothController` when `BLUETOOTH_SUPPORT` is defined.
- Returns `nullptr` otherwise.

Higher-level code always works with the interface pointer and checks for null before calling methods.

On enable, `BluetoothController`:
1. Initialises the ArduinoBLE stack (`BLE.begin()`).
2. Constructs all three services.
3. Creates `BluetoothManager` and calls `begin("Smart Fuse Box")`.
4. Calls `notifyInitialized()` on `BluetoothSystemService`.
5. Raises `WarningType::BluetoothInitFailed` if any step fails.

### `BluetoothManager`

Coordinator — initialises the BLE stack, registers services, manages advertising, and drives the per-loop update cycle. Does not contain any domain logic.

Key behaviours:

- Calls `begin()` on each registered `BluetoothServiceBase` during setup.
- Calls `BLE.poll()` every loop iteration.
- Detects connect/disconnect transitions and automatically restarts advertising after a disconnect.
- Calls `loop(currentMillis)` on every service each iteration.

### `BluetoothServiceBase`

Abstract base class. All services inherit from it and implement:

| Method | Purpose |
|---|---|
| `begin()` | Create characteristics, initialise values, register with `BLE` |
| `getServiceUUID()` | Return the service UUID string |
| `getServiceName()` | Return a human-readable name for logging |
| `loop(uint64_t)` | Periodic work — send notifications, update cached values |
| `getCharacteristicCount()` | Return number of characteristics (for diagnostics) |
| `getBLEService()` | Return `void*` to the underlying `BLEService` (used by manager for advertising) |

---

## Connection Model

- **Single client** — only one BLE central can be connected at a time.
- **Advertising** — starts automatically on `begin()` and restarts automatically after every disconnect.
- **No pairing / bonding** — all characteristics are open; security is physical proximity.
- **Device name** — advertised as **"Power Control Hub"**.

---

## Service & Characteristic Reference

### System Service (`BluetoothSystemService`)

**Service UUID:** `4fafc201-1fb5-459e-0fcc-c5c9c331914b`

| Characteristic | UUID | Type | Properties | Update Interval | Description |
|---|---|---|---|---|---|
| Heartbeat | `beb5483e-36e1-4688-b7f5-ea07361b26a0` | `uint32` | Read, Notify | 1000 ms | Monotonically incrementing counter; confirms BLE stack is alive |
| Initialized | `beb5483e-36e1-4688-b7f5-ea07361b26a1` | `uint8` | Read, Notify | On event | `0xFF` at startup; set to `1` once the PCH firmware has finished initialising |
| Free Memory | `beb5483e-36e1-4688-b7f5-ea07361b26a2` | `uint32` | Read, Notify | 5000 ms | Available heap in bytes |
| CPU Usage | `beb5483e-36e1-4688-b7f5-ea07361b26a3` | `float` | Read, Notify | 2000 ms | CPU load as a percentage (0.0 – 100.0) |

---

### Sensor Service (`BluetoothSensorService`)

**Service UUID:** `4fafc201-1fb5-459e-1fcc-c5c9c331914b`

All characteristics update together every **1000 ms**. Values are read from `SensorCommandHandler`.

| Characteristic | UUID | Type | Properties | Description |
|---|---|---|---|---|
| Temperature | `beb5483e-36e1-4688-a7f5-ea07361b26a0` | `float` | Read, Notify | Ambient temperature in °C (DHT11) |
| Humidity | `beb5483e-36e1-4688-a7f5-ea07361b26a1` | `float` | Read, Notify | Relative humidity % (DHT11) |
| Bearing | `beb5483e-36e1-4688-a7f5-ea07361b26a2` | `float` | Read, Notify | Compass bearing in degrees |
| Compass Temp | `beb5483e-36e1-4688-a7f5-ea07361b26a3` | `float` | Read, Notify | Compass module temperature in °C |
| Speed | `beb5483e-36e1-4688-a7f5-ea07361b26a4` | `int` | Read, Notify | Speed in km/h |
| Water Level | `beb5483e-36e1-4688-a7f5-ea07361b26a5` | `int` | Read, Notify | Water level ADC rolling average |
| Water Pump Active | `beb5483e-36e1-4688-a7f5-ea07361b26a6` | `byte` | Read, Notify | `1` = pump active, `0` = inactive |

---

### Relay Service (`BluetoothRelayService`)

**Service UUID:** `4fafc201-1fb5-459e-2fcc-c5c9c331914b`

| Characteristic | UUID | Type | Properties | Description |
|---|---|---|---|---|
| Relay States | `9b9f0002-3c4a-4d9a-a6c1-11aa22bb33cc` | `byte[]` | Read, Notify | One byte per relay (length = relay count). `0` = off, `1` = on. Notified on any relay state change. |
| Relay Set | `9b9f0003-3c4a-4d9a-a6c1-11aa22bb33cc` | `byte[2]` | WriteWithoutResponse | Write `[relayIndex, state]` to change a relay. `relayIndex` is 0-based; `state` is `0` (off) or `1` (on). |

**Write example** — turn relay 2 on:

```
Write to Relay Set: 0x02 0x01
```

Relay States notifies automatically after the change is applied so clients see the updated state without polling.

---

## Enabling BLE in `Local.h`

```cpp
// Remove the trailing underscore to activate
#define BLUETOOTH_SUPPORT

// Ensure WiFi is NOT also defined on Arduino Uno R4
// #define WIFI_SUPPORT_   ← disabled
```

### Integration in Application Code

When using `IBluetoothRadio` in your components:

**Header (e.g., `SystemSensorHandler.h`):**
```cpp
#include "IBluetoothRadio.h"

class SystemSensorHandler
{
private:
    IBluetoothRadio* _bluetoothController;  // nullable interface pointer

public:
    SystemSensorHandler(MessageBus* bus, 
                       WifiController* wifi,
                       IBluetoothRadio* bluetooth,  // accept interface
                       WarningManager* warnings)
        : _bluetoothController(bluetooth)
        {
        }

    void updateStatus()
    {
        // Runtime null-check instead of #if
        if (_bluetoothController && _bluetoothController->isEnabled())
        {
            // ... use bluetooth ...
        }
    }
};
```

**Wiring (e.g., `PowerControlHub.ino`):**
```cpp
PowerControlHubApp app(&commandMgrComputer, &commandMgrLink, Relays, ConfigRelayCount);

// Fetch interface pointer (returns nullptr if not compiled in)
IBluetoothRadio* bluetooth = app.bluetoothController();

// Pass to components unconditionally
SystemSensorHandler systemSensor(app.messageBus(), 
                                app.wifiController(),
                                bluetooth,  // nullptr if BLUETOOTH_SUPPORT not defined
                                app.warningManager());
```

This pattern eliminates most `#if defined(BLUETOOTH_SUPPORT)` scattering while preserving compile-time control over driver inclusion and binary size.

---

## Configuration

BLE is enabled or disabled at runtime via the `C10` serial command or the BCP touchscreen, which sets `config.bluetoothEnabled`. `BluetoothController::applyConfig()` is called whenever the config changes and tears down or brings up the BLE stack accordingly.

```
C10:v=1   ← enable BLE
C10:v=0   ← disable BLE (requires restart to fully release hardware)
```

---

## Warnings

| Warning | Trigger | Cleared by |
|---|---|---|
| `BluetoothInitFailed` | `BLE.begin()` returns false, service `begin()` fails, or device name is empty | Manually |

---

## Adding a New BLE Service

**Step 1 – Create the service class**

Inherit from `BluetoothServiceBase` and place the file alongside the other services:

```cpp
#pragma once
#include <ArduinoBLE.h>
#include "BluetoothServiceBase.h"

class BluetoothMyService : public BluetoothServiceBase
{
public:
    static constexpr const char* ServiceUuid = "4fafc201-1fb5-459e-3fcc-c5c9c331914b";
    static constexpr const char* MyValueUuid = "beb5483e-36e1-4688-c7f5-ea07361b26a0";

    bool begin() override
    {
        _service = new BLEService(ServiceUuid);
        _charValue = new BLEIntCharacteristic(MyValueUuid, BLERead | BLENotify);
        _service->addCharacteristic(*_charValue);
        BLE.addService(*_service);
        return true;
    }

    void loop(uint64_t currentMillis) override
    {
        if (currentMillis - _lastUpdate >= 2000)
        {
            _charValue->writeValue(42);
            _lastUpdate = currentMillis;
        }
    }

    const char* getServiceUUID() const override { return ServiceUuid; }
    const char* getServiceName() const override { return "MyService"; }
    uint8_t getCharacteristicCount() const override { return 1; }
    void* getBLEService() override { return _service; }

private:
    BLEService* _service = nullptr;
    BLEIntCharacteristic* _charValue = nullptr;
    uint64_t _lastUpdate = 0;
};
```

**Step 2 – Register the service in `BluetoothController.h`**

Add a member, instantiate it in `enableInternal()`, and include it in the `_services[]` array:

```cpp
// Add member
BluetoothMyService* _myService;

// In enableInternal():
_myService = new BluetoothMyService();

_serviceCount = 4U;   // was 3
_services = new BluetoothServiceBase*[_serviceCount];
_services[0] = _systemService;
_services[1] = _sensorService;
_services[2] = _relayService;
_services[3] = _myService;   // <-- add here

// In disable(), clean up:
if (_myService)
{
    delete _myService;
    _myService = nullptr;
}
```

`BluetoothManager` will automatically call `begin()` and `loop()` on it without any further changes.

---

## Design Notes

- **Separation of concerns:** Platform/driver code (`BluetoothController`, ArduinoBLE headers) is compiled only when `BLUETOOTH_SUPPORT` is defined. Application logic (`ConfigController`, sensor handlers) depends only on `IBluetoothRadio` and compiles everywhere.
- **Minimal #if usage:** The only places requiring `#if defined(BLUETOOTH_SUPPORT)` are:
  1. `PowerControlHubApp.h` — around the concrete `BluetoothController` member declaration.
  2. `PowerControlHubApp.cpp` — around construction and initialization of `BluetoothController`.
  3. `PowerControlHubApp::bluetoothController()` — to return `nullptr` when not compiled in.
- **Testability:** Mock implementations of `IBluetoothRadio` can be injected into components for unit testing without requiring BLE hardware or libraries.

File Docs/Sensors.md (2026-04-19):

# SmartFuseBox – Sensor Support

This document describes the sensors supported by SmartFuseBox, their hardware requirements, configuration, serial command IDs, and MQTT integration.

---

## Overview

SmartFuseBox supports two categories of sensors:

| Type | Description |
|---|---|
| **Local** | Sensors physically connected to the SmartFuseBox controller board and polled directly by the main loop. |
| **Remote** | Sensors on a companion device (e.g., Boat Control Panel) that push readings to the fuse box via serial commands. |

All sensors inherit from `BaseSensor` and are registered with `SensorController`. When `MQTT_SUPPORT` is defined, each sensor exposes one or more channels that are automatically published to an MQTT broker and discovered by Home Assistant.

---

## 1. Local Sensors

### 1.1 DHT11 – Temperature & Humidity

| Property | Value |
|---|---|
| **Class** | `Dht11SensorHandler` |
| **Sensor ID** | `SensorIdList::Dht11Sensor` (`0x1`) |
| **Default Pin** | `Dht11SensorPin` (`D9`) |
| **Poll Interval** | 2 500 ms |
| **Library** | `dht11` |

**Serial Commands**

| Command | ID | Description |
|---|---|---|
| Temperature | `S0` | Current temperature in °C |
| Humidity | `S1` | Current relative humidity (%) |

**MQTT Channels**

| Channel | Slug | Device Class | Unit | Binary |
|---|---|---|---|---|
| Temperature | `temperature` | `temperature` | °C | No |
| Humidity | `humidity` | `humidity` | % | No |

**Messages Published (MessageBus)**

- `TemperatureUpdated` – fired after each successful read with the new temperature in °C.
- `HumidityUpdated` – fired after each successful read with the new humidity percentage.

**Warnings**

- `TemperatureSensorFailure` – raised when the DHT11 returns a read error; cleared automatically on the next successful read.

**JSON Status Fragment**

```json
{ "temperature": 22.5, "humidity": 60.0 }
```

---

### 1.2 Light Sensor (LDR)

| Property | Value |
|---|---|
| **Class** | `LightSensorHandler` |
| **Sensor ID** | `SensorIdList::LightSensor` (`0x2`) |
| **Digital Pin** | `LightSensorPin` (`D3`) — kept for `pinMode` initialisation |
| **Analog Pin** | `LightSensorAnalogPin` (`A1`) — primary reading source |
| **Poll Interval** | 30 000 ms |
| **Averaging** | Rolling queue of 10 readings (`LightQueueCapacity`) |
| **Debounce** | 3 consecutive agreeing readings required (`DaytimeConfirmReadings`) |

#### Detection Logic

Each poll reads the raw ADC value from the analog pin (0 – 1023) and enqueues it into a rolling `Queue<uint16_t>`. The queue automatically discards the oldest reading when full, giving a sliding average over the last 10 samples (≈ 5 minutes at the default poll interval).

The averaged value is compared against the configurable `daytimeThreshold` (default 512, stored in `Config.lightSensor.daytimeThreshold`):

- `average > threshold` → **daytime** candidate
- `average ≤ threshold` → **night** candidate

A candidate must be consistent for **3 consecutive polls** before `_isDaytime` changes state. This prevents rapid relay switching caused by transient light fluctuations at dusk and dawn.

#### Night Relay

If `Config.lightSensor.nightRelayIndex` is set to a valid relay index (0 – 7), that relay is automatically switched:

- **ON** when night is confirmed
- **OFF** when daytime is confirmed
- Driven to the correct initial state during `initialize()`

Set to `0xFF` (default) to disable automatic relay control.

#### Configuration (`Config.lightSensor`)

| Field | Type | Default | Description |
|---|---|---|---|
| `nightRelayIndex` | `uint8_t` | `0xFF` | Relay to drive on night/day transitions. `0xFF` = none |
| `daytimeThreshold` | `uint16_t` | `512` | ADC threshold (0 – 1023). Readings above this are treated as daytime |

Configure via serial commands `C32` / `C33`, or through the **Relay Settings** page on the Boat Control Panel (night relay only; threshold via serial).

**Serial Commands**

| Command | ID | Description |
|---|---|---|
| Light Sensor | `S9` | `1` = daytime, `0` = night |

**Config Commands**

| Command | ID | Format | Description |
|---|---|---|---|
| Night Relay | `C32` | `v=<0-7\|255>` | Set night relay index; `255` = none |
| Daytime Threshold | `C33` | `v=<0-1023>` | Set ADC daytime threshold |

**MQTT Channels**

| Index | Channel | Slug | Device Class | Unit | Binary |
|---|---|---|---|---|---|
| 0 | Daylight | `light` | `light` | — | Yes (`ON` / `OFF`) |
| 1 | Light Level | `light_level` | — | — | No |
| 2 | Avg Light Level | `avg_light_level` | — | — | No |

**Messages Published (MessageBus)**

- `LightSensorUpdated(bool isDayTime, uint16_t lightLevel, uint16_t averageLightLevel)` – fired on every poll with the confirmed day/night state, the raw ADC reading, and the current rolling average.

**JSON Status Fragment**

```json
{ "isDaytime": true, "lightLevel": 620, "avgLightLevel": 587 }
```

---

### 1.3 Water Level Sensor (Analog)

| Property | Value |
|---|---|
| **Class** | `WaterSensorHandler` |
| **Sensor ID** | `SensorIdList::WaterSensor` (`0x0`) |
| **Analog Pin** | `WaterSensorPin` (`A0`) |
| **Active Pin** | `WaterSensorActivePin` (`D8`) |
| **Poll Interval** | 5 000 ms (+ 10 ms stabilisation delay) |
| **Averaging** | Rolling queue of 15 readings |

The active pin is pulsed `HIGH` before each reading and pulled `LOW` immediately after to reduce electrolytic corrosion on the sensor probes.

**Serial Commands**

| Command | ID | Parameters | Description |
|---|---|---|---|
| Water Level | `S6` | `avg`, `v` | Rolling average and instantaneous ADC value |

**MQTT Channels**

| Channel | Slug | Device Class | Unit | Binary |
|---|---|---|---|---|
| Water Level | `water_level` | — | — | No |

The published MQTT value is the 15-reading rolling average.

**Messages Published (MessageBus)**

- `WaterLevelUpdated` – fired on every poll with the instantaneous reading and rolling average.

**JSON Status Fragment**

```json
{ "level": 312, "average": 305 }
```

---

### 1.4 System Diagnostics Sensor

| Property | Value |
|---|---|
| **Class** | `SystemSensorHandler` |
| **Sensor ID** | `SensorIdList::SystemSensor` (`0x4`) |
| **Poll Interval** | 2 500 ms |

This sensor does not read any hardware pin. It exposes internal device health metrics.

**MQTT Channels (7)**

| Index | Channel | Slug | Device Class | Unit | Binary |
|---|---|---|---|---|---|
| 0 | Sys Free Memory | `free_memory` | — | bytes | No |
| 1 | Sys CPU Usage | `cpu_usage` | — | % | No |
| 2 | Sys Bluetooth | `bluetooth` | `connectivity` | — | Yes (`ON` / `OFF`) |
| 3 | Sys WiFi | `wifi` | `connectivity` | — | Yes (`ON` / `OFF`) |
| 4 | Sys SD Log Size | `sd_log_size` | — | MB | No |
| 5 | Sys Warnings | `warning_count` | — | - | No |
| 6 | Sys Uptime | `uptime` | — | - | No |

**Messages Published (MessageBus)**

- `SystemMetricsUpdated` – published on each poll interval; triggers `MQTTSensorHandler` to republish all sensor states.

**JSON Status Fragment**

```json
{ "freeMemory": 2048, "cpuUsage": 12 }
```

---

## 2. Remote Sensors

Remote sensors receive data pushed from a companion device over the serial link. The data arrives as a serial command and is processed by `SensorCommandHandler`, which forwards the key-value parameters to the matching `RemoteSensor` instance.

Each `RemoteSensor` supports up to `MaxRemoteParams` (5) key-value parameters stored in RAM and served to the MQTT pipeline on demand. The internal poll interval is 60 000 ms, but updates occur whenever the matching serial command arrives rather than on a fixed timer.

### 2.1 GPS Location (Lat / Lon)

| Property | Value |
|---|---|
| **Instance** | `gpsLatLonSensor` |
| **Class** | `RemoteSensor` |
| **Sensor ID** | `SensorIdList::GpsSensor` (`0x3`) |
| **Command ID** | `S10` (`SensorGpsLatLong`) |
| **Parameter Count** | 2 (`lat`, `lon`) |

**MQTT Channels**

| Channel | Slug | Device Class | Unit | Binary |
|---|---|---|---|---|
| Latitude | `latitude` | — | ° | No |
| Longitude | `longitude` | — | ° | No |

---

## 3. Optional Sensors

The sensors below are provided as ready-to-use handlers but are not wired into `SmartFuseBox.ino` by default. Instantiate them in the sketch and add them to the `localSensors[]` array to enable them.

### 3.1 GPS – Full Local Handler (GY-GPS6MV2)

| Property | Value |
|---|---|
| **Class** | `GpsSensorHandler` |
| **Sensor ID** | `SensorIdList::GpsSensor` (`0x3`) |
| **Library** | `TinyGPS++` |
| **Poll Interval** | 10 ms (NMEA streaming) |
| **Time Sync** | Every 5 minutes from GPS UTC |
| **Stale Fix Timeout** | 30 s → raises `GpsFailure` warning |

The handler reads NMEA sentences from any `Stream*` (hardware UART, `SoftwareSerial`, etc.) and computes speed and course from the delta between consecutive fixes using the Haversine formula.

**Serial Commands**

| Command | ID | Description |
|---|---|---|
| GPS Lat/Lon | `S10` | Latitude and longitude (6 decimal places) |
| GPS Altitude | `S11` | Altitude in metres |
| GPS Speed | `S12` | Speed (km/h) and course (°) |
| GPS Satellites | `S13` | Number of satellites in view |
| Direction | `S3` | 16-point compass string (e.g. `NNE`) |
| Bearing | `S2` | Course in degrees |
| GPS Distance | `S14` | Cumulative distance travelled in km |

**Messages Published (MessageBus)** 

- `GpsLocationUpdated` – latitude and longitude on each new fix.
- `GpsAltitudeUpdated` – altitude on each new fix.
- `GpsSpeedUpdated` – speed and course on each new fix.

**Warnings**

- `GpsFailure` – raised when no valid fix has been received for 30 seconds; cleared automatically on the next valid fix.

**JSON Status Fragment**

```json
{
  "gps": {
    "lat": 51.500000,
    "lon": -0.120000,
    "alt": 15.00,
    "speed": 4.50,
    "course": 270.00,
    "sats": 8,
    "valid": true
  }
}
```

---

## 4. Sensor Infrastructure

### 4.1 Class Hierarchy

```
BaseSensorHandler  (SensorManager library)
└── BaseSensor
    ├── Dht11SensorHandler      (local – temperature & humidity)
    ├── LightSensorHandler      (local – daylight detection)
    ├── WaterSensorHandler      (local – analog water level)
    ├── SystemSensorHandler     (local – device diagnostics)
    ├── GpsSensorHandler        (local – full GPS, optional)
    └── RemoteSensor            (remote – generic serial-pushed sensor)
```

### 4.2 Adding a New Local Sensor

A local sensor is physically connected to the SmartFuseBox board and polled directly by the main loop.

**Step 1 – Add identifiers to `SystemDefinitions.h`**

Add a command ID constant and a unique `SensorIdList` entry:

```cpp
// New command ID – choose the next available Sxx number
constexpr char SensorMyThing[] = "S15";

// New SensorIdList entry
enum class SensorIdList : uint8_t
{
    // ...existing entries...
    MyThingSensor = 0x5
};
```

**Step 2 – Create the sensor handler class**

Inherit from `BaseSensor` and implement all required methods. Place the file alongside the other sensor handlers in `Shared/Sensors/`.

```cpp
#pragma once
#include "BaseSensor.h"

class MyThingSensorHandler : public BaseSensor
{
private:
    const uint8_t _sensorPin;
    int _lastValue;

protected:
    void initialize() override
    {
        pinMode(_sensorPin, INPUT);
    }

    uint64_t update() override
    {
        _lastValue = analogRead(_sensorPin);

        StringKeyValue params;
        strncpy(params.key, ValueParamName, sizeof(params.key));
        snprintf(params.value, sizeof(params.value), "%d", _lastValue);
        sendCommand(SensorMyThing, &params, 1);

        return 5000; // poll every 5 000 ms
    }

public:
    MyThingSensorHandler(BroadcastManager* broadcastManager, uint8_t sensorPin)
        : BroadcastLoggerSupport(broadcastManager), _sensorPin(sensorPin), _lastValue(0)
    {
    }

    void formatStatusJson(char* buffer, size_t size) override
    {
        snprintf(buffer, size, "\"myThing\":%d", _lastValue);
    }

    SensorIdList getSensorId() const override { return SensorIdList::MyThingSensor; }
    SensorType getSensorType() const override { return SensorType::Local; }
    const char* getSensorCommandId() const override { return SensorMyThing; }
    const char* getSensorName() const override { return "myThing"; }

#if defined(MQTT_SUPPORT)
    uint8_t getMqttChannelCount() const override { return 1; }

    MqttSensorChannel getMqttChannel(uint8_t channelIndex) const override
    {
        (void)channelIndex;
        return { "My Thing", "my_thing", nullptr, "units", false };
    }

    void getMqttValue(uint8_t channelIndex, char* buffer, size_t size) const override
    {
        (void)channelIndex;
        snprintf(buffer, size, "%d", _lastValue);
    }
#endif
};
```

**Step 3 – Register the sensor in `SmartFuseBox.ino`**

Instantiate the handler using the app accessors, then add it to `localSensors[]`:

```cpp
#include "MyThingSensorHandler.h"

MyThingSensorHandler myThingSensorHandler(app.broadcastManager(), MyThingPin);

BaseSensorHandler* localSensors[] = {
    &waterSensorHandler,
    &dht11SensorHandler,
    &lightSensorHandler,
    &systemSensorHandler,
    &gpsLatLonSensor,
    &myThingSensorHandler   // <-- add here
};
```

**Step 4 – Add a pin constant to `Local.h`** *(if needed)*

```cpp
constexpr uint8_t MyThingPin = A2;
```

---

### 4.3 Adding a New Remote Sensor

A remote sensor is driven by a companion device (e.g., Boat Control Panel). The companion sends a serial command containing the sensor values; `SensorCommandHandler` receives it and forwards the key-value parameters to the matching `RemoteSensor` instance.

**Step 1 – Add identifiers to `SystemDefinitions.h`**

```cpp
constexpr char SensorMyRemoteThing[] = "S16";

enum class SensorIdList : uint8_t
{
    // ...existing entries...
    MyRemoteSensor = 0x6
};
```

**Step 2 – Register the command in `SensorCommandHandler.cpp`**

Add the new constant to `supportedCommands()` so the serial manager routes incoming commands to the handler, and add a case in `handleCommand()` to update internal state and support query responses (zero-parameter calls):

```cpp
// In supportedCommands():
static const char* cmds[] = {
    // ...existing entries...
    SensorMyRemoteThing
};

// In handleCommand() – zero-param query block:
else if (strcmp(command, SensorMyRemoteThing) == 0)
{
    snprintf_P(buffer, sizeof(buffer), PSTR("v=%d"), _lastMyRemoteValue);
    sender->sendCommand(SensorMyRemoteThing, buffer);
    sendAckOk(sender, command);
    return true;
}

// In handleCommand() – data update block:
else if (strcmp(command, SensorMyRemoteThing) == 0)
{
    _lastMyRemoteValue = atoi(params[0].value);
}
```

Add the corresponding private field and getter/setter pair to `SensorCommandHandler.h` if the value needs to be accessible to other subsystems.

**Step 3 – Declare the remote sensor in `SmartFuseBox.ino`**

```cpp
#if defined(MQTT_SUPPORT)
MqttSensorChannel myRemoteMqttChannels[] = {
    { "My Remote Thing", "my_remote_thing", nullptr, "units", false }
};
RemoteSensor myRemoteSensor(
    SensorIdList::MyRemoteSensor,
    "MyRemote",
    SensorMyRemoteThing,
    "MyRemote",
    myRemoteMqttChannels,
    1   // parameter count
);
#else
RemoteSensor myRemoteSensor(SensorIdList::MyRemoteSensor, "MyRemote", SensorMyRemoteThing, 1);
#endif
```

**Step 4 – Add to `remoteSensors[]` and `localSensors[]`**

The sensor must appear in **both** arrays:

- `remoteSensors[]` – registers it with `SensorCommandHandler` so incoming serial commands update its stored values.
- `localSensors[]` – registers it with `SensorManager` and `SensorController` so it participates in the polling loop and MQTT publishing pipeline.

```cpp
RemoteSensor* remoteSensors[] = {
    &gpsLatLonSensor,
    &myRemoteSensor   // <-- add here
};

BaseSensorHandler* localSensors[] = {
    &waterSensorHandler,
    &dht11SensorHandler,
    &lightSensorHandler,
    &systemSensorHandler,
    &gpsLatLonSensor,
    &myRemoteSensor   // <-- add here too
};
```

### 4.4 MQTT Discovery

When `MQTT_SUPPORT` is defined and `mqtt.useHomeAssistantDiscovery` is `true` in the stored configuration, `MQTTSensorHandler` publishes a Home Assistant MQTT discovery config message for every channel on connection. State updates are published:

- On MQTT reconnect (all channels).
- When a typed `MessageBus` event fires (e.g., `TemperatureUpdated`, `WaterLevelUpdated`).
- Every 2 500 ms when `SystemMetricsUpdated` is published by `SystemSensorHandler`.

Discovery topic format: `<prefix>/<entity_type>/<device_id>/<slug>/config`  
State topic format: `home/<device_id>/sensor/<slug>/state`

### 4.5 Serial Command IDs

All sensor serial command identifiers are defined in `SystemDefinitions.h`:

| Constant | ID | Description |
|---|---|---|
| `SensorTemperature` | `S0` | Temperature (°C) |
| `SensorHumidity` | `S1` | Relative humidity (%) |
| `SensorBearing` | `S2` | GPS bearing / course (°) |
| `SensorDirection` | `S3` | Compass direction string |
| `SensorSpeed` | `S4` | Speed (km/h) |
| `SensorCompassTemp` | `S5` | Compass module temperature |
| `SensorWaterLevel` | `S6` | Water level ADC value |
| `SensorWaterPumpActive` | `S7` | Water pump active state |
| `SensorHornActive` | `S8` | Horn active state |
| `SensorLightSensor` | `S9` | Light sensor (daytime flag) |
| `SensorGpsLatLong` | `S10` | GPS latitude and longitude |
| `SensorGpsAltitude` | `S11` | GPS altitude (m) |
| `SensorGpsSpeed` | `S12` | GPS speed and course |
| `SensorGpsSatellites` | `S13` | GPS satellite count |
| `SensorGpsDistance` | `S14` | Cumulative GPS distance (km) |

## Home Assistant Automation Example

The remote GPS sensor is used so Home Assistant can set the device’s latitude and longitude, which supports correct sunrise/sunset calculations and more reliable time‑based automations.

```yaml
action:
  - service: mqtt.publish
    data:
      topic: "home/<your-device-id>>/sensor/gps/set"
      payload: >-
        lat={{ state_attr('zone.home', 'latitude') }};lon={{ state_attr('zone.home', 'longitude') }}
```

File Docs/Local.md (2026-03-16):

# SmartFuseBox – `Local.h` Configuration Reference

`Local.h` is the **single file a developer edits** to configure SmartFuseBox for their specific hardware. It controls board selection, feature flags, pin assignments, and relay count. No other file should need to change for a standard hardware setup.

> **Do not commit secrets or hardware-specific pin changes back to the main repository.** Treat `Local.h` as a local override file.

---

## Naming Convention

Throughout `Local.h`, the **trailing underscore** convention marks a define as inactive:

```cpp
#define ARDUINO_UNO_R4        // ✅ ACTIVE   — remove underscore to enable
#define ARDUINO_R4_MINIMA_    // ❌ INACTIVE — underscore means disabled
```

This lets all options stay visible in the file without needing to delete or comment anything out.

---

## 1. Board Selection

Exactly **one** board must be active. The compile-time `#error` guards will catch multiple active selections or no selection.

| Define | Board | WiFi | BLE | Notes |
|---|---|---|---|---|
| `ARDUINO_UNO_R4` | Arduino Uno R4 WiFi | ✅ | ✅ | WiFi and BLE are mutually exclusive — see [Connectivity Constraints](#connectivity-constraints) |
| `ARDUINO_R4_MINIMA` | Arduino Uno R4 Minima | ❌ | ❌ | Serial and sensor support only; `WIFI_SUPPORT` and `BLUETOOTH_SUPPORT` must not be defined |
| `ESP32_NODE_32` | ESP32 NodeMCU-32 or compatible | ✅ | ✅ | Full feature support; activating this also defines `ESP32` if the ESP32 toolchain hasn't already done so |

**To switch boards**, remove the trailing underscore from the target and add one to all others:

```cpp
// Switch from Uno R4 to ESP32
#define ARDUINO_UNO_R4_     // now inactive
#define ARDUINO_R4_MINIMA_  // still inactive
#define ESP32_NODE_32       // now active
```

---

## 2. Feature Flags

### `FUSE_BOX_CONTROLLER`

```cpp
#define FUSE_BOX_CONTROLLER
```

Includes all SmartFuseBox controller functionality — relay management, sensor pipeline, config system, serial command handlers, and connectivity subsystems. Remove this only if using the underlying components (e.g. `WifiController`, `MQTTClient`) in a completely different project.

---

### `WIFI_SUPPORT`

```cpp
#define WIFI_SUPPORT
```

Enables the `WifiController`, `WifiServer`, HTTP REST API, and all network command handlers. Only define this on boards with a WiFi radio (`ARDUINO_UNO_R4` or `ESP32_NODE_32`).

---

### `MQTT_SUPPORT`

```cpp
#if defined(WIFI_SUPPORT)
#define MQTT_SUPPORT
#endif
```

Enables the MQTT client, `MQTTController`, and all MQTT handlers including Home Assistant auto-discovery. Guarded inside `#if defined(WIFI_SUPPORT)` — MQTT requires an active WiFi connection and will not compile without it.

To disable MQTT while keeping WiFi active, comment out or remove the `#define MQTT_SUPPORT` line.

---

### `BLUETOOTH_SUPPORT`

```cpp
#define BLUETOOTH_SUPPORT_   // inactive by default
```

Enables the BLE stack (`BluetoothController`, `BluetoothManager`) and all three BLE services. Remove the trailing underscore to activate. See [Connectivity Constraints](#connectivity-constraints) for the WiFi conflict on Arduino Uno R4.

---

### `CARD_CONFIG_LOADER`

```cpp
#define CARD_CONFIG_LOADER_   // inactive by default — experimental
```

When active, the system reads `config.txt` from the SD card at boot and on card-insert, allowing configuration changes without reflashing. Requires the SD card SPI pins to be wired correctly. This feature is **experimental** and disabled by default.

---

## 3. Connectivity Constraints

On **Arduino Uno R4 WiFi**, the ANNA-B112 (BLE) and ESP32-S3 (WiFi) modules share the same RF path and **cannot run simultaneously**. A compile-time guard enforces this:

```cpp
#if defined(ARDUINO_UNO_R4) && defined(WIFI_SUPPORT) && defined(BLUETOOTH_SUPPORT)
#error "WIFI_SUPPORT and BLUETOOTH_SUPPORT cannot both be enabled on Arduino Uno R4."
#endif
```

| Board | WiFi + MQTT | BLE only | Both |
|---|---|---|---|
| Arduino Uno R4 WiFi | ✅ | ✅ | ❌ compile error |
| Arduino R4 Minima | ❌ | ❌ | ❌ |
| ESP32 NodeMCU-32 | ✅ | ✅ | ✅ |

---

## 4. Serial Initialisation Timeout

```cpp
constexpr unsigned long serialInitTimeoutMs = 300;
```

If `waitForConnection` is `true` when initialising serial, the firmware waits up to this many milliseconds for the USB serial connection before continuing with setup. Useful when debugging startup log messages that would otherwise be missed because the serial monitor opens after the board has already booted.

---

## 5. Sensor Pins

> For full per-board pin tables, ESP32 safety rules, and porting caveats see **[Docs/Pins.md](Pins.md)**.

Default pin assignments for the example sensors. Change these to match your wiring.

| Constant | Default | Connected to |
|---|---|---|
| `WaterSensorPin` | `A0` | Water level sensor analog output |
| `LightSensorAnalogPin` | `A1` | LDR analog output — read every poll and averaged over a rolling queue of 10 samples |
| `LightSensorPin` | `D3` | LDR digital pin — initialised as `INPUT`; analog reading is now the primary detection source |
| `WaterSensorActivePin` | `D8` | Water sensor power pin — pulsed `HIGH` before each reading to reduce corrosion |
| `Dht11SensorPin` | `D9` | DHT11 data line |

When adding new sensors, define additional pin constants here and use them when constructing the sensor handler in `SmartFuseBox.ino`.

---

## 6. SD Card SPI Pins

Used by `MicroSdDriver` for SD card access (logging and optional config loading).

| Constant | Default | SPI Signal |
|---|---|---|
| `SdCardCsPin` | `D10` | Chip Select |
| `SdCardMosiPin` | `D11` | MOSI |
| `SdCardMisoPin` | `D12` | MISO |
| `SdCardSckPin` | `D13` | Clock |

---

## 7. Relay Configuration

### `ConfigRelayCount`

```cpp
constexpr uint8_t ConfigRelayCount = 8;
```

The number of physical relays. Must match the number of entries in the `Relays[]` array. The system will not function with fewer than 1 relay. Set this to less than the number of defined pin constants if not all relays are populated.

### Relay Pins

```cpp
constexpr uint8_t Relay1 = D7;   // digital header
constexpr uint8_t Relay2 = D6;
constexpr uint8_t Relay3 = D5;
constexpr uint8_t Relay4 = D4;
constexpr uint8_t Relay5 = 19;   // analog header used in digital mode (A5)
constexpr uint8_t Relay6 = 18;   // A4
constexpr uint8_t Relay7 = 17;   // A3
constexpr uint8_t Relay8 = 16;   // A2
```

On Arduino Uno R4 / R4 Minima, analog header pins `A2`–`A5` are exposed as integer indices `16`–`19` when used in digital mode.

### `Relays[]` Array

```cpp
constexpr uint8_t Relays[ConfigRelayCount] = {
    Relay1, Relay2, Relay3, Relay4, Relay5, Relay6, Relay7, Relay8
};
```

The command layer addresses relays by 0-based index into this array — index 0 is relay 1, index 1 is relay 2, and so on. **Always keep `Relay1` at index 0** and ensure the array contains exactly `ConfigRelayCount` entries.

---

## 8. Compile-Time Guards

`Local.h` enforces valid configurations with `#error` directives that fail the build immediately with a clear message:

| Guard | Condition | Error message |
|---|---|---|
| WiFi + BLE on R4 | `ARDUINO_UNO_R4 && WIFI_SUPPORT && BLUETOOTH_SUPPORT` | "WIFI_SUPPORT and BLUETOOTH_SUPPORT cannot both be enabled on Arduino Uno R4." |
| Multiple boards | e.g. `ARDUINO_UNO_R4 && ESP32` | "Multiple board types defined." |
| No board | None of the three boards active | "No board type defined." |

---

## 9. Common Configuration Recipes

### Arduino Uno R4 WiFi with MQTT (default)

```cpp
#define ARDUINO_UNO_R4
#define ARDUINO_R4_MINIMA_
#define ESP32_NODE_32_
#define FUSE_BOX_CONTROLLER
#define WIFI_SUPPORT
// MQTT_SUPPORT is auto-enabled inside the WIFI_SUPPORT guard
#define BLUETOOTH_SUPPORT_    // inactive — mutually exclusive with WiFi on R4
#define CARD_CONFIG_LOADER_   // inactive
```

### Arduino Uno R4 WiFi with BLE (no MQTT)

```cpp
#define ARDUINO_UNO_R4
#define ARDUINO_R4_MINIMA_
#define ESP32_NODE_32_
#define FUSE_BOX_CONTROLLER
// #define WIFI_SUPPORT     ← comment out entirely
#define BLUETOOTH_SUPPORT   // active — WiFi is off so no conflict
#define CARD_CONFIG_LOADER_
```

### Arduino Uno R4 Minima (sensors + serial only)

```cpp
#define ARDUINO_UNO_R4_        // inactive
#define ARDUINO_R4_MINIMA      // active
#define ESP32_NODE_32_         // inactive
#define FUSE_BOX_CONTROLLER
// WIFI_SUPPORT, MQTT_SUPPORT, BLUETOOTH_SUPPORT must all be absent or inactive
#define CARD_CONFIG_LOADER_
```

### ESP32 (WiFi + BLE + MQTT)

```cpp
#define ARDUINO_UNO_R4_
#define ARDUINO_R4_MINIMA_
#define ESP32_NODE_32         // active
#define FUSE_BOX_CONTROLLER
#define WIFI_SUPPORT
// MQTT_SUPPORT auto-enabled
#define BLUETOOTH_SUPPORT     // also active — ESP32 supports both simultaneously
#define CARD_CONFIG_LOADER_
```

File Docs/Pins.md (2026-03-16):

# SmartFuseBox – Pin Assignment Reference

This document covers the pin assignments defined in `Local.h` for each supported board, the hardware constraints that govern which pins are safe to use, and the caveats discovered during bring-up. Read this before wiring a new board or porting to a new target.

---

## Contents

1. [Arduino Uno R4 / R4 Minima](#1-arduino-uno-r4--r4-minima)
2. [ESP32 NodeMCU-32S](#2-esp32-nodemcu-32s)
3. [ESP32 Pin Safety Rules](#3-esp32-pin-safety-rules)
4. [Pins to Avoid on ESP32](#4-pins-to-avoid-on-esp32)
5. [Porting Caveats](#5-porting-caveats)

---

## 1. Arduino Uno R4 / R4 Minima

These are the original reference pin assignments. All digital header pins (D3–D9) and analog header pins used in digital mode (A2–A5 = indices 16–19) are safe for relay and sensor use.

### Relay Pins

| Constant  | Pin | Header location |
|---|-----|---|
| `Relay1`  | 7 | Digital D7 |
| `Relay2`  | 6 | Digital D6 |
| `Relay3`  | 5 | Digital D5 |
| `Relay4`  | 4 | Digital D4 |
| `Relay5`  | 19  | Analog A5 (digital mode) |
| `Relay6`  | 18  | Analog A4 (digital mode) |
| `Relay7`  | 17  | Analog A3 (digital mode) |
| `Relay8`  | 16  | Analog A2 (digital mode) |

### Sensor Pins

| Constant | Pin | Notes |
|---|-----|---|
| `WaterSensorPin` | A0  | Analog read |
| `WaterSensorActivePin`| 8 | Pulsed HIGH before each reading (anti-corrosion) |
| `Dht11SensorPin` | 9 | DHT11 one-wire data |
| `LightSensorPin` | 3 | Digital (on/off) mode by default |

### SD Card SPI Pins

| Constant | Pin | SPI Signal  |
|---|-----|---|
| `SdCardCsPin` | 10  | Chip Select |
| `SdCardMosiPin`  | 11  | MOSI |
| `SdCardMisoPin`  | 12  | MISO |
| `SdCardSckPin` | 13  | Clock |

---

## 2. ESP32 NodeMCU-32S

Because ESP32 GPIO numbers do not map to Arduino pin names the same way as R4, all pin assignments are wrapped in `#if defined(ESP32)` / `#else` blocks inside `Local.h`. The values below are safe defaults — **adjust them to match your physical relay board wiring** before deploying.

### Relay Pins

| Constant  | Default GPIO | Notes |
|---|---|---|
| `Relay1`  | 32 | Safe output pin |
| `Relay2`  | 33 | Safe output pin |
| `Relay3`  | 25 | Safe output pin; also DAC1 |
| `Relay4`  | 26 | Safe output pin; also DAC2 |
| `Relay5`  | 27 | Safe output pin |
| `Relay6`  | 14 | Safe output pin; boot log on reset — harmless in normal operation |
| `Relay7`  | 12 | Safe output pin; **must be LOW at boot** (strapping pin — see [§4](#4-pins-to-avoid-on-esp32)) |
| `Relay8`  | 13 | Safe output pin |

> ⚠️ GPIO12 is a strapping pin. If your relay board pulls it HIGH at power-on, the ESP32 will attempt to boot from a 1.8 V flash voltage and fail. Use GPIO13 or another safe pin as a first choice if this is a concern.

### Sensor Pins

| Constant | Default GPIO | Notes |
|---|---|---|
| `WaterSensorPin` | 34 | Input-only ADC1; no internal pull-up/down available |
| `WaterSensorActivePin` | 35 | Input-only ADC1; no internal pull-up/down available |
| `Dht11SensorPin` | 4 | Bidirectional GPIO, safe for one-wire |
| `LightSensorPin` | 36 | Input-only ADC1 (GPIO36 / SVP); analog mode default |

> ℹ️ `WaterSensorPin` and `WaterSensorActivePin` are assigned to input-only pins (34, 35) because the water sensor only needs to be read, not driven. If `WaterSensorActivePin` needs to be driven HIGH to power the sensor, move it to a bidirectional GPIO such as 21 or 22.

### SD Card SPI Pins

Uses ESP32 VSPI (SPI2) default bus pins.

| Constant | Default GPIO | SPI Signal  |
|---|---|---|
| `SdCardCsPin` | 5 | Chip Select |
| `SdCardMosiPin`  | 23 | MOSI |
| `SdCardMisoPin`  | 19 | MISO |
| `SdCardSckPin` | 18 | Clock |

---

## 3. ESP32 Pin Safety Rules

The ESP32 has several categories of pins that must not be freely assigned to peripherals:

### ADC2 Conflict with WiFi

GPIO pins connected to the ADC2 peripheral **cannot be used for analog reads while WiFi is active**. The WiFi driver takes exclusive control of ADC2. The affected pins are:

`GPIO0, GPIO2, GPIO4, GPIO12, GPIO13, GPIO14, GPIO15, GPIO25, GPIO26, GPIO27`

If you assign a sensor pin to one of these and read it while WiFi is running, the read will return garbage or cause a crash. Use **ADC1 pins** (GPIO32–GPIO39) for sensors wherever possible.

### Input-Only Pins

GPIO34, 35, 36 (SVP), and 39 (SVN) are **input-only** — they have no output driver and no internal pull-up or pull-down resistor. They are fine for reading sensors but **cannot** be used as relay outputs or to drive any load.

---

## 4. Pins to Avoid on ESP32

| GPIO(s) | Reason |
|---|---|
| **6–11** | ⛔ **Internal SPI flash bus.** Calling `pinMode()` or `digitalWrite()` on any of these pins will immediately crash the chip (hard fault → WDT reset). This is the most dangerous mistake when porting from R4, where pins 6–11 are ordinary digital I/O. |
| **0** | ⚠️ Strapping pin — must be HIGH at boot for normal flash boot. Avoid as a relay output. |
| **2** | ⚠️ Strapping pin — connected to on-board LED on many NodeMCU-32S boards; must be LOW at boot on some modules. |
| **12** | ⚠️ Strapping pin — sets flash voltage at boot. If held HIGH at power-on, the chip attempts to boot at 1.8 V and will not start. Relay boards that drive outputs HIGH at idle are incompatible with this pin. |
| **15** | ⚠️ Strapping pin — controls boot log output on UART0. Generally safe after boot but best avoided if stability is critical. |
| **1, 3** | UART0 TX/RX — used by `Serial` (the USB-UART debug port). Do not reassign unless `Serial` is not in use. |
| **34–39**  | Input-only — cannot drive outputs. Safe for analog/digital sensor reads only. |

---

## 5. Porting Caveats

### Flash SPI pins crash the ESP32 immediately

**Symptom:** Continuous `TG1WDT_SYS_RESET` reboot loop with no user output, approximately 1 second after `setup()` is entered.

**Cause:** The original `Local.h` used R4 pin numbers directly with no `#if defined(ESP32)` guard. `Relay2 = 6` mapped directly to ESP32 GPIO6, which is the internal flash SPI clock line. The first call to `pinMode(6, OUTPUT)` in `RelayController::setup()` corrupted the flash bus and caused an immediate hard fault.

**Fix:** All pin constants in `Local.h` are now wrapped in `#if defined(ESP32)` / `#else` blocks. The ESP32 block uses GPIO numbers that are verified safe for output use (32, 33, 25, 26, 27, 14, 12, 13).

**Key lesson:** On R4, pins 4–9 are ordinary digital I/O. On ESP32, pins 6–11 are the internal flash SPI bus. These ranges overlap. **Never share a pin number between an R4 and ESP32 build without a platform guard.**

---
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

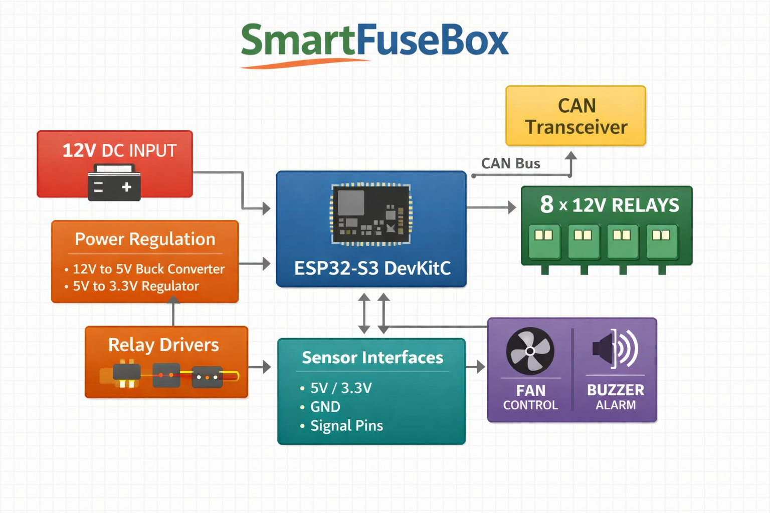
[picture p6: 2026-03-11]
Docs/img/Electrical Overview.png

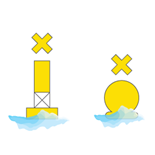
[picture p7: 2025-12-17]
NextionControlPanel/src/Markers/SpecialMarker.png

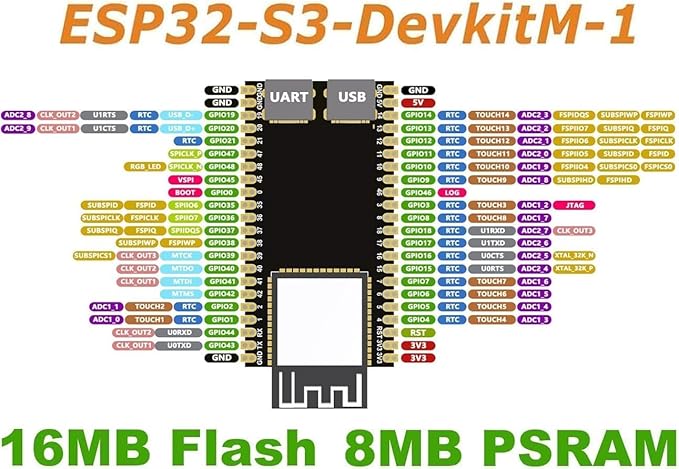
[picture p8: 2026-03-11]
Docs/img/DevKitM-1Pins.jpg

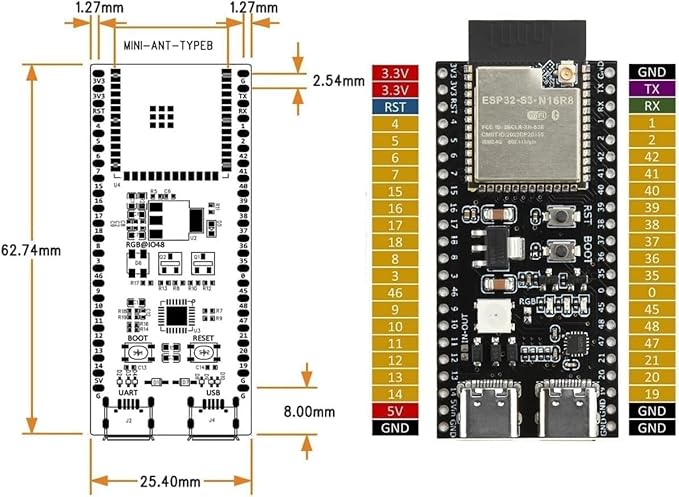
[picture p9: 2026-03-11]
Docs/img/Esp32Pins.jpg

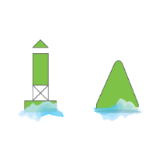
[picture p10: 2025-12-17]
NextionControlPanel/src/Markers/LateralStarboard.png

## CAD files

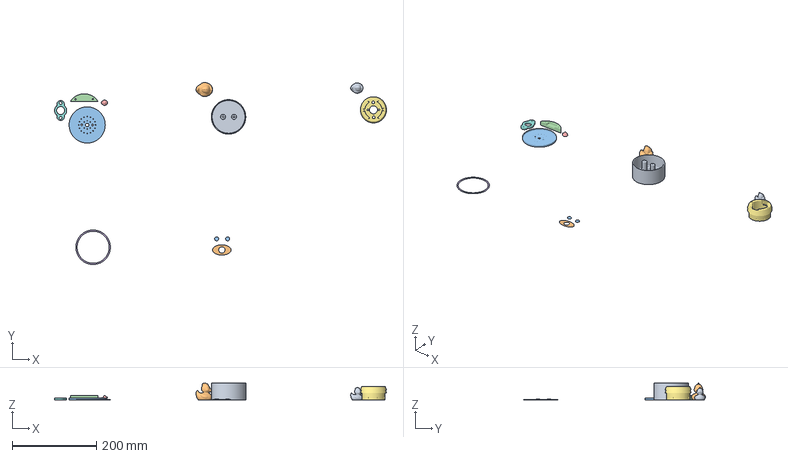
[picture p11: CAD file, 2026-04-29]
3dPrintedFiles/Boat Sensor Housing.3mf
789.8 x 433.1 x 40.0 mm
just a duck.stl x 3
Boat Sensor Housing GPS Base Plate.stl
Boat Sensor Housing GPS Grip.stl
Boat Sensor Housing GPS Seal.stl
Boat Sensor Housing GPS Base Pole.stl
Boat Sensor Housing GPS Underside Plate.stl
Boat Sensor Housing GPS Main Housing.stl
Boat Sensor Housing GPS Main Housing Cover 1.stl
Boat Sensor Housing GPS Main Housing Cover 2.stl

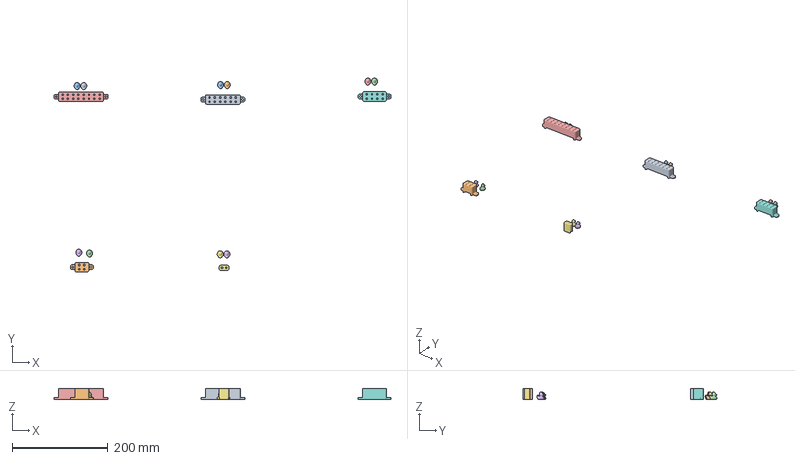
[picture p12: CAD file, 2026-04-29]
3dPrintedFiles/Wire Crimp Fuse Connector.3mf
702.8 x 404.1 x 22.0 mm
just a duck.stl x 10
Wire Crimp Fuse Connector x2.stl
Wire Crimp Fuse Connector.stl
Wire Crimp Fuse Connector x1.stl
Wire Crimp Fuse Connector x4.stl
Wire Crimp Fuse Connector x6.stl

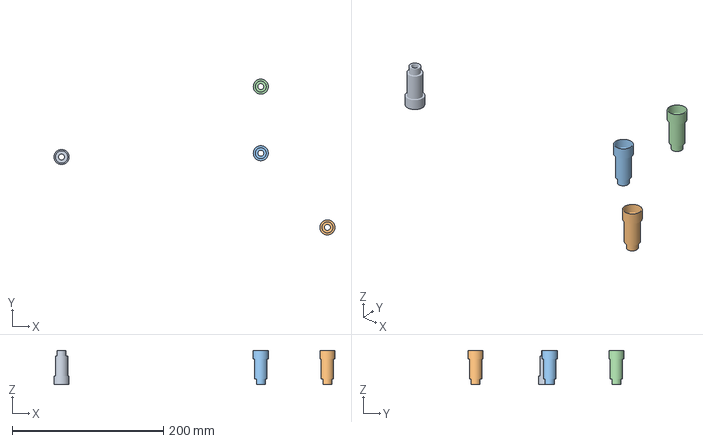
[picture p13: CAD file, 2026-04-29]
3dPrintedFiles/Aviation Connector Covers.3mf
371.2 x 206.0 x 45.0 mm
Boat Sensor Housing Aviation Cover.stl x 4

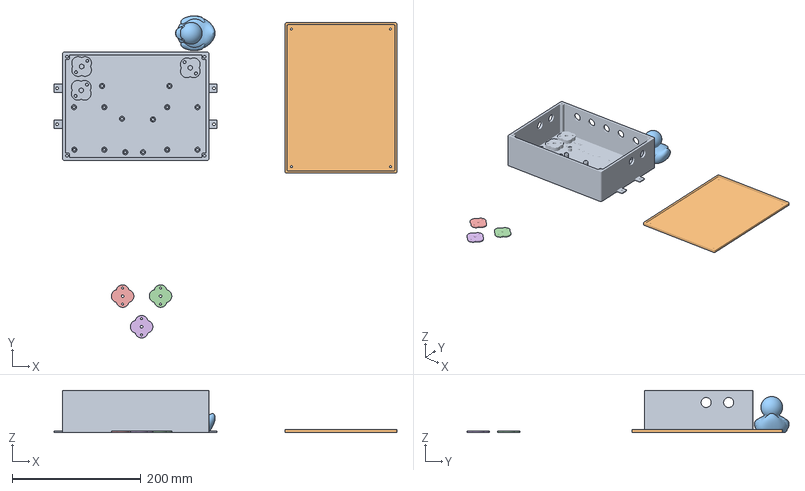
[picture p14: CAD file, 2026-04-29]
3dPrintedFiles/BoatFuseBox.3mf
533.1 x 500.7 x 66.0 mm
Static Panel Box Connector.stl
Static Panel Box Connector Lid.stl
RubberDuck+Tiny.stl
Static Panel Box Connector Top (1).stl x 3

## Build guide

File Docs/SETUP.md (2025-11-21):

# SmartFuseBox Setup Guide

This guide covers everything you need to know to successfully check out and build the SmartFuseBox repository on Windows.

---

## 📋 Prerequisites

### Required Software
- **Git for Windows** (with symbolic link support enabled)
- **Arduino IDE** (1.8.19+ or Arduino IDE 2.x)
- **Windows 10/11** (with Developer Mode enabled OR administrator privileges)

### Required Hardware
- **Arduino Mega 2560** (Control Panel)
- **Arduino Uno R4** (Fuse Box)
- **Nextion Display** (3.5" or 5" NX4832T035 recommended)
- See [BOM.md](BOM.md) for complete hardware list

---

## ⚙️ Windows Configuration for Symbolic Links

**IMPORTANT:** This repository uses symbolic links to share code between `BoatControlPanel` and `SmartFuseBox` projects. You must configure Windows to handle them properly.

### Option 1: Enable Developer Mode (Recommended)
1. Open **Settings** → **Update & Security** → **For developers**
2. Enable **Developer Mode**
3. Restart your computer
4. Git will now automatically create symbolic links during clone

### Option 2: Use Administrator Privileges
If you cannot enable Developer Mode:
1. Clone the repository normally (symlinks will appear as text files)
2. Run the `SymLinks.bat` scripts manually (see below)

---

## 📥 Cloning the Repository

### With Developer Mode Enabled

Git will automatically create symbolic links during the clone process.

### Without Developer Mode (Admin Required)

After cloning, you **must** manually create symbolic links:

#### For BoatControlPanel:
*(Right-click → "Run as administrator")*

#### For SmartFuseBox:
*(Right-click → "Run as administrator")*

---

## 🔧 Git Configuration

### Enable Symlink Support Globally

### Verify Symlinks After Clone

### If Symlinks Are Missing
1. Delete the text files:
2. Run `SymLinks.bat` as administrator:

---

## 📚 Required Arduino Libraries

Install these libraries via **Arduino IDE Library Manager**:

### Third-Party Libraries
- **SerialCommandManager** (by Si Carter)
- **NextionControl** (custom library - see `NextionControl` folder)
- **DHT sensor library** (by Adafruit)
- **QMC5883LCompass** (for magnetic compass sensor)

### Installation
1. Open Arduino IDE
2. Go to **Sketch** → **Include Library** → **Manage Libraries**
3. Search and install each library

### Custom Libraries
If `NextionControl` is not in the Library Manager:
1. Copy `NextionControl` folder to your Arduino `libraries` directory
2. Restart Arduino IDE

---

## 🏗️ Building the Projects

### BoatControlPanel (Arduino Mega 2560)
1. Open `BoatControlPanel/BoatControlPanel.ino` in Arduino IDE
2. Select **Board**: Arduino Mega 2560
3. Select **Port**: (your COM port)
4. Click **Upload**

### SmartFuseBox (Arduino Uno R4)
1. Open `SmartFuseBox/SmartFuseBox.ino` in Arduino IDE
2. Select **Board**: Arduino Uno R4 WiFi (or R4 Minima)
3. Select **Port**: (your COM port)
4. Click **Upload**

---

## 🔍 Verifying Setup

### Check Symlinks
Run this in `BoatControlPanel` or `SmartFuseBox`:

You should see entries like:

If you see regular text files, symlinks weren't created correctly.

### Check Arduino Compilation
Both projects should compile without errors. Common issues:

- **Missing library errors**: Install required libraries
- **File not found errors**: Symlinks weren't created properly
- **Multiple definition errors**: Ensure you're not including `.cpp` files

---

## 🚨 Troubleshooting

### Symlinks Appear as Text Files After Clone
**Cause**: Git is not configured to create symlinks, or you lack permissions.

**Fix**:
1. Enable Developer Mode (see above)
2. Re-clone the repository OR run `SymLinks.bat` manually

### "ERROR: Failed to create symlink" When Running SymLinks.bat
**Cause**: Not running with administrator privileges.

**Fix**: Right-click `SymLinks.bat` → **Run as administrator**

### Symlinks Disappear After Git Pull
**Cause**: `core.symlinks` is set to `false`.

**Fix**:

### Files Show as Modified in Git After Creating Symlinks
**Cause**: Git thinks symlinks are regular files.

**Fix**:

---

## 📖 Additional Documentation

- [README.md](README.md) - Project overview and features
- [Commands.md](Commands.md) - Serial command protocol reference
- [BOM.md](BOM.md) - Complete bill of materials
- [ExternalUpdatePattern.md](ExternalUpdatePattern.md) - Display page update architecture

---

## 🤝 Contributing

When making changes to shared files:
1. Edit files in the `Shared/` directory only
2. Do **NOT** commit or modify symlinked files directly
3. Test changes in both `BoatControlPanel` and `SmartFuseBox`

---

## 📜 License

GNU General Public License v3.0 (GPLv3) — see [LICENSE](LICENSE) for details.

---

## ❓ Getting Help

If you encounter issues:
1. Check this setup guide thoroughly
2. Review the [README.md](README.md) for project context
3. Open an issue on GitHub with:
   - Your Git configuration (`git config --list | grep symlinks`)
   - Windows version and Developer Mode status
   - Error messages from `SymLinks.bat` or Arduino IDE

---

**Happy building! ⚡🚤**

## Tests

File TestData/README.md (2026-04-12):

# Test Data Files - Quick Reference

## File Locations

All test data files are located in: `C:\GitProjects\SFB\SmartFuseBox\TestData\`

## Files

### 1. config-commands.txt
**Purpose:** Configuration template for SmartFuseBox devices

**Usage:**
```bash
# Serial
SmartFuseSync Config Update -f:"<path>\config-commands.txt" -p:COM3 -w:"SSID" -x:"Pass"

# WiFi
SmartFuseSync WifiConfig Update -f:"<path>\config-commands.txt" -i:"192.168.1.100" -w:"SSID" -x:"Pass"
```

**Contains:**
- System identification (boat name, MMSI, call sign, home port)
- Vessel configuration (type, timezone)
- WiFi settings (with placeholders)
- Bluetooth settings
- MQTT configuration
- Relay naming and configuration
- SPI/SD card settings
- LED configuration
- Control panel tones
- Sensor configuration examples

**Important:**
- WiFi credentials use placeholders: `{{WIFI_SSID}}` and `{{WIFI_PASSWORD}}`
- Must provide `-w` and `-x` parameters when running
- Edit this file to match your device configuration
- Safe to commit to Git (no real credentials)

### 2. test-commands.txt
**Purpose:** Automated test suite for validating device responses via Serial

**Usage:**
```bash
# Serial only
SmartFuseSync Config RunTests -f:"<path>\test-commands.txt" -p:COM3
```

**Contains:**
- System command tests (F0-F13)
- Configuration command tests (C0-C33)
- MQTT command tests (M0-M9)
- Relay command tests (R0-R11)
- Sensor command tests (S0-S6)
- Warning command tests (W1-W4)
- Sound signal tests (H0-H12)
- Timer/scheduler tests (T0-T6)
- Error response tests

**Format:**
```
COMMAND -> EXPECTED_RESPONSE
COMMAND -> RESPONSE1 | RESPONSE2   # Multiple valid responses
COMMAND -> ACK:CMD=*               # Wildcard matching
```

**Important:**
- Responses are pattern-matched
- `*` matches any value
- `|` separates multiple valid responses
- Update expectations if firmware changes

### 3. test-commands-wifi.txt
**Purpose:** Automated test suite for WiFi HTTP API endpoints

**Usage:**
```bash
# WiFi only
SmartFuseSync WifiConfig RunTests -f:"<path>\test-commands-wifi.txt" -i:"192.168.1.100"
```

**Contains:**
- All HTTP API endpoints (GET and POST)
- System commands via /api/system
- Relay commands via /api/relay
- Configuration via /api/config (excluding C11-C17 WiFi settings)
- Sensor queries via /api/sensor
- Warning commands via /api/warning
- Sound signals via /api/sound
- Timer/scheduler via /api/timer
- Error response tests
- Invalid endpoint tests

**Format:**
```
METHOD /endpoint [body] -> JSON_PATTERN
GET /api/relay/R2 -> {"relays":*}
POST /api/config/C3 Test Boat -> {"success":true}
GET /api/invalid -> {"error":*}
```

**Important:**
- Tests actual HTTP endpoints (GET/POST)
- JSON response validation
- `*` wildcards work in JSON patterns
- `|` separates multiple valid JSON responses
- Auto-detects format (WiFi vs Serial)
- **WiFi config commands (C11-C17) are excluded** - these would disconnect the device during testing

## Creating Custom Test Files

### Custom Configuration File

1. Copy `config-commands.txt` to a new file
2. Edit configuration values
3. Keep WiFi placeholders or use actual values
4. Run with your custom file:
   ```bash
   SmartFuseSync config update -f MyConfig.txt -p COM3 -w "SSID" -x "Pass"
   ```

### Custom Test File

1. Create new file with `.txt` extension
2. Use format: `COMMAND -> EXPECTED_RESPONSE`
3. Add comments with `#`
4. Run tests:
   ```bash
   SmartFuseSync config runtests -f MyTests.txt -p COM3
   ```

Example custom test file:
```
# My Custom Tests
# Test basic relay control
R3:0=1 -> ACK:R3=ok
R4:0 -> R4:0=1

# Test MQTT connection
M8 -> M8:v=1
```

## Best Practices

### For Configuration Files
- ✅ Use placeholders for credentials
- ✅ Add comments explaining settings
- ✅ Group related commands
- ✅ End with `C0` to save to EEPROM
- ❌ Never commit real WiFi passwords

### For Test Files
- ✅ Group tests by command category
- ✅ Test both success and error cases
- ✅ Use wildcards for variable data
- ✅ Add descriptive comments
- ✅ Test edge cases (min/max values)

### Security
**Never commit these to Git:**
- `*-local.txt` (local configuration variants)
- `*.bat` files with credentials
- Any file with real passwords

**Add to `.gitignore`:**
```
TestData/*-local.txt
TestData/*.bat
config-local.txt
```

## Updating Test Files

When Commands.md changes:

1. Review new/changed commands
2. Add test cases to `test-commands.txt`
3. Update expected responses if needed
4. Run tests to validate
5. Update `config-commands.txt` if needed

## Quick Commands

```bash
# Update device (Serial with credentials)
SmartFuseSync config update -f TestData/config-commands.txt -p COM3 -w "MyWiFi" -x "MyPass"

# Run all tests (Serial)
SmartFuseSync config runtests -f TestData/test-commands.txt -p COM3

# Update device (WiFi with credentials)
SmartFuseSync wificonfig update -f TestData/config-commands.txt -i 192.168.1.100 -w "MyWiFi" -x "MyPass"

# Run all tests (WiFi)
SmartFuseSync wificonfig runtests -f TestData/test-commands.txt -i 192.168.1.100

# List available ports
SmartFuseSync config listports

# Test connection (Serial)
SmartFuseSync config test -p COM3

# Test connection (WiFi)
SmartFuseSync wificonfig test -i 192.168.1.100
```

## File Format Reference

### Comment Syntax
```
# This is a comment
# Comments can be anywhere
# Blank lines are ignored
```

### Configuration Commands
```
COMMAND:parameters
C11:v=1
M0:v=1
M1:192.168.50.110
```

### Test Commands
```
COMMAND -> EXPECTED
C11:v=1 -> ACK:C11=ok
F2 -> F2:v=*
M3 -> M3:v=*|M3:v=Username
```

### Placeholders
```
C13:{{WIFI_SSID}}
C14:{{WIFI_PASSWORD}}
```

Replaced via CLI:
```bash
-w "ActualSSID" -x "ActualPassword"
```

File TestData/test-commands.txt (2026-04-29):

# Smart Fuse Box Test Commands
# Lines starting with # are comments
# Format: COMMAND -> EXPECTED_RESPONSE
# Use | to separate multiple valid responses
# Use * as wildcard for variable content

# ============================================================
# SYSTEM COMMANDS - Query Commands
# ============================================================
F2 -> ACK:F2=ok:v=*
F3 -> ACK:F3=ok:v=*
F4 -> ACK:F4=ok:v=*
F5 -> ACK:F5=ok:v=*
F7 -> ACK:F7=ok:v=*
F8 -> ACK:F8=ok:v=*
F9 -> ACK:F9=ok:v=*
F11 -> ACK:F11=ok:v=*

# RTC Diagnostic - returns status message
F10 -> ACK:F10=ok:*

# OTA Status (SFB only, requires WiFi)
# F13 -> ACK:F13:v=*;av=*;s=*;auto=*

# ============================================================
# SYSTEM COMMANDS - Set Commands
# ============================================================
# Set DateTime (Unix timestamp)
F6:v=1733328600 -> ACK:F6=ok:v=*

# Heartbeat (SFB sends warnings only)
F0:w=0x00 -> ACK:F0=ok

# ============================================================
# CONFIGURATION COMMANDS - Boat Info
# ============================================================
C3:Test Boat -> ACK:C3=ok:*
C3:name=Test Boat 2 -> ACK:C3=ok:*
C21:123456789 -> ACK:C21=ok|ACK:C21=Invalid parameter:*
C22:TEST123 -> ACK:C22=ok:*
C23:Test Port -> ACK:C23=ok:*

# ============================================================
# CONFIGURATION COMMANDS - Vessel Settings
# ============================================================
# Vessel Type: 0=Motor, 1=Sail, 2=Fishing, 3=Yacht
C7:v=0 -> ACK:C7=ok:*
C7:v=1 -> ACK:C7=ok:*
C7:v=2 -> ACK:C7=ok:*
C7:v=3 -> ACK:C7=ok:*

# Timezone offset
C20:v=-5 -> ACK:C20=ok:*
C20:v=0 -> ACK:C20=ok:*
C20:v=8 -> ACK:C20=ok:*

# Sound delay
C9:v=100 -> ACK:C9=ok:*
C9:v=255 -> ACK:C9=ok:*

# ============================================================
# CONFIGURATION COMMANDS - WiFi Settings (PCH)
# ============================================================
C11:v=0 -> ACK:C11=ok:*
C11:v=1 -> ACK:C11=ok:*
C12:v=0 -> ACK:C12=ok:*
C12:v=1 -> ACK:C12=ok:*
C13:TestSSID -> ACK:C13=ok:*
C14:TestPassword -> ACK:C14=ok:*
C15:v=80 -> ACK:C15=ok:*
C15:v=8080 -> ACK:C15=ok:*
C17:192.168.4.1 -> ACK:C17=ok:*

# ============================================================
# CONFIGURATION COMMANDS - Bluetooth Settings (PCH)
# ============================================================
C10:v=0 -> ACK:C10=ok:*|ACK:C10=Bluetooth init failed:*
C10:v=1 -> ACK:C10=ok:*|ACK:C10=Bluetooth init failed:*

# ============================================================
# CONFIGURATION COMMANDS - SPI Settings
# ============================================================
C4:sck=12;mosi=11;miso=13 -> ACK:C4=ok:*
C31:v=4 -> ACK:C31=ok:*
C31:v=8 -> ACK:C31=ok:*
C31:v=12 -> ACK:C31=ok:*

# ============================================================
# CONFIGURATION COMMANDS - LED Settings
# ============================================================
C24:t=0;c=0;r=255;g=50;b=213 -> ACK:C24=ok:*
C24:t=1;c=1;r=100;g=0;b=0 -> ACK:C24=ok:*
C25:t=0;b=75 -> ACK:C25=ok:*
C25:t=1;b=30 -> ACK:C25=ok:*
C26:v=1 -> ACK:C26=ok:*
C26:v=0 -> ACK:C26=ok:*
C27:g=1;w=1;s=1 -> ACK:C27=ok:*
C27:g=0;w=0;s=0 -> ACK:C27=ok:*

# ============================================================
# CONFIGURATION COMMANDS - Control Panel Tones
# ============================================================
C28:t=0;h=400;d=500;p=0;r=0 -> ACK:C28=ok:*
C28:t=1;h=400;d=500;p=2;r=30000 -> ACK:C28=ok:*
C33:v=512 -> ACK:C33=ok:*

# ============================================================
# MQTT CONFIGURATION COMMANDS
# ============================================================
M0:v=0 -> ACK:M0=ok:*
M0:v=1 -> ACK:M0=ok:*
M1:192.168.1.100 -> ACK:M1=ok:*
M2:v=1883 -> ACK:M2=ok:*
M3:testuser -> ACK:M3=ok:*|ACK:M3=Invalid parameter:*
M4:testpass -> ACK:M4=ok:*|ACK:M4=Invalid parameter:*
M5:test_device -> ACK:M5=ok:*
M6:v=0 -> ACK:M6=ok:*
M6:v=1 -> ACK:M6=ok:*
M7:v=60 -> ACK:M7=ok:*
M9:homeassistant -> ACK:M9=ok:*

# MQTT Query Commands
M0 -> ACK:M0=ok:v=*
M1 -> ACK:M1=ok:v=*
M2 -> ACK:M2=ok:v=*
M3 -> ACK:M3=ok:v=*
M4 -> ACK:M4=ok:v=*
M5 -> ACK:M5=ok:v=*
M6 -> ACK:M6=ok:v=*
M7 -> ACK:M7=ok:v=*
M9 -> ACK:M9=ok:v=*
M8 -> ACK:M8=ok:v=*

# ============================================================
# RELAY CONTROL COMMANDS
# ============================================================
R0 -> ACK:R0=ok
R1 -> ACK:R1=ok
R2 -> ACK:R2=ok:*
R3:0=0 -> ACK:R3=ok:*|ACK:R3=Invalid relay index:*
R3:0=1 -> ACK:R3=ok:*|ACK:R3=Invalid relay index:*
R3:7=1 -> ACK:R3=ok:*|ACK:R3=Invalid relay index:*
R4:0 -> ACK:R4=ok:0=*
R4:7 -> ACK:R4=ok:7=*
R5 -> ACK:R5=ok*

# ============================================================
# RELAY CONFIGURATION COMMANDS
# ============================================================
R6:0=Test -> ACK:R6=ok:*
R6:1=Test|Test Name -> ACK:R6=ok:*
R7:0=0 -> ACK:R7=ok:*
R7:1=4 -> ACK:R7=ok:*
R7:2=255 -> ACK:R7=ok:*
R8:0=0 -> ACK:R8=ok:*
R8:1=1 -> ACK:R8=ok:*
R9:0=1 -> ACK:R9=ok:*
R9:0=255 -> ACK:R9=ok:*
R10:0=0 -> ACK:R10=ok:*
R10:1=1 -> ACK:R10=ok:*
R10:2=2 -> ACK:R10=ok:*
R11:0=15 -> ACK:R11=ok:*
R11:7=22 -> ACK:R11=ok:*

# ============================================================
# SENSOR CONFIGURATION COMMANDS
# ============================================================
S0 -> ACK:S0=ok|ACK:S0=ok:*
S1:i=0;t=1;o0=0;o1=0 -> ACK:S1=ok:reboot=1
S2:0 -> ACK:S2=ok:reboot=1
S3:0=Test Sensor -> ACK:S3=ok:reboot=1
S4:i=0;s=0;v=34 -> ACK:S4=ok:reboot=1
S5:0=0 -> ACK:S5=ok:reboot=1
S5:0=1 -> ACK:S5=ok:reboot=1
S6:i=0;s=0;v=1 -> ACK:S6=ok:reboot=1|ACK:S6=Invalid or missing parameters

# ============================================================
# WARNING COMMANDS
# ============================================================
W1 -> ACK:W1=ok:*
W3 -> ACK:W3=ok
W4:0x05=1 -> ACK:W4=ok|ACK:W4=Invalid warning type
W4:0x05=0 -> ACK:W4=ok|ACK:W4=Invalid warning type

# ============================================================
# SOUND SIGNAL COMMANDS (Fog Horn)
# ============================================================
H0 -> ACK:H0=ok
H1 -> ACK:H1=ok:*
H2 -> ACK:H2=ok
H3 -> ACK:H3=ok
H4 -> ACK:H4=ok
H5 -> ACK:H5=ok
H6 -> ACK:H6=ok
H7 -> ACK:H7=ok
H8 -> ACK:H8=ok
H9 -> ACK:H9=ok
H10 -> ACK:H10=ok
H11 -> ACK:H11=ok
H12 -> ACK:H12=ok

# ============================================================
# TIMER/SCHEDULER COMMANDS
# ============================================================
T0 -> T0:count=*
T1:v=0 -> ACK:T1=Slot is empty:*|ACK:T1=ok:*
T2:i=0;e=1;t=1,18,30,0,0;c=0,0,0,0,0;a=2,2,0,0,0 -> ACK:T2=ok
T3:v=0 -> ACK:T3=ok:*
T4:i=0;v=1 -> ACK:T4=ok
T4:i=0;v=0 -> ACK:T4=ok
T5 -> ACK:T5=ok
T6:v=0 -> ACK:T6=ok|ACK:T6=No action defined

# ============================================================
# ERROR RESPONSE TESTS
# ============================================================
# Test invalid parameters
C7:v=99 -> ACK:C7=Invalid parameter:*
C20:v=99 -> ACK:C20=Invalid parameter:*
C21:123 -> ACK:C21=Invalid parameter:*
R3:99=1 -> ACK:R3=Invalid relay index
R7:0=99 -> ACK:R7=Invalid color:*
M2:v=0 -> ACK:M2=Invalid parameter:*

# Test missing parameters
C3 -> ACK:C3=Invalid parameter:*
C7 -> ACK:C7=Invalid parameter:*
C20 -> ACK:C20=Invalid parameter:*

# ============================================================
# CONFIGURATION GET/SAVE/RESET
# ============================================================
# Get all settings (returns multiple commands)
C1 -> C*

# Save settings to EEPROM
C0 -> ACK:C0=ok:*

# Reset all settings
C2 -> ACK:C2=ok:*

# ============================================================
# EXTENDED TESTS - BOUNDARY VALUES
# ============================================================

# Timezone boundaries
C20:v=-12 -> ACK:C20=ok:*
C20:v=14 -> ACK:C20=ok:*
C20:v=-13 -> ACK:C20=Invalid parameter:*
C20:v=15 -> ACK:C20=Invalid parameter:*

# LED Brightness boundaries
C25:t=0;b=0 -> ACK:C25=ok:*
C25:t=0;b=100 -> ACK:C25=ok:*
C25:t=0;b=101 -> ACK:C25=Invalid parameter:*
C25:t=1;b=50 -> ACK:C25=ok:*

# LED Type boundaries
C24:t=0;c=0;r=0;g=0;b=0 -> ACK:C24=ok:*
C24:t=0;c=0;r=255;g=255;b=255 -> ACK:C24=ok:*
C24:t=2;c=0;r=255;g=0;b=0 -> ACK:C24=Invalid parameter:*
C24:t=0;c=2;r=255;g=0;b=0 -> ACK:C24=Invalid parameter:*

# Relay color boundaries (0-5 valid, 255 clear)
R7:0=0 -> ACK:R7=ok:*
R7:0=5 -> ACK:R7=ok:*
R7:0=6 -> ACK:R7=Invalid color:*

# WiFi Port boundaries
C15:v=1 -> ACK:C15=ok:*
C15:v=65535 -> ACK:C15=ok:*

# MQTT Port boundaries
M2:v=1 -> ACK:M2=ok:*
M2:v=65535 -> ACK:M2=ok:*

# MQTT Keep Alive boundaries
M7:v=1 -> ACK:M7=ok:*
M7:v=3600 -> ACK:M7=ok:*

# ============================================================
# EXTENDED TESTS - ALL SENSOR TYPES
# ============================================================

# Sensor Type 0: Water Sensor
S1:i=0;t=0;o0=0;o1=0 -> ACK:S1=ok:reboot=1

# Sensor Type 1: Dht11 (already tested)

# Sensor Type 2: Light Sensor (digital mode)
S1:i=1;t=2;o0=1;o1=0 -> ACK:S1=ok:reboot=1

# Sensor Type 3: System Sensor
S1:i=2;t=3;o0=0;o1=0 -> ACK:S1=ok:reboot=1

# Sensor Type 5: Binary Presence Sensor
S1:i=3;t=5;o0=1;o1=0 -> ACK:S1=ok:reboot=1

# Remove all test sensors
S2:0 -> ACK:S2=ok:reboot=1
S2:1 -> ACK:S2=ok:reboot=1
S2:2 -> ACK:S2=ok:reboot=1
S2:3 -> ACK:S2=ok:reboot=1

# ============================================================
# EXTENDED TESTS - HOME BUTTON MAPPING
# ============================================================

# Map home buttons to relays
C5:0=0 -> ACK:C5=ok:*
C5:1=1 -> ACK:C5=ok:*
C5:2=2 -> ACK:C5=ok:*
C5:3=3 -> ACK:C5=ok:*

# Unmap home buttons
C5:0=255 -> ACK:C5=ok:*
C5:1=255 -> ACK:C5=ok:*

# Invalid slot (only 0-3 valid for HOME_BUTTONS)
C5:4=0 -> ACK:C5=Invalid parameter:*|ACK:C5=Button out of range

# Invalid relay (0-7 or 255 only)
C5:0=8 -> ACK:C5=Invalid parameter:*|ACK:C5=Relay out of range

# ============================================================
# EXTENDED TESTS - CONTROL PANEL TONE PRESETS
# ============================================================

# Preset 0: Custom tone
C28:t=0;h=1000;d=250;p=0;r=0 -> ACK:C28=ok:*

# Preset 1: Submarine ping
C28:t=0;h=0;d=0;p=1;r=0 -> ACK:C28=ok:*

# Preset 2: Double beep
C28:t=0;h=0;d=0;p=2;r=0 -> ACK:C28=ok:*

# Preset 3: Rising chirp
C28:t=0;h=0;d=0;p=3;r=0 -> ACK:C28=ok:*

# Preset 4: Descending alert
C28:t=0;h=0;d=0;p=4;r=0 -> ACK:C28=ok:*

# Preset 5: Nautical bell
C28:t=0;h=0;d=0;p=5;r=0 -> ACK:C28=ok:*

# Preset 0xFF: No sound
C28:t=0;h=0;d=0;p=255;r=0 -> ACK:C28=ok:*

# Bad tone with repeat interval
C28:t=1;h=400;d=500;p=0;r=30000 -> ACK:C28=ok:*

# ============================================================
# EXTENDED TESTS - STRING EDGE CASES
# ============================================================

# Long boat name (should be truncated)
C3:VeryLongBoatNameThatExceedsMaximumAllowedLength -> ACK:C3=ok:*

# Long call sign (should be truncated)
C22:VERYLONGCALLSIGN123 -> ACK:C22=ok:*

# Long home port (should be truncated)
C23:Very Long Home Port Name That Exceeds Maximum -> ACK:C23=ok:*

# Boat name with special characters
C3:Boat-Name -> ACK:C3=ok:*

# WiFi SSID with spaces
C13:SSID With Spaces -> ACK:C13=ok:*

# MQTT Device ID with underscores
M5:device_id_test -> ACK:M5=ok:*

# ============================================================
# EXTENDED TESTS - RELAY ACTION TYPES
# ============================================================

# Test all relay action types (0=Default, 1=Horn, 2=NightRelay)
R10:0=0 -> ACK:R10=ok:*
R10:1=0 -> ACK:R10=ok:*
R10:2=1 -> ACK:R10=ok:*
R10:3=0 -> ACK:R10=ok:*
R10:4=2 -> ACK:R10=ok:*
R10:5=0 -> ACK:R10=ok:*

# Invalid action type
R10:0=3 -> ACK:R10=Invalid parameter:*

# ============================================================
# EXTENDED TESTS - TIMER/SCHEDULER COMPREHENSIVE
# ============================================================

# Trigger Type 1: TimeOfDay (hour, minute)
T2:i=0;e=1;t=1,18,30,0,0;c=0,0,0,0,0;a=2,2,0,0,0 -> ACK:T2=ok

# Trigger Type 2: Sunrise with offset (+10 minutes)
T2:i=1;e=1;t=2,10,0,0,0;c=0,0,0,0,0;a=1,0,0,0,0 -> ACK:T2=ok

# Trigger Type 3: Sunset with offset (-10 minutes)
T2:i=2;e=1;t=3,246,255,0,0;c=0,0,0,0,0;a=1,1,0,0,0 -> ACK:T2=ok

# Trigger Type 4: Interval (every 30 minutes)
T2:i=3;e=1;t=4,30,0,0,0;c=0,0,0,0,0;a=1,2,0,0,0 -> ACK:T2=ok

# Trigger Type 5: DayOfWeek (Monday-Friday = 31)
T2:i=4;e=1;t=5,31,0,0,0;c=0,0,0,0,0;a=1,3,0,0,0 -> ACK:T2=ok

# Trigger Type 6: Date (December 25)
T2:i=5;e=1;t=6,25,12,0,0;c=0,0,0,0,0;a=1,4,0,0,0 -> ACK:T2=ok

# Condition Type 1: TimeWindow (9:00-17:00)
T2:i=6;e=1;t=1,12,0,0,0;c=1,9,0,17,0;a=1,5,0,0,0 -> ACK:T2=ok

# Condition Type 2: DayOfWeek in condition (weekends = 96)
T2:i=7;e=1;t=1,12,0,0,0;c=2,96,0,0,0;a=1,6,0,0,0 -> ACK:T2=ok

# Condition Type 3: IsDark
T2:i=8;e=1;t=1,20,0,0,0;c=3,0,0,0,0;a=1,7,0,0,0 -> ACK:T2=ok

# Condition Type 4: IsDaylight
T2:i=9;e=1;t=1,12,0,0,0;c=4,0,0,0,0;a=2,0,0,0,0 -> ACK:T2=ok

# Condition Type 5: RelayIsOn (relay 0)
T2:i=10;e=1;t=1,12,0,0,0;c=5,0,0,0,0;a=2,1,0,0,0 -> ACK:T2=ok

# Condition Type 6: RelayIsOff (relay 1)
T2:i=11;e=1;t=1,12,0,0,0;c=6,1,0,0,0;a=2,2,0,0,0 -> ACK:T2=ok

# Action Type 3: RelayToggle (relay 3)
T2:i=12;e=1;t=1,12,0,0,0;c=0,0,0,0,0;a=3,3,0,0,0 -> ACK:T2=ok

# Action Type 4: RelayPulse (relay 4, 10 seconds)
T2:i=13;e=1;t=1,12,0,0,0;c=0,0,0,0,0;a=4,4,10,0,0 -> ACK:T2=ok

# Action Type 5: AllRelaysOn
T2:i=14;e=1;t=1,12,0,0,0;c=0,0,0,0,0;a=5,0,0,0,0 -> ACK:T2=ok

# Action Type 6: AllRelaysOff
T2:i=15;e=1;t=1,12,0,0,0;c=0,0,0,0,0;a=6,0,0,0,0 -> ACK:T2=ok

# Action Type 7: SetPinHigh (GPIO 15)
T2:i=16;e=1;t=1,12,0,0,0;c=0,0,0,0,0;a=7,15,0,0,0 -> ACK:T2=ok

# Action Type 8: SetPinLow (GPIO 15)
T2:i=17;e=1;t=1,12,0,0,0;c=0,0,0,0,0;a=8,15,0,0,0 -> ACK:T2=ok

# Enable/disable specific events
T4:i=0;v=1 -> ACK:T4=ok
T4:i=0;v=0 -> ACK:T4=ok

# Get specific event details
T1:v=0 -> ACK:T1=ok:*|ACK:T1=Slot is empty:*

# Delete specific event
T3:v=0 -> ACK:T3=ok:*

# ============================================================
# EXTENDED TESTS - SEQUENTIAL VALIDATION
# ============================================================

# Set vessel type and verify
C7:v=2 -> ACK:C7=ok:*
C7 -> ACK:C7=ok:v=2

# Set timezone and verify
C20:v=-5 -> ACK:C20=ok:*
C20 -> ACK:C20=ok:v=-5

# Set MQTT enabled and verify
M0:v=1 -> ACK:M0=ok:*
M0 -> ACK:M0=ok:v=1

# Set relay state and verify
R3:0=1 -> ACK:R3=ok:*|ACK:R3=Invalid relay index:*
R4:0 -> ACK:R4=ok:0=*

# Set relay default state and verify through R5
R8:0=1 -> ACK:R8=ok:*
R5 -> ACK:R5=ok*

# ============================================================
# EXTENDED TESTS - ALL VESSEL TYPES
# ============================================================

# Vessel type 0: Motor
C7:v=0 -> ACK:C7=ok:*

# Vessel type 1: Sail
C7:v=1 -> ACK:C7=ok:*

# Vessel type 2: Fishing
C7:v=2 -> ACK:C7=ok:*

# Vessel type 3: Yacht
C7:v=3 -> ACK:C7=ok:*

# Invalid vessel type
C7:v=4 -> ACK:C7=Invalid parameter:*

# ============================================================
# EXTENDED TESTS - LED CONFIGURATION COMPLETE
# ============================================================

# Day mode, Good colorset, RGB values
C24:t=0;c=0;r=0;g=255;b=0 -> ACK:C24=ok:*

# Day mode, Bad colorset, RGB values
C24:t=0;c=1;r=255;g=0;b=0 -> ACK:C24=ok:*

# Night mode, Good colorset, dimmed
C24:t=1;c=0;r=0;g=100;b=0 -> ACK:C24=ok:*

# Night mode, Bad colorset, dimmed
C24:t=1;c=1;r=100;g=0;b=0 -> ACK:C24=ok:*

# Invalid type (only 0=day, 1=night)
C24:t=2;c=0;r=255;g=0;b=0 -> ACK:C24=Invalid parameter:*

# Invalid colorset (only 0=good, 1=bad)
C24:t=0;c=2;r=255;g=0;b=0 -> ACK:C24=Invalid parameter:*

# LED Auto Switch enabled
C26:v=1 -> ACK:C26=ok:*
C26:v=true -> ACK:C26=ok:*

# LED Auto Switch disabled
C26:v=0 -> ACK:C26=ok:*
C26:v=false -> ACK:C26=ok:*

# LED Enable all
C27:g=1;w=1;s=1 -> ACK:C27=ok:*
C27:g=true;w=true;s=true -> ACK:C27=ok:*

# LED Disable all
C27:g=0;w=0;s=0 -> ACK:C27=ok:*
C27:g=false;w=false;s=false -> ACK:C27=ok:*

# LED mixed state
C27:g=1;w=0;s=1 -> ACK:C27=ok:*

# ============================================================
# EXTENDED TESTS - SOUND DELAY BOUNDARIES
# ============================================================

C9:v=0 -> ACK:C9=ok:*
C9:v=50 -> ACK:C9=ok:*
C9:v=100 -> ACK:C9=ok:*
C9:v=255 -> ACK:C9=ok:*

# ============================================================
# EXTENDED TESTS - LIGHT SENSOR THRESHOLD
# ============================================================

C33:v=0 -> ACK:C33=ok:*
C33:v=256 -> ACK:C33=ok:*
C33:v=512 -> ACK:C33=ok:*
C33:v=768 -> ACK:C33=ok:*
C33:v=1023 -> ACK:C33=ok:*
C33:v=1024 -> ACK:C33=Invalid parameter:*

# ============================================================
# EXTENDED TESTS - SD CARD INITIALIZATION SPEEDS
# ============================================================

C31:v=4 -> ACK:C31=ok:*
C31:v=8 -> ACK:C31=ok:*
C31:v=12 -> ACK:C31=ok:*
C31:v=16 -> ACK:C31=ok:*
C31:v=20 -> ACK:C31=ok:*
C31:v=24 -> ACK:C31=ok:*
C31:v=5 -> ACK:C31=Invalid parameter:*

# ============================================================
# EXTENDED TESTS - RELAY LINKING COMPREHENSIVE
# ============================================================

# Link relay 0 to relay 1
R9:0=1 -> ACK:R9=ok:*

# Link relay 2 to relay 3
R9:2=3 -> ACK:R9=ok:*

# Unlink relay 0
R9:0=255 -> ACK:R9=ok:*

# Invalid linked relay
R9:0=8 -> ACK:R9=Invalid parameter:*|ACK:R9=No available link slots

# ============================================================
# EXTENDED TESTS - OTA FIRMWARE COMMANDS (SFB only)
# ============================================================

# Check OTA status (requires WiFi enabled and ESP32)
# F13 -> ACK:F13=ok:v=*;av=*;s=*;auto=*

# Check for OTA update without applying
# F12 -> ACK:F12=ok:v=*;av=*;s=*
# F12:apply=0 -> ACK:F12=ok:v=*;av=*;s=*

# Check and apply OTA update
# F12:apply=1 -> ACK:F12=ok:v=*;av=*;s=*

# ============================================================
# EXTENDED TESTS - MMSI VALIDATION
# ============================================================

# Valid MMSI (exactly 9 digits)
C21:123456789 -> ACK:C21=ok|ACK:C21=Invalid parameter:*
C21:000000000 -> ACK:C21=ok|ACK:C21=Invalid parameter:*
C21:999999999 -> ACK:C21=ok|ACK:C21=Invalid parameter:*

# Invalid MMSI (not 9 digits)
C21:12345678 -> ACK:C21=Invalid parameter:*
C21:1234567890 -> ACK:C21=Invalid parameter:*

# ============================================================
# EXTENDED TESTS - SENSOR PIN AND OPTION CONFIGURATION
# ============================================================

# Set sensor pin slot 0
S4:i=0;s=0;v=34 -> ACK:S4=ok:reboot=1

# Set sensor pin slot 1
S4:i=0;s=1;v=35 -> ACK:S4=ok:reboot=1

# Clear sensor pin (255 = PinDisabled)
S4:i=0;s=0;v=255 -> ACK:S4=ok:reboot=1

# Set sensor option
S6:i=0;s=0;v=1 -> ACK:S6=ok:reboot=1|ACK:S6=Invalid or missing parameters

# Invalid sensor index
S4:i=10;s=0;v=34 -> ACK:S4=Invalid sensor index|ACK:S4=Invalid parameter:*

# Invalid pin slot
S4:i=0;s=5;v=34 -> ACK:S4=Invalid parameter:*|ACK:S4=Invalid pin slot

# ============================================================
# EXTENDED TESTS - WIFI AP MODE
# ============================================================

# Set to AP mode
C12:v=0 -> ACK:C12=ok:*

# Set AP IP address
C17:192.168.4.1 -> ACK:C17=ok:*
C17:10.0.0.1 -> ACK:C17=ok:*

# Set back to Client mode
C12:v=1 -> ACK:C12=ok:*

# ============================================================
# EXTENDED TESTS - MQTT DISCOVERY PREFIX
# ============================================================

M9:homeassistant -> ACK:M9=ok:*
M9:myboat -> ACK:M9=ok:*
M9:custom_prefix -> ACK:M9=ok:*

# ============================================================
# EXTENDED TESTS - ALL BUTTON COLORS
# ============================================================

# BTN_COLOR_BLUE = 0
R7:0=0 -> ACK:R7=ok:*

# BTN_COLOR_GREEN = 1
R7:1=1 -> ACK:R7=ok:*

# BTN_COLOR_ORANGE = 2
R7:2=2 -> ACK:R7=ok:*

# BTN_COLOR_PINK = 3
R7:3=3 -> ACK:R7=ok:*

# BTN_COLOR_RED = 4
R7:4=4 -> ACK:R7=ok:*

# BTN_COLOR_YELLOW = 5
R7:5=5 -> ACK:R7=ok:*

# Clear color (255)
R7:6=255 -> ACK:R7=ok:*

# Invalid color
R7:7=6 -> ACK:R7=Invalid color:*

# ============================================================
# XPDZ TONE PIN CONFIGURATION (C6)
# ============================================================

# Set XpdzTone pin to a valid GPIO
C6:v=25 -> ACK:C6=ok:*
C6:v=26 -> ACK:C6=ok:*

# Set XpdzTone pin to PinDisabled (255 = not fitted)
C6:v=255 -> ACK:C6=ok:*

# Missing parameter
C6 -> ACK:C6=Invalid parameter:*

# Verify C1 includes C6
C1 -> C*

# ============================================================
# HW479 RGB LED PIN CONFIGURATION (C8)
# ============================================================

# Set all three RGB pins
C8:r=25;g=26;b=27 -> ACK:C8=ok:*
C8:r=16;g=17;b=18 -> ACK:C8=ok:*

# Disable all pins (PinDisabled = 255)
C8:r=255;g=255;b=255 -> ACK:C8=ok:*

# Mixed: some disabled, some active
C8:r=25;g=255;b=255 -> ACK:C8=ok:*

# Missing parameter(s)
C8:r=25;g=26 -> ACK:C8=Invalid parameter:*
C8 -> ACK:C8=Invalid parameter:*

# ============================================================
# RTC DS1302 PIN CONFIGURATION (C18)
# ============================================================

# Set all three DS1302 pins
C18:dat=4;clk=5;rst=6 -> ACK:C18=ok:*
C18:dat=14;clk=15;rst=16 -> ACK:C18=ok:*

# Disable all pins (PinDisabled = 255)
C18:dat=255;clk=255;rst=255 -> ACK:C18=ok:*

# Mixed: some disabled
C18:dat=4;clk=255;rst=255 -> ACK:C18=ok:*

# Missing parameter(s)
C18:dat=4;clk=5 -> ACK:C18=Invalid parameter:*
C18 -> ACK:C18=Invalid parameter:*

# ============================================================
# NEXTION DISPLAY CONFIGURATION (N0-N6)
# ============================================================

# Get all Nextion config (returns N1-N6 values then ACK)
N0 -> ACK:N0=ok

# N1: Enable/disable Nextion display
N1:v=1 -> ACK:N1=ok:*
N1:v=0 -> ACK:N1=ok:*
N1:v=true -> ACK:N1=ok:*
N1:v=false -> ACK:N1=ok:*

# Missing parameter
N1 -> ACK:N1=Invalid parameter:*

# N2: Hardware serial vs software serial
N2:v=1 -> ACK:N2=ok:*
N2:v=0 -> ACK:N2=ok:*

# Missing parameter
N2 -> ACK:N2=Invalid parameter:*

# N3: RX pin (255 = PinDisabled)
N3:v=16 -> ACK:N3=ok:*
N3:v=255 -> ACK:N3=ok:*

# Missing parameter
N3 -> ACK:N3=Invalid parameter:*

# N4: TX pin (255 = PinDisabled)
N4:v=17 -> ACK:N4=ok:*
N4:v=255 -> ACK:N4=ok:*

# Missing parameter
N4 -> ACK:N4=Invalid parameter:*

# N5: Baud rate (common values)
N5:v=9600 -> ACK:N5=ok:*
N5:v=115200 -> ACK:N5=ok:*
N5:v=921600 -> ACK:N5=ok:*

# Missing parameter
N5 -> ACK:N5=Invalid parameter:*

# N6: UART number (only 1 or 2 are valid; UART0 reserved)
N6:v=1 -> ACK:N6=ok:*
N6:v=2 -> ACK:N6=ok:*

# Invalid UART number
N6:v=0 -> ACK:N6=Invalid parameter:*
N6:v=3 -> ACK:N6=Invalid parameter:*

# Missing parameter
N6 -> ACK:N6=Invalid parameter:*

# ============================================================
# EXTERNAL / REMOTE SENSOR CONFIGURATION (E0-E4)
# ============================================================

# E0: Get all external sensor config entries
E0 -> ACK:E0=ok:*

# E1: Set core fields for a new external sensor
E1:i=0;id=7;n=TempSensor;mn=temperature;ms=temp -> ACK:E1=ok:reboot=1

# E1: Add a second sensor
E1:i=1;id=8;n=HumSensor;mn=humidity;ms=hum -> ACK:E1=ok:reboot=1

# E2: Set MQTT detail fields (sensor must exist first via E1)
E2:i=0;mt=sensor;md=temperature;mu=C;bin=0 -> ACK:E2=ok:reboot=1
E2:i=1;mt=sensor;md=humidity;mu=%;bin=0 -> ACK:E2=ok:reboot=1

# E2: Binary sensor
E2:i=0;mt=binary_sensor;md=motion;mu=;bin=1 -> ACK:E2=ok:reboot=1

# E4: Rename an existing sensor
E4:0=Outside Temp -> ACK:E4=ok:reboot=1

# E3: Remove sensor at index 1
E3:1 -> ACK:E3=ok:reboot=1

# E3: Remove sensor at index 0
E3:0 -> ACK:E3=ok:reboot=1

# Error cases - invalid sensor index
E1:i=8;id=7;n=TooMany;mn=x;ms=x -> ACK:E1=Invalid sensor index:*|ACK:E1=Invalid parameter:*
E2:i=8;mt=sensor;md=temperature;mu=C;bin=0 -> ACK:E2=Invalid sensor index:*|ACK:E2=Invalid parameter:*
E3:8 -> ACK:E3=Invalid sensor index:*
E4:8=NewName -> ACK:E4=Invalid sensor index:*
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

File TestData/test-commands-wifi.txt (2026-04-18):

# SmartFuseBox WiFi API Test Commands
# Lines starting with # are comments
# Format: METHOD /endpoint [body] -> JSON_PATTERN
# Use | to separate multiple valid responses
# Use * as wildcard for variable content in JSON

# ============================================================
# INDEX / ROOT ENDPOINTS
# ============================================================
GET / -> {*}
GET /api/index -> {*}

# ============================================================
# SYSTEM COMMANDS - Query (POST not GET - WiFi API uses POST for queries)
# ============================================================
POST /api/system/F2 -> {"v":*}|{"error":"Not Found","message":*}
POST /api/system/F3 -> {"v":*}|{"error":"Not Found","message":*}
POST /api/system/F4 -> {"v":*}|{"error":"Not Found","message":*}
POST /api/system/F5 -> {"v":*}|{"error":"Not Found","message":*}
POST /api/system/F7 -> {"v":"*"}|{"error":"Not Found","message":*}
POST /api/system/F8 -> {"v":*}|{"error":"Not Found","message":*}
POST /api/system/F9 -> {"v":*}|{"error":"Not Found","message":*}
POST /api/system/F11 -> {"v":"*"}|{"error":"Not Found","message":*}
GET /api/system/F10 -> {*}

# OTA Commands (SFB only, requires WiFi)
# GET /api/system/F13 -> {"v":"*","av":"*","s":"*","auto":*}

# ============================================================
# SYSTEM COMMANDS - Set (POST)
# ============================================================
POST /api/system/F6 v=1733328600 -> {"success":true}|{*}
POST /api/system/F0 w=0x00 -> {"success":true}|{*}

# ============================================================
# RELAY COMMANDS - Query (GET)
# ============================================================
# Get all relay states and configuration
GET /api/relay/R2 -> {"relays":*}

# Get specific relay state
GET /api/relay/R4 0 -> {"*":*}

# Get all relay configuration
GET /api/relay/R5 -> {*}

# ============================================================
# RELAY COMMANDS - Control (POST)
# ============================================================
# Turn all relays off/on
POST /api/relay/R0 -> {"relays":*}
POST /api/relay/R1 -> {"relays":*}

# Set specific relay state (0-7) - Note: May return 404 if relays not configured
POST /api/relay/R3 0=0 -> {"relays":*}|{"error":"Invalid relay index"}|{"error":"Not Found","message":*}
POST /api/relay/R3 0=1 -> {"relays":*}|{"error":"Invalid relay index"}|{"error":"Not Found","message":*}
POST /api/relay/R3 7=1 -> {"relays":*}|{"error":"Invalid relay index"}|{"error":"Not Found","message":*}

# Invalid relay index
POST /api/relay/R3 99=1 -> {"error":*}

# ============================================================
# RELAY CONFIGURATION - (POST)
# ============================================================
# Rename relay
POST /api/relay/R6 0=NavLight -> {"success":true}|{*}
POST /api/relay/R6 1=Bilge|Bilge Pump -> {"success":true}|{*}

# Set button color (0-5 or 255)
POST /api/relay/R7 0=0 -> {"success":true}|{*}
POST /api/relay/R7 1=4 -> {"success":true}|{*}
POST /api/relay/R7 2=255 -> {"success":true}|{*}

# Invalid color
POST /api/relay/R7 0=99 -> {"error":*}

# Set default state
POST /api/relay/R8 0=0 -> {"success":true}|{*}
POST /api/relay/R8 1=1 -> {"success":true}|{*}

# Link relays
POST /api/relay/R9 0=1 -> {"success":true}|{*}
POST /api/relay/R9 0=255 -> {"success":true}|{*}

# Set action type
POST /api/relay/R10 0=0 -> {"success":true}|{*}
POST /api/relay/R10 1=1 -> {"success":true}|{*}
POST /api/relay/R10 2=2 -> {"success":true}|{*}

# Set relay pin
POST /api/relay/R11 0=15 -> {"success":true}|{*}
POST /api/relay/R11 7=22 -> {"success":true}|{*}

# ============================================================
# CONFIGURATION COMMANDS - Boat Info (POST)
# ============================================================
POST /api/config/C3 Test Boat -> {"success":true}|{*}
POST /api/config/C3 name=Test Boat 2 -> {"success":true}|{*}
POST /api/config/C21 123456789 -> {"success":true}|{"error":*}
POST /api/config/C22 TEST123 -> {"success":true}|{*}
POST /api/config/C23 Test Port -> {"success":true}|{*}

# ============================================================
# CONFIGURATION COMMANDS - Vessel Settings (POST)
# ============================================================
POST /api/config/C7 v=0 -> {"success":true}|{*}
POST /api/config/C7 v=1 -> {"success":true}|{*}
POST /api/config/C7 v=2 -> {"success":true}|{*}
POST /api/config/C7 v=3 -> {"success":true}|{*}

# Timezone
POST /api/config/C20 v=-5 -> {"success":true}|{*}
POST /api/config/C20 v=0 -> {"success":true}|{*}
POST /api/config/C20 v=8 -> {"success":true}|{*}

# Sound delay
POST /api/config/C9 v=100 -> {"success":true}|{*}

# ============================================================
# CONFIGURATION COMMANDS - Bluetooth (POST)
# ============================================================
POST /api/config/C10 v=0 -> {"success":true}|{"error":"Bluetooth init failed"}|{*}
POST /api/config/C10 v=1 -> {"success":true}|{"error":"Bluetooth init failed"}|{*}

# ============================================================
# CONFIGURATION COMMANDS - SPI (POST)
# ============================================================
POST /api/config/C4 sck=12;mosi=11;miso=13 -> {"success":true}|{*}
POST /api/config/C31 v=4 -> {"success":true}|{*}
POST /api/config/C31 v=8 -> {"success":true}|{*}

# ============================================================
# CONFIGURATION COMMANDS - LED Settings (POST)
# ============================================================
POST /api/config/C24 t=0;c=0;r=255;g=50;b=213 -> {"success":true}|{*}
POST /api/config/C25 t=0;b=75 -> {"success":true}|{*}
POST /api/config/C26 v=1 -> {"success":true}|{*}
POST /api/config/C27 g=1;w=1;s=1 -> {"success":true}|{*}

# ============================================================
# CONFIGURATION COMMANDS - Control Panel Tones (POST)
# ============================================================
POST /api/config/C28 t=0;h=400;d=500;p=0;r=0 -> {"success":true}|{*}
POST /api/config/C33 v=512 -> {"success":true}|{*}

# ============================================================
# MQTT CONFIGURATION (POST)
# ============================================================
POST /api/config/M0 v=0 -> {"success":true}|{*}
POST /api/config/M0 v=1 -> {"success":true}|{*}
POST /api/config/M1 192.168.1.100 -> {"success":true}|{*}
POST /api/config/M2 v=1883 -> {"success":true}|{*}
POST /api/config/M3 testuser -> {"success":true}|{"error":*}
POST /api/config/M4 testpass -> {"success":true}|{"error":*}
POST /api/config/M5 test_device -> {"success":true}|{*}
POST /api/config/M6 v=0 -> {"success":true}|{*}
POST /api/config/M6 v=1 -> {"success":true}|{*}
POST /api/config/M7 v=60 -> {"success":true}|{*}
POST /api/config/M9 homeassistant -> {"success":true}|{*}

# ============================================================
# SENSOR COMMANDS (GET)
# ============================================================
GET /api/sensor -> {*}

# ============================================================
# SENSOR CONFIGURATION (POST)
# ============================================================
POST /api/config/S0 -> {*}
POST /api/config/S1 i=0;t=1;o0=0;o1=0 -> {"success":true}|{*}
POST /api/config/S2 0 -> {"success":true}|{*}
POST /api/config/S3 0=Test Sensor -> {"success":true}|{*}
POST /api/config/S4 i=0;s=0;v=34 -> {"success":true}|{*}
POST /api/config/S5 0=0 -> {"success":true}|{*}
POST /api/config/S5 0=1 -> {"success":true}|{*}

# ============================================================
# WARNING COMMANDS (GET)
# ============================================================
GET /api/warning/W1 -> {"status":*}|{*}

# ============================================================
# WARNING COMMANDS (POST)
# ============================================================
POST /api/warning/W3 -> {"success":true}|{*}
POST /api/warning/W4 0x05=1 -> {"success":true}|{"success":false,"message":"Invalid parameters"}
POST /api/warning/W4 0x05=0 -> {"success":true}|{"success":false,"message":"Invalid parameters"}

# ============================================================
# SOUND SIGNAL COMMANDS (POST)
# ============================================================
POST /api/sound/H0 -> {"success":true}|{*}
GET /api/sound/H1 -> {*}
POST /api/sound/H2 -> {"success":true}|{*}
POST /api/sound/H3 -> {"success":true}|{*}
POST /api/sound/H4 -> {"success":true}|{*}
POST /api/sound/H5 -> {"success":true}|{*}
POST /api/sound/H6 -> {"success":true}|{*}
POST /api/sound/H7 -> {"success":true}|{*}
POST /api/sound/H8 -> {"success":true}|{*}
POST /api/sound/H9 -> {"success":true}|{*}
POST /api/sound/H10 -> {"success":true}|{*}
POST /api/sound/H11 -> {"success":true}|{*}
POST /api/sound/H12 -> {"success":true}|{*}

# ============================================================
# TIMER/SCHEDULER COMMANDS (GET)
# ============================================================
GET /api/timer/T0 -> {*}
GET /api/timer/T1 v=0 -> {*}

# ============================================================
# TIMER/SCHEDULER COMMANDS (POST)
# ============================================================
POST /api/timer/T2 i=0;e=1;t=1,18,30,0,0;c=0,0,0,0,0;a=2,2,0,0,0 -> {"success":true}|{*}
POST /api/timer/T3 v=0 -> {"success":true}|{*}
POST /api/timer/T4 i=0;v=1 -> {"success":true}|{*}
POST /api/timer/T4 i=0;v=0 -> {"success":true}|{*}
POST /api/timer/T5 -> {"success":true}|{*}
POST /api/timer/T6 v=0 -> {"success":true}|{"success":false,"message":"Unknown timer command"}

# ============================================================
# ERROR RESPONSE TESTS
# ============================================================
# Invalid endpoints
GET /api/invalid -> {"error":*}
GET /api/relay/R99 -> {"error":*}
POST /api/config/X99 test -> {"error":*}

# Invalid parameters
POST /api/config/C7 v=99 -> {"error":*}
POST /api/config/C20 v=99 -> {"error":*}
POST /api/relay/R3 99=1 -> {"error":*}

# Method not allowed (using wrong HTTP method)
# POST / -> {"error":*}

# Not found errors
GET /api/relay/R3/10=1 -> {"error":"Not Found"}|{"error":*}

# ============================================================
# CONFIGURATION GET/SAVE/RESET (POST)
# ============================================================
# Get all settings
POST /api/config/C1 -> {*}

# Save settings to EEPROM
POST /api/config/C0 -> {"success":true}|{*}

# Reset all settings
POST /api/config/C2 -> {"success":true}|{*}
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

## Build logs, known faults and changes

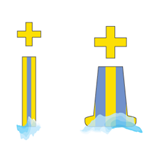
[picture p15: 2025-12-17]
NextionControlPanel/src/Markers/Hazard.png

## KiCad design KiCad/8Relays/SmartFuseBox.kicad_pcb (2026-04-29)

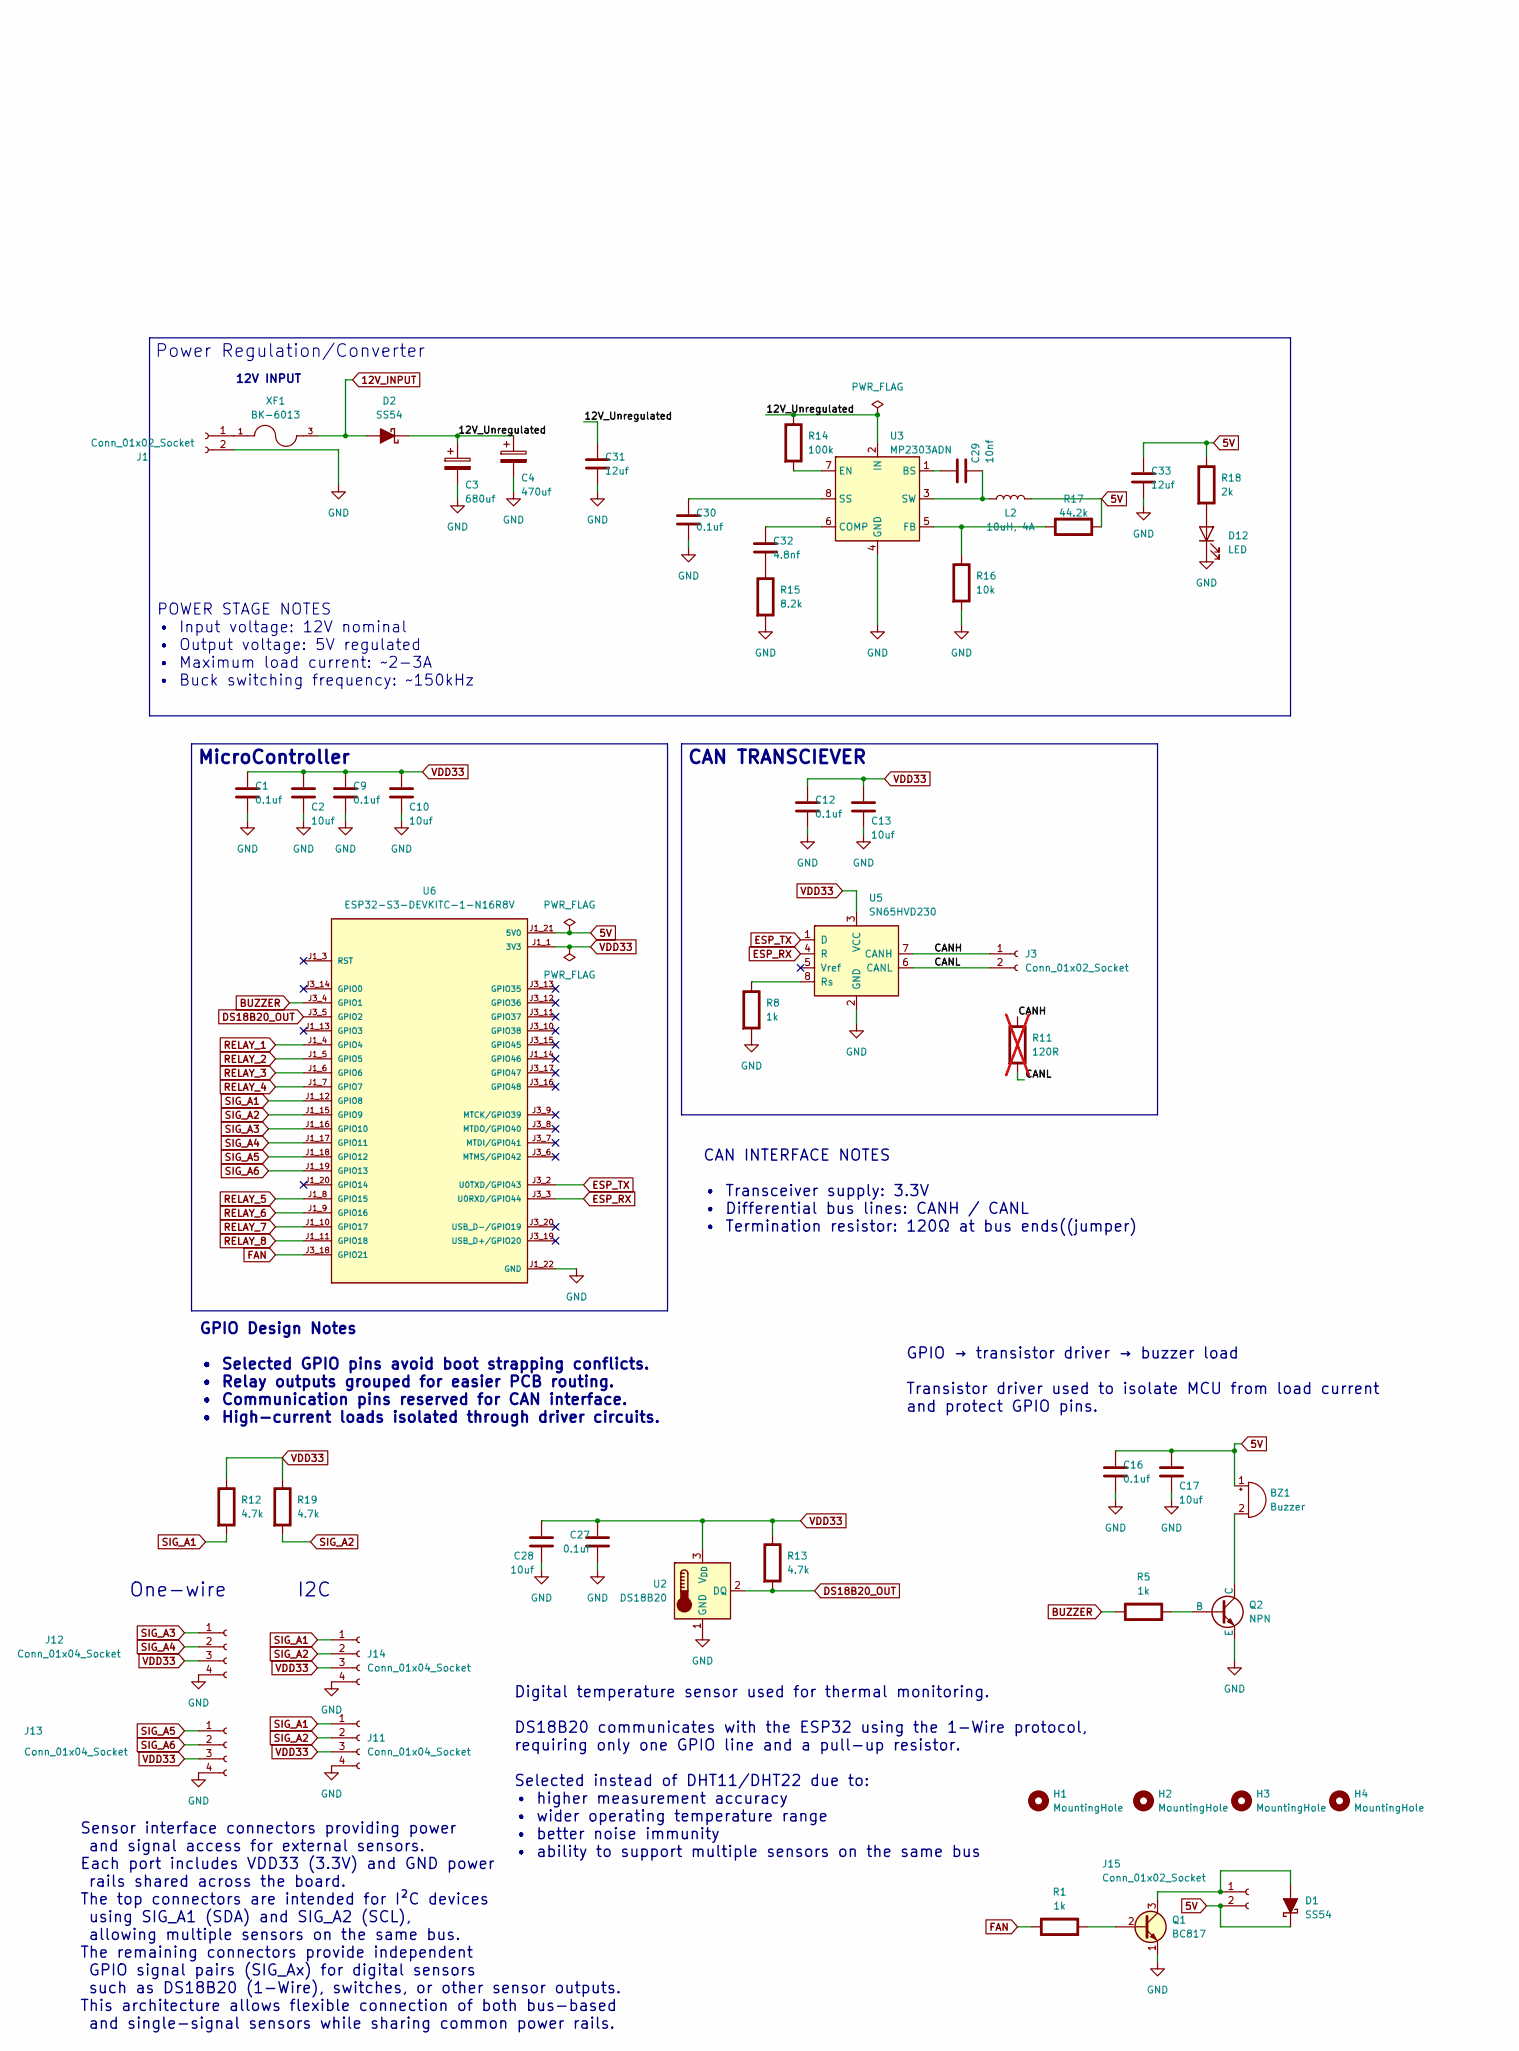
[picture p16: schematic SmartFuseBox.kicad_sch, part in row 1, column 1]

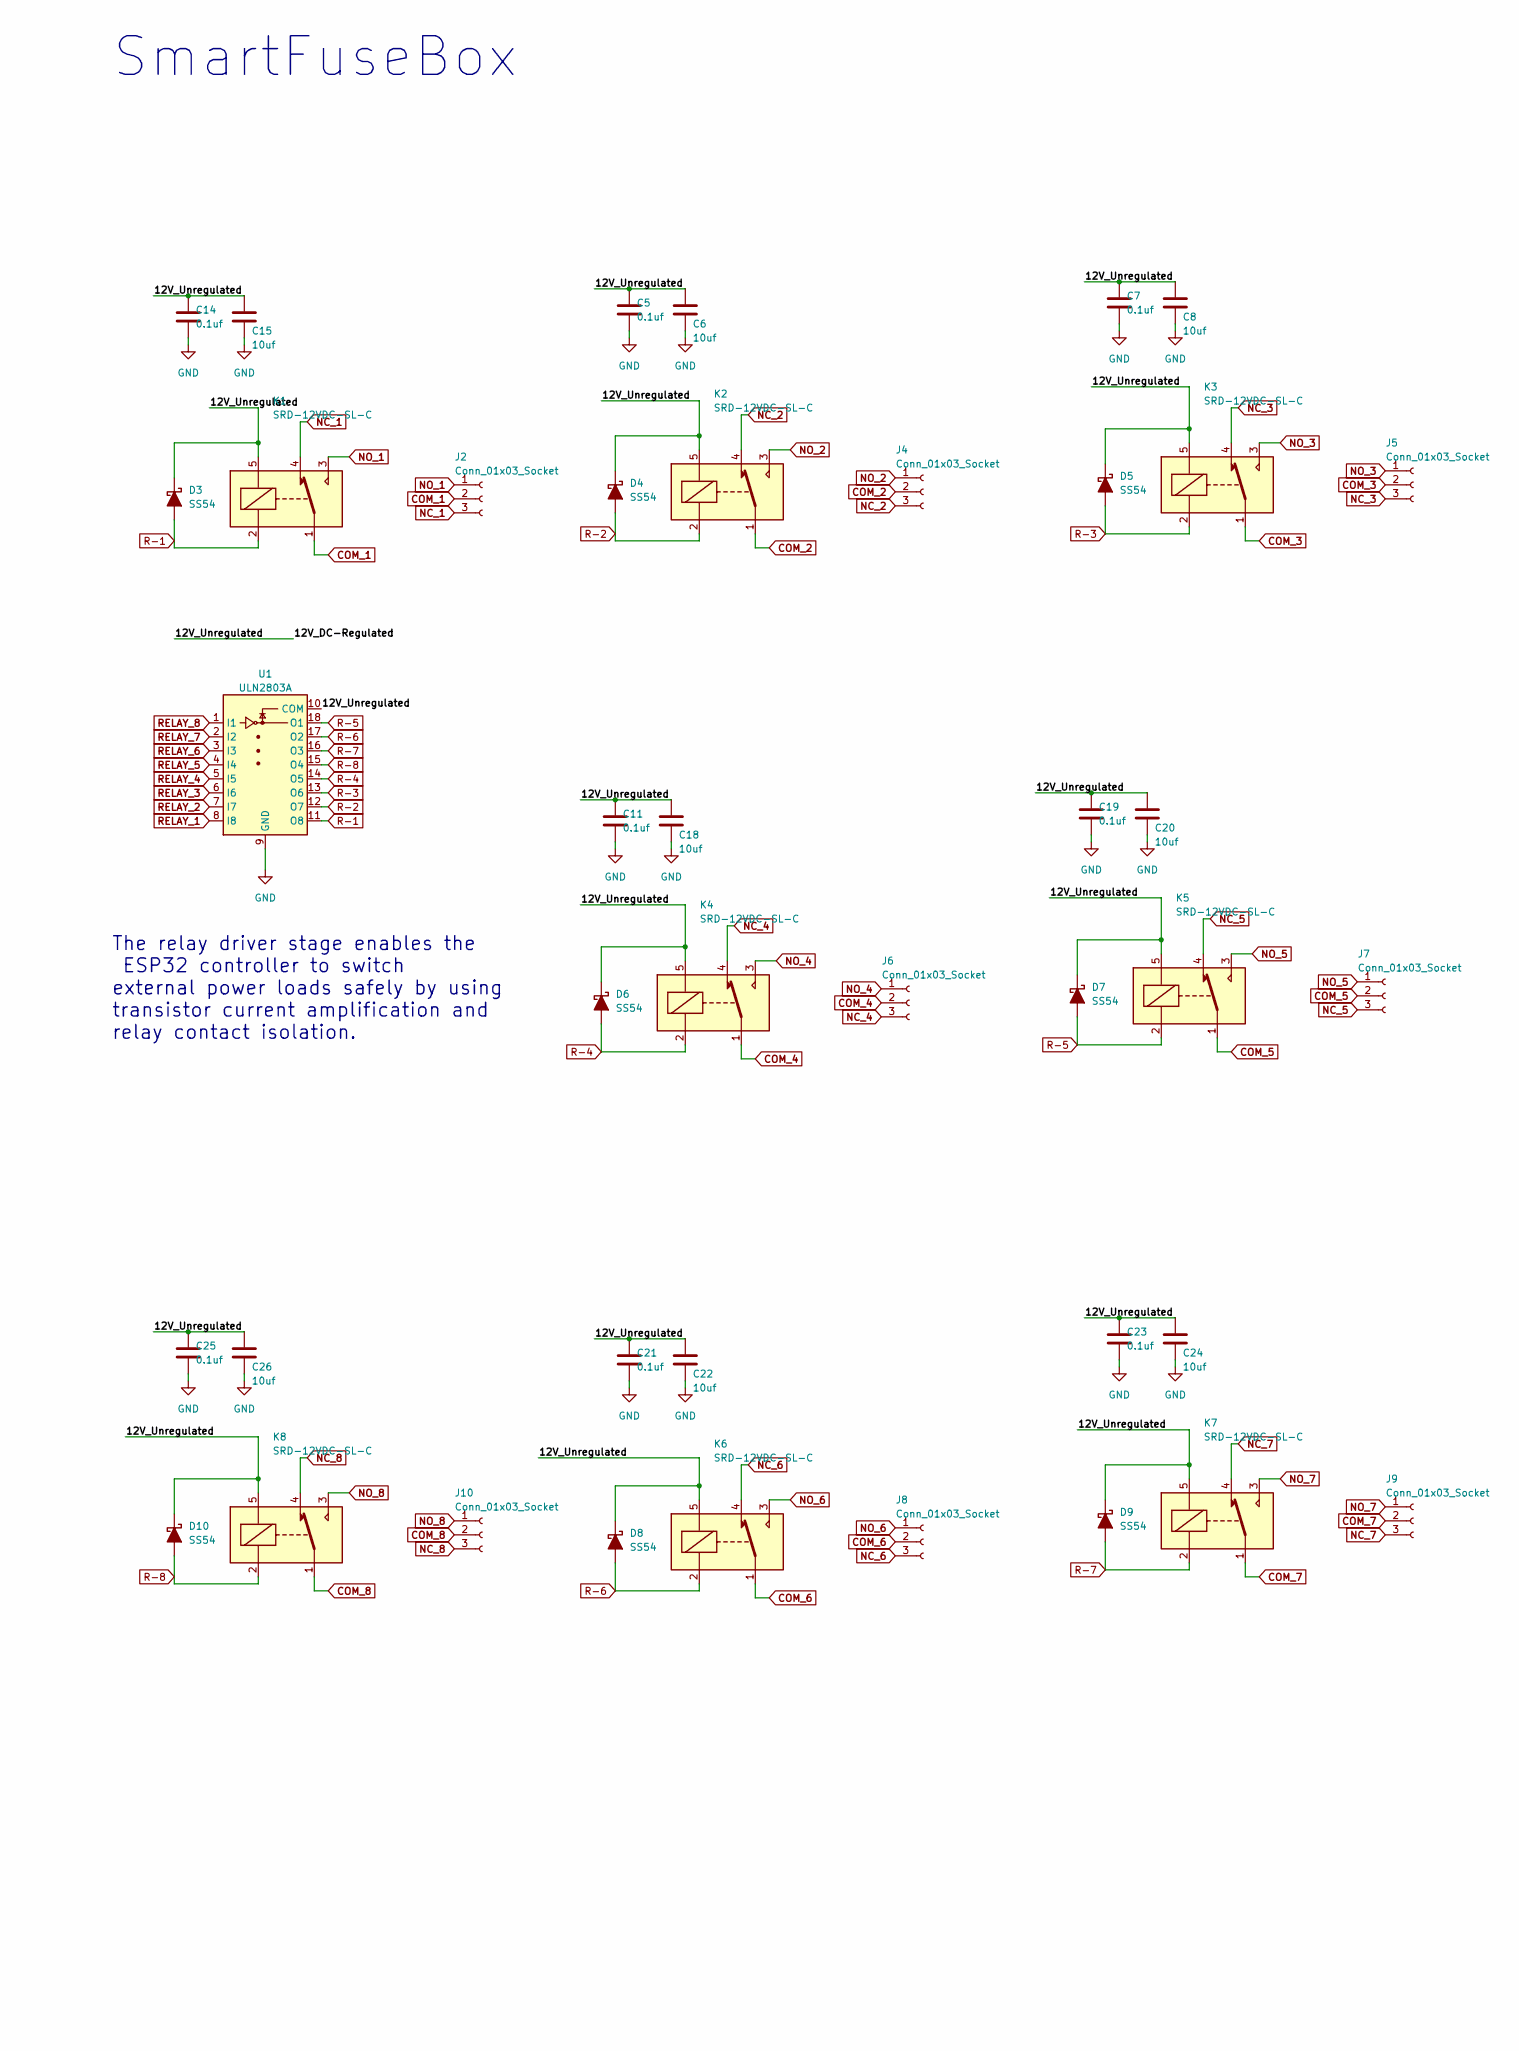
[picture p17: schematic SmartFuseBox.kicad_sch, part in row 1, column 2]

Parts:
BZ1: Buzzer; Buzzer_12x9.5RM7.6
C1, C5, C7, C9, C11, C12, C14, C16, C19, C21, C23, C25, C27, C30: 0.1uf; C_0805_2012Metric_Pad1.18x1.45mm_HandSolder
C2, C6, C8, C10, C13, C15, C17, C18, C20, C22, C24, C26, C28: 10uf; C_0805_2012Metric_Pad1.18x1.45mm_HandSolder
C3: 680uf; CP_Elec_6.3x7.7
C4: 470uf; CP_Elec_10x10.5
C29: 10nf; C_0805_2012Metric_Pad1.18x1.45mm_HandSolder
C31, C33: 12uf; C_0805_2012Metric_Pad1.18x1.45mm_HandSolder
C32: 4.8nf; C_0805_2012Metric_Pad1.18x1.45mm_HandSolder
D1, D2, D3, D4, D5, D6, D7, D8, D9, D10: SS54; D_SMA
D12: LED; LED_0805_2012Metric_Pad1.15x1.40mm_HandSolder
H1, H2, H3, H4: MountingHole; MountingHole_3.2mm_M3
J1, J3: Conn_01x02_Socket; TerminalBlock_MaiXu_MX126-5.0-02P_1x02_P5.00mm
J2, J4, J5, J6, J7, J8, J9, J10: Conn_01x03_Socket; TerminalBlock_MaiXu_MX126-5.0-03P_1x03_P5.00mm
J11, J12, J13, J14: Conn_01x04_Socket; JST_PH_S4B-PH-K_1x04_P2.00mm_Horizontal
J15: Conn_01x02_Socket; JST_XH_S2B-XH-A-1_1x02_P2.50mm_Horizontal
K1, K2, K3, K4, K5, K6, K7, K8: SRD-12VDC-SL-C; Relay_SPDT_SANYOU_SRD_Series_Form_C
L2: 10uH, 4A; L_SOREDE_SNR.1050_10x10x5mm
Q1: BC817; SOT-23
Q2: NPN; SOT23-3_PO123
R1, R5, R8: 1k; R_0805_2012Metric_Pad1.20x1.40mm_HandSolder; Rating W
R11: 120R; R_0805_2012Metric_Pad1.20x1.40mm_HandSolder; Rating W; not fitted
R12, R13, R19: 4.7k; R_0805_2012Metric_Pad1.20x1.40mm_HandSolder; Rating W
R14: 100k; R_0805_2012Metric_Pad1.20x1.40mm_HandSolder; Rating W
R15: 8.2k; R_0805_2012Metric_Pad1.20x1.40mm_HandSolder; Rating W
R16: 10k; R_0805_2012Metric_Pad1.20x1.40mm_HandSolder; Rating W
R17: 44.2k; R_0805_2012Metric_Pad1.20x1.40mm_HandSolder; Rating W
R18: 2k; R_0805_2012Metric_Pad1.20x1.40mm_HandSolder; Rating W
U1: ULN2803A; SOIC-18W_7.5x11.6mm_P1.27mm
U2: DS18B20; TO-92_Inline
U3: MP2303ADN; SOIC-8-1EP_3.9x4.9mm_P1.27mm_EP2.62x3.51mm
U5: SN65HVD230; SOIC-8_3.9x4.9mm_P1.27mm
U6: ESP32-S3-DEVKITC-1-N16R8V; XCVR_ESP32-S3-DEVKITC-1-N16R8V; PARTREV 1.1
XF1: BK-6013; FUSE_BK-6013; PARTREV 02/07/14

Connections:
5V: BZ1.1 (+), C16.1, C17.1, C33.1, D1.1 (K), J15.2, L2.2, R17.2 (-), R18.1 (+), U6.J1_21 (5V0)
12V_INPUT: D2.2 (A), XF1.3, XF1.4
/12V_DC-Regulated: C3.1, C4.1, C5.1, C6.1, C7.1, C8.1, C11.1, C14.1, C15.1, C18.1, C19.1, C20.1, C21.1, C22.1, C23.1, C24.1, C25.1, C26.1, C31.1, D2.1 (K), D3.1 (K), D4.1 (K), D5.1 (K), D6.1 (K), D7.1 (K), D8.1 (K), D9.1 (K), D10.1 (K), K1.5, K2.5, K3.5, K4.5, K5.5, K6.5, K7.5, K8.5, R14.1 (+), U1.10 (COM), U3.2 (IN)
/CANH: J3.1, R11.1 (+), U5.7 (CANH)
/CANL: J3.2, R11.2 (-), U5.6 (CANL)
BUZZER: R5.1 (+), U6.J3_4 (GPIO1)
COM_1: J2.2, K1.1
COM_2: J4.2, K2.1
COM_3: J5.2, K3.1
COM_4: J6.2, K4.1
COM_5: J7.2, K5.1
COM_6: J8.2, K6.1
COM_7: J9.2, K7.1
COM_8: J10.2, K8.1
DS18B20_OUT: R13.2 (-), U2.2 (DQ), U6.J3_5 (GPIO2)
ESP_RX: U5.4 (R), U6.J3_3 (U0RXD/GPIO44)
ESP_TX: U5.1 (D), U6.J3_2 (U0TXD/GPIO43)
FAN: R1.1 (+), U6.J3_18 (GPIO21)
GND: C1.2, C2.2, C3.2, C4.2, C5.2, C6.2, C7.2, C8.2, C9.2, C10.2, C11.2, C12.2, C13.2, C14.2, C15.2, C16.2, C17.2, C18.2, C19.2, C20.2, C21.2, C22.2, C23.2, C24.2, C25.2, C26.2, C27.2, C28.2, C30.2, C31.2, C33.2, D12.1 (K), J1.2, J11.4, J12.4, J13.4, J14.4, Q1.1 (E), Q2.3 (E), R8.2 (-), R15.2 (-), R16.2 (-), U1.9 (GND), U2.1 (GND), U3.4 (GND), U5.2 (GND), U6.J1_22 (GND), U6.J3_1 (GND), U6.J3_21 (GND), U6.J3_22 (GND)
NC_1: J2.3, K1.4
NC_2: J4.3, K2.4
NC_3: J5.3, K3.4
NC_4: J6.3, K4.4
NC_5: J7.3, K5.4
NC_6: J8.3, K6.4
NC_7: J9.3, K7.4
NC_8: J10.3, K8.4
NO_1: J2.1, K1.3
NO_2: J4.1, K2.3
NO_3: J5.1, K3.3
NO_4: J6.1, K4.3
NO_5: J7.1, K5.3
NO_6: J8.1, K6.3
NO_7: J9.1, K7.3
NO_8: J10.1, K8.3
unnamed: BZ1.2 (-), Q2.1 (C)
unnamed: D1.2 (A), J15.1, Q1.3 (C)
unnamed: D12.2 (A), R18.2 (-)
unnamed: J1.1, XF1.1, XF1.2
unnamed: Q1.2 (B), R1.2 (-)
unnamed: Q2.2 (B), R5.2 (-)
unnamed: R8.1 (+), U5.8 (Rs)
unnamed: R14.2 (-), U3.7 (EN)
unnamed: C32.2, R15.1 (+)
unnamed: R16.1 (+), R17.1 (+), U3.5 (FB)
unnamed: C29.1, U3.1 (BS)
unnamed: C32.1, U3.6 (COMP)
unnamed: C30.1, U3.8 (SS)
unnamed: C29.2, L2.1, U3.3 (SW)
R-1: D3.2 (A), K1.2, U1.11 (O8)
R-2: D4.2 (A), K2.2, U1.12 (O7)
R-3: D5.2 (A), K3.2, U1.13 (O6)
R-4: D6.2 (A), K4.2, U1.14 (O5)
R-5: D7.2 (A), K5.2, U1.18 (O1)
R-6: D8.2 (A), K6.2, U1.17 (O2)
R-7: D9.2 (A), K7.2, U1.16 (O3)
R-8: D10.2 (A), K8.2, U1.15 (O4)
RELAY_1: U1.8 (I8), U6.J1_4 (GPIO4)
RELAY_2: U1.7 (I7), U6.J1_5 (GPIO5)
RELAY_3: U1.6 (I6), U6.J1_6 (GPIO6)
RELAY_4: U1.5 (I5), U6.J1_7 (GPIO7)
RELAY_5: U1.4 (I4), U6.J1_8 (GPIO15)
RELAY_6: U1.3 (I3), U6.J1_9 (GPIO16)
RELAY_7: U1.2 (I2), U6.J1_10 (GPIO17)
RELAY_8: U1.1 (I1), U6.J1_11 (GPIO18)
SIG_A1: J11.1, J14.1, R12.2 (-), U6.J1_12 (GPIO8)
SIG_A2: J11.2, J14.2, R19.2 (-), U6.J1_15 (GPIO9)
SIG_A3: J12.1, U6.J1_16 (GPIO10)
SIG_A4: J12.2, U6.J1_17 (GPIO11)
SIG_A5: J13.1, U6.J1_18 (GPIO12)
SIG_A6: J13.2, U6.J1_19 (GPIO13)
VDD33: C1.1, C2.1, C9.1, C10.1, C12.1, C13.1, C27.1, C28.1, J11.3, J12.3, J13.3, J14.3, R12.1 (+), R13.1 (+), R19.1 (+), U2.3 (V_{DD}), U5.3 (VCC), U6.J1_1 (3V3), U6.J1_2 (3V3)

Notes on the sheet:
Sensor interface connectors providing power and signal access for external sensors. Each port includes VDD33 (3.3V) and GND power rails shared across the board. The top connectors are intended for I²C devices using SIG_A1 (SDA) and SIG_A2 (SCL), allowing multiple sensors on the same bus. The remain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
The relay driver stage enables the ESP32 controller to switch external power loads safely by using transistor current amplification and relay contact isolation.
GPIO Design Notes • Selected GPIO pins avoid boot strapping conflicts. • Relay outputs grouped for easier PCB routing. • Communication pins reserved for CAN interface. • High-current loads isolated through driver circuits.
I2C
CAN INTERFACE NOTES • Transceiver supply: 3.3V • Differential bus lines: CANH / CANL • Termination resistor: 120Ω at bus ends((jumper)
${TITLE}
One-wire
12V INPUT
GPIO → transistor driver → buzzer load Transistor driver used to isolate MCU from load current and protect GPIO pins.
Digital temperature sensor used for thermal monitoring. DS18B20 communicates with the ESP32 using the 1-Wire protocol, requiring only one GPIO line and a pull-up resistor. Selected instead of DHT11/DHT22 due to: • higher measurement accuracy • wider operating temperature range • better noise immuni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
POWER STAGE NOTES • Input voltage: 12V nominal • Output voltage: 5V regulated • Maximum load current: ~2-3A • Buck switching frequency: ~150kHz
Power Regulation/Converter
MicroController
CAN TRANSCIEVER

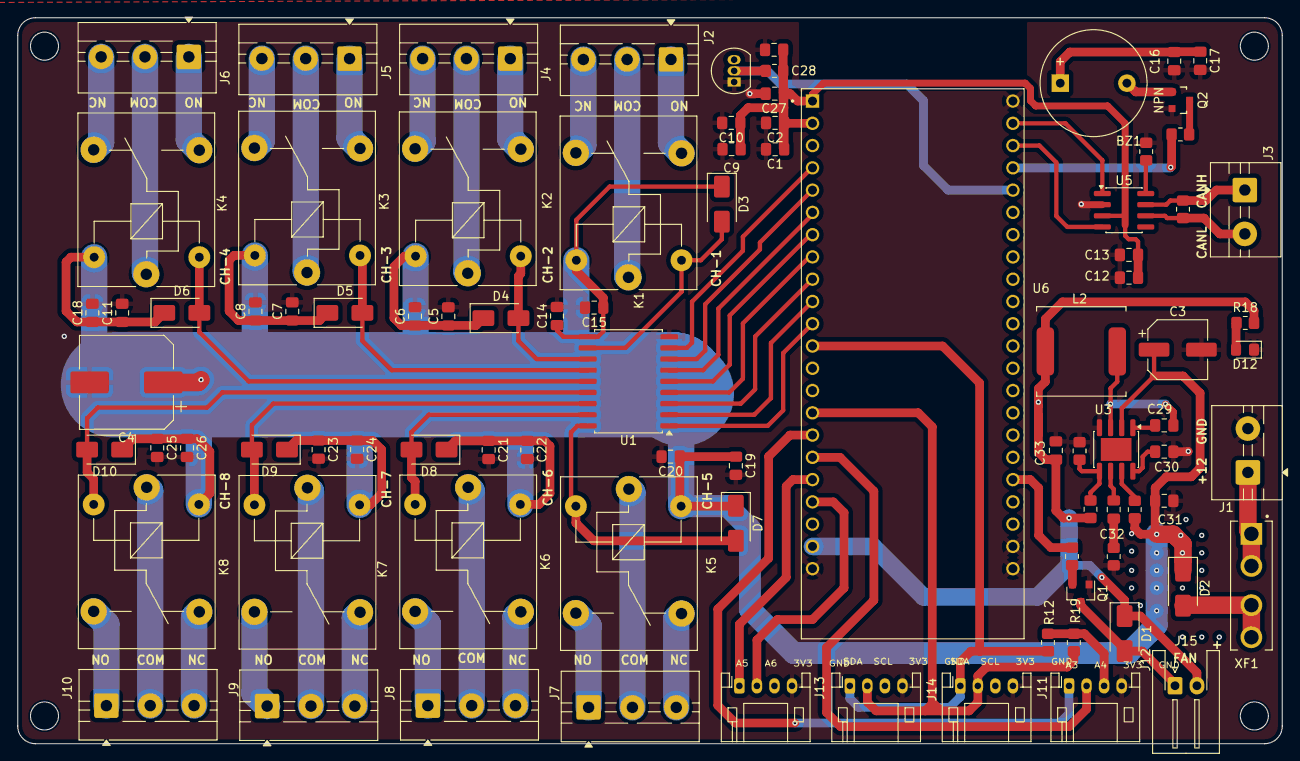
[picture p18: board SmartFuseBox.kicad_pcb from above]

Board: 4 copper layers, 144.2 x 82.8 mm, 93 parts (0 on the bottom side), 72 nets.

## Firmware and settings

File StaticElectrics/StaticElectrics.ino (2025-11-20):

#include <Arduino.h>
#include <stdint.h>
#include <SerialCommandManager.h>

#include "StaticElectricConstants.h"
#include "Config.h"
#include "ConfigManager.h"
#include "ConfigCommandHandler.h"
#include "SoundManager.h"

#include "SystemCommandHandler.h"
#include "AckCommandHandler.h"
#include "SoundCommandHandler.h"
#include "RelayCommandHandler.h"
#include "BaseCommandHandler.h"

#include "WaterSensorHandler.h"
#include "Dht11SensorHandler.h"
#include "SensorManager.h"


#define COMPUTER_SERIAL Serial
#define LINK_SERIAL Serial1

// forward declares
void InitializeSerial(HardwareSerial& serialPort, unsigned long baudRate, bool waitForConnection = false);
void onComputerCommandReceived(SerialCommandManager* mgr);
void onLinkCommandReceived(SerialCommandManager* mgr);

SerialCommandManager commandMgrComputer(&COMPUTER_SERIAL, onComputerCommandReceived, '\n', ':', '=', 500, 64);
SerialCommandManager commandMgrLink(&LINK_SERIAL, onLinkCommandReceived, '\n', ':', '=', 500, 64);

// Broadcast manager for coordinated messaging
BroadcastManager broadcastManager(&commandMgrComputer, &commandMgrLink);

SoundManager soundManager;

SystemCommandHandler systemHandler(&broadcastManager);
AckCommandHandler ackHandler(&broadcastManager);
RelayCommandHandler relayHandler(&commandMgrComputer, &commandMgrLink, Relays, TotalRelays);
SoundCommandHandler soundHandler(&commandMgrComputer, &commandMgrLink, &soundManager);
ConfigCommandHandler configHandler(&soundManager);


// Sensors
WaterSensorHandler waterSensorHandler(&commandMgrLink, &commandMgrComputer, WaterSensorPin, WaterSensorActivePin);
Dht11SensorHandler dht11SensorHandler(&commandMgrLink, &commandMgrComputer, Dht11SensorPin);

BaseSensorHandler* sensorHandlers[] = {
	&waterSensorHandler, &dht11SensorHandler
};
SensorManager sensorManager(sensorHandlers, sizeof(sensorHandlers) / sizeof(sensorHandlers[0]));


void setup()
{
	ISerialCommandHandler* linkHandlers[] = { &relayHandler, &soundHandler, &configHandler, &ackHandler, &systemHandler } ;
	size_t linkHandlerCount = sizeof(linkHandlers) / sizeof(linkHandlers[0]);
	commandMgrLink.registerHandlers(linkHandlers, linkHandlerCount);

	ISerialCommandHandler* computerHandlers[] = { &relayHandler, &soundHandler, &configHandler, &ackHandler, &systemHandler };
	size_t computerHandlerCount = sizeof(computerHandlers) / sizeof(computerHandlers[0]);
	commandMgrComputer.registerHandlers(computerHandlers, computerHandlerCount);

	InitializeSerial(COMPUTER_SERIAL, 115200, true);
	InitializeSerial(LINK_SERIAL, 9600, true);

	sensorManager.setup();
	relayHandler.setup();

	soundManager.configUpdated(ConfigManager::getConfigPtr());

	commandMgrComputer.sendCommand(SystemInitialized, "");
}

void loop() 
{
	unsigned long now = millis();
	commandMgrComputer.readCommands();
	commandMgrLink.readCommands();
	soundManager.update();
	sensorManager.update(now);

	delay(DefaultDelay);
}

void onComputerCommandReceived(SerialCommandManager* mgr)
{
	commandMgrComputer.sendError(mgr->getRawMessage(), F("STATCMD"));
}

void onLinkCommandReceived(SerialCommandManager* mgr)
{
	commandMgrComputer.sendError(mgr->getRawMessage(), F("STATLNK"));
}

void InitializeSerial(HardwareSerial& serialPort, unsigned long baudRate, bool waitForConnection)
{
	serialPort.begin(baudRate);

	if (waitForConnection)
	{
		unsigned long leave = millis() + SerialInitTimeoutMs;

		while (!serialPort && millis() < leave)
			delay(10);

		if (serialPort)
			delay(100);
	}
}

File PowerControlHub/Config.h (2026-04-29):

/*
 * PowerControlHub
 * Copyright (C) 2025 Simon Carter (s1cart3r@gmail.com)
 *
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
 * You should have received a copy of the GNU General Public License
 * along with this program. If not, see <https://www.gnu.org/licenses/>.
 */
#pragma once
#include <Arduino.h>
#include <stdint.h>

#include "SystemDefinitions.h"
#include "Local.h"


constexpr uint8_t ConfigMaxScheduledEvents = MAXIMUM_EVENTS;
constexpr uint8_t ConfigSchedulerPayloadSize = 4;
constexpr uint8_t ConfigScheduleEventReserved = 8;
constexpr uint8_t ConfigSchedulerReservedSize = 10;

// MQTT Configuration
constexpr uint8_t ConfigMqttBrokerLength = 64;
constexpr uint8_t ConfigMqttUsernameLength = 32;
constexpr uint8_t ConfigMqttPasswordLength = 32;
constexpr uint8_t ConfigMqttDeviceIdLength = 32;
constexpr uint8_t ConfigMqttDiscoveryPrefixLength = 32;
constexpr uint16_t ConfigMqttDefaultPort = 1883;
constexpr uint16_t ConfigMqttKeepAliveDefault = 60;

// sensors
constexpr uint8_t ConfigMaxSensors = 8;
constexpr uint8_t ConfigMaxSensorNameLength = 21;
constexpr uint8_t ConfigMaxSensorPins = 4;

constexpr uint32_t SystemHeaderMagic = 0x53464201;  // 'SFB\x01'

// Flags stored in SystemHeader::reserved[0]
constexpr uint8_t OtaFlagAutoApply = 0x01;  // bit0: automatically download and apply updates

constexpr uint8_t ConfigAuthApiKeyLength = 32;
constexpr uint8_t ConfigAuthHmacKeyLength = 32;

struct SystemHeader {
    uint32_t magic;               // offset 0  — must equal SystemHeaderMagic
    uint32_t bootCount;           // offset 4
    uint16_t configWrittenBy;     // offset 8
    uint8_t  headerVersion;       // offset 10 — for future header migrations
    uint8_t  crashCounter;        // offset 11
    uint8_t  lastResetReason;     // offset 12
    uint8_t  safeModeFlagsf;      // offset 13
    uint8_t  reserved[16];        // offset 14 — reserved[0] = OTA flags (see OtaFlagAutoApply)
    uint16_t checksum;            // offset 30 — always last
} __attribute__((packed));        // = 32 bytes

enum class LocationType : uint8_t
{
    Power = 0x00,                   // Power boat
    Sail = 0x01,                    // Sailing boat
    Fishing = 0x02,                 // Fishing boat
    Yacht = 0x03,                   // Yacht
	Shed = 0x04,                    // Shed
	Basement = 0x05,                // Basement
	Workshop = 0x06,                // Workshop
	Garage = 0x07,                  // Garage
	Bedroom = 0x08,                 // Bedroom
	Office = 0x09,                  // Office
	Other = 0xFF                    // Other/unspecified
};

enum class TriggerType : uint8_t
{
	None      = 0x00,
	TimeOfDay = 0x01,  // triggerPayload[0]=hour, [1]=minute
	Sunrise   = 0x02,  // triggerPayload[0..1]=int16 offset minutes before/after
	Sunset    = 0x03,  // triggerPayload[0..1]=int16 offset minutes before/after
	Interval  = 0x04,  // triggerPayload[0..1]=uint16 interval minutes
	DayOfWeek = 0x05,  // triggerPayload[0]=bitmask (bit0=Mon .. bit6=Sun)
	Date      = 0x06,  // triggerPayload[0]=day, [1]=month
};

enum class ConditionType : uint8_t
{
	None       = 0x00,
	TimeWindow = 0x01,  // conditionPayload[0]=start_hour, [1]=start_min, [2]=end_hour, [3]=end_min
	DayOfWeek  = 0x02,  // conditionPayload[0]=bitmask (bit0=Mon .. bit6=Sun)
	IsDark     = 0x03,  // no payload (computed from sunrise/sunset)
	IsDaylight = 0x04,  // no payload (computed from sunrise/sunset)
	RelayIsOn  = 0x05,  // conditionPayload[0]=relay index
	RelayIsOff = 0x06,  // conditionPayload[0]=relay index
};

enum class ExecutionActionType : uint8_t
{
	None         = 0x00,
	RelayOn      = 0x01,  // actionPayload[0]=relay index
	RelayOff     = 0x02,  // actionPayload[0]=relay index
	RelayToggle  = 0x03,  // actionPayload[0]=relay index
	RelayPulse   = 0x04,  // actionPayload[0]=relay index, [1..2]=uint16 duration seconds
	AllRelaysOn  = 0x05,
	AllRelaysOff = 0x06,
	SetPinHigh = 0x07,  // actionPayload[0]=pin number
	SetPinLow = 0x08,  // actionPayload[0]=pin number
};

enum class RelayActionType : uint8_t
{
	Default    = 0x00,
	Horn       = 0x01,  // Replaces SoundConfig::hornRelayIndex
	NightRelay = 0x02,  // Replaces LightSensorConfig::nightRelayIndex
};


// Keep struct packed and stable. Increase 'VERSION' when you change layout.
// Packed POD for persistent configuration.
constexpr uint8_t ConfigVersion1 = 1;
constexpr uint8_t ConfigVersion2 = 2;
constexpr uint8_t ConfigVersion3 = 3;
constexpr uint8_t ConfigVersion4 = 4;
constexpr uint8_t ConfigVersion5 = 5;
constexpr uint8_t ConfigVersion6 = 6;
constexpr uint8_t ConfigVersion = ConfigVersion6;
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

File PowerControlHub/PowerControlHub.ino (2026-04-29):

/*
 * PowerControlHub
 * Copyright (C) 2025 Simon Carter (s1cart3r@gmail.com)
 *
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
 * You should have received a copy of the GNU General Public License
 * along with this program. If not, see <https://www.gnu.org/licenses/>.
 */
#include <Arduino.h>
#include <SerialCommandManager.h>

#include "Local.h"
#include "PowerControlHubApp.h"
#include "SystemFunctions.h"

#include "WaterSensorHandler.h"
#include "Dht11SensorHandler.h"
#include "LightSensorHandler.h"
#include "SystemSensorHandler.h"
#include "GpsSensorHandler.h"

 // Hardware UART selection. Change this define if your board routes its serial
// port differently.
// COMPUTER_SERIAL – connected to the host PC / debug monitor.
// GPS_SERIAL      – connected to the GPS module.
#define COMPUTER_SERIAL Serial
#define GPS_SERIAL Serial2

// forward declares
void onComputerCommandReceived(SerialCommandManager* mgr);


// Consumer note:
// - `commandMgrComputer` is local to your .ino so you can select the hardware
//   Serial instance and baud rate appropriate for your board. Keep the callback
//   `onComputerCommandReceived` in this file so it can access the serial manager.
// - Construct `PowerControlHubApp` with a pointer to the serial manager. Then
//   configure board-specific resources (e.g. GPS serial) via app accessors before
//   calling `app.setup()`. Call `app.loop()` from `loop()`.

SerialCommandManager commandMgrComputer(&COMPUTER_SERIAL, onComputerCommandReceived, '\n', ':', ';', '=', 500, 64);

PowerControlHubApp app(&commandMgrComputer);

void setup()
{
	// Serial initialization is performed first to ensure that any logging or error messages
	// from DateTimeManager or ConfigManager during initialization are properly output.
	SystemFunctions::initializeSerial(COMPUTER_SERIAL, 115200, true);
	SystemFunctions::initializeSerial(GPS_SERIAL, GpsBaudRate, false);

	app.setGpsSerial(&GPS_SERIAL);

	// configure app
	app.setup(nullptr, 0);
}

void loop()
{
	app.loop();
}

// Called when a command arrives on COMPUTER_SERIAL that no registered handler
// claimed. Reports the unrecognised message back to the sender as an error and
// resets the serial buffer to discard any partial frame that may follow.
void onComputerCommandReceived(SerialCommandManager* mgr)
{
	commandMgrComputer.sendError(mgr->getRawMessage(), F("STATCMD"));
	SystemFunctions::resetSerial(COMPUTER_SERIAL);
}

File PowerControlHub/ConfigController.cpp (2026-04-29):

/*
 * PowerControlHub
 * Copyright (C) 2025 Simon Carter (s1cart3r@gmail.com)
 *
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
 * You should have received a copy of the GNU General Public License
 * along with this program. If not, see <https://www.gnu.org/licenses/>.
 */
#include "ConfigController.h"
#include "SystemDefinitions.h"
#include "RelayController.h"
#include "IBluetoothRadio.h"
#include "IWifiController.h"
#include "SystemFunctions.h"

// from NextionIds.h
constexpr uint8_t ImageButtonColorBlue = 2;
constexpr uint8_t ImageButtonColorYellow = 7;


ConfigController::ConfigController(SoundController* soundController, 
	IBluetoothRadio* bluetoothRadio,
	IWifiController* wifiController)
	: _soundController(soundController),
	_bluetoothRadio(bluetoothRadio),
	_wifiController(wifiController),
	_config(nullptr)
{
	_config = ConfigManager::getConfigPtr();
}

Config* ConfigController::getConfigPtr()
{
	return _config;
}

ConfigResult ConfigController::save()
{
	if (_config == nullptr)
		return ConfigResult::InvalidConfig;

	return ConfigManager::save() ? ConfigResult::Success : ConfigResult::Failed;
}

ConfigResult ConfigController::reset()
{
	if (_config == nullptr)
		return ConfigResult::InvalidConfig;

	ConfigManager::resetToDefaults();
	return ConfigResult::Success;
}

ConfigResult ConfigController::rename(const char* name)
{
	if (_config == nullptr)
		return ConfigResult::InvalidConfig;

	if (name == nullptr)
		return ConfigResult::InvalidParameter;

	if (strlen(name) > ConfigMaxNameLength)
		return ConfigResult::TooLong;

	strncpy(_config->location.name, name, sizeof(_config->location.name) - 1);
	_config->location.name[sizeof(_config->location.name) - 1] = '\0';
	return ConfigResult::Success;
}

ConfigResult ConfigController::mapHomeButton(const uint8_t homeButtonIndex, const uint8_t relayIndex)
{
	if (_config == nullptr)
		return ConfigResult::InvalidCommand;

	if (homeButtonIndex >= ConfigHomeButtons)
		return ConfigResult::InvalidParameter;
	
	if (relayIndex >= ConfigRelayCount)
		return ConfigResult::InvalidRelay;

	_config->relay.homePageMapping[homeButtonIndex] = relayIndex;
	return ConfigResult::Success;
}

ConfigResult ConfigController::setLocationType(const uint8_t locationlType)
{
	if (_config == nullptr)
		return ConfigResult::InvalidConfig;

	if (locationlType > static_cast<uint8_t>(LocationType::Yacht))
		return ConfigResult::InvalidParameter;

	_config->location.locationType = static_cast<LocationType>(locationlType);
	updateSoundControllerConfig();
	return ConfigResult::Success;
}

void ConfigController::updateSoundControllerConfig()
{
	if (_soundController != nullptr && _config != nullptr)
	{
		_soundController->configUpdated(_config);
	}
}

ConfigResult ConfigController::setsoundDelayStart(const uint16_t delayMilliSeconds)
{
	if (_config == nullptr)
		return ConfigResult::InvalidConfig;

	_config->sound.startDelayMs = delayMilliSeconds;
	updateSoundControllerConfig();
	return ConfigResult::Success;
}

ConfigResult ConfigController::setBluetoothEnabled(const bool enabled)
{
	if (_config == nullptr)
		return ConfigResult::InvalidConfig;

	_config->network.bluetoothEnabled = enabled;

	// do not apply live, only on next restart, otherwise too many enabled/disable cycles will 
	// eventually force the board to run out of memory, the only exception to this is if 
	// it starts disabled and is being enabled now, i.e. once on it needs rebooting to turn off again
	if (_bluetoothRadio && !_bluetoothRadio->isEnabled())
	{
		if (!_bluetoothRadio->setEnabled(enabled))
		{
			return ConfigResult::BluetoothInitFailed;
		}
	}

	return ConfigResult::Success;
}

ConfigResult ConfigController::setWifiEnabled(const bool enabled)
{
	if (_config == nullptr)
		return ConfigResult::InvalidConfig;

	_config->network.wifiEnabled = enabled;

	// do not apply live, only on next restart, otherwise too many enabled/disable cycles will 
	// eventually force the board to run out of memory, the only exception to this is if 
	// it starts disabled and is being enabled now, i.e. once on it needs rebooting to turn off again
	if (_wifiController && !_wifiController->isEnabled())
	{
		if (!_wifiController->setEnabled(enabled))
		{
			return ConfigResult::WifiInitFailed;
		}
	}

	return ConfigResult::Success;
}

ConfigResult ConfigController::setWifiAccessMode(const WifiMode accessMode)
{
	if (_config == nullptr)
		return ConfigResult::InvalidConfig;

	// only accept supported WiFi modes to avoid persisting invalid values from user input
	if (accessMode != WifiMode::AccessPoint && accessMode != WifiMode::Client)
		return ConfigResult::InvalidParameter;
	_config->network.accessMode = accessMode;
	return ConfigResult::Success;
}

ConfigResult ConfigController::setWifiSsid(const char* ssid)
{
	if (_config == nullptr || ssid == nullptr)
		return ConfigResult::InvalidConfig;

	if (strlen(ssid) > MaxSSIDLength - 1)
		return ConfigResult::TooLong;

	strncpy(_config->network.ssid, ssid, sizeof(_config->network.ssid) - 1);
	_config->network.ssid[sizeof(_config->network.ssid) - 1] = '\0';
	return ConfigResult::Success;
}

ConfigResult ConfigController::setWifiPassword(const char* password)
{
	if (_config == nullptr)
		return ConfigResult::InvalidConfig;

	if (password == nullptr)
		return ConfigResult::InvalidParameter;

	if (strlen(password) > MaxWiFiPasswordLength - 1)
		return ConfigResult::InvalidParameter;

	strncpy(_config->network.password, password, sizeof(_config->network.password) - 1);
	_config->network.password[sizeof(_config->network.password) - 1] = '\0';
	return ConfigResult::Success;
}

ConfigResult ConfigController::setWifiPort(const uint16_t port)
{
	if (_config == nullptr)
		return ConfigResult::InvalidConfig;

	if (port == 0)
	{
		return ConfigResult::InvalidParameter;
	}

	_config->network.port = port;
	return ConfigResult::Success;
}

ConfigResult ConfigController::setWifiIpAddress(const char* ipAddress)
{
	if (_config == nullptr)
		return ConfigResult::InvalidConfig;

	if (ipAddress == nullptr)
		return ConfigResult::InvalidParameter;

	if (strlen(ipAddress) > MaxIpAddressLength - 1)
		return ConfigResult::TooLong;

	IPAddress ip;
	if (!ip.fromString(ipAddress))
	{
		return ConfigResult::InvalidParameter;
	}

	strncpy(_config->network.apIpAddress, ipAddress, sizeof(_config->network.apIpAddress) - 1);
	_config->network.apIpAddress[sizeof(_config->network.apIpAddress) - 1] = '\0';
	return ConfigResult::Success;
}

// C20: Set timezone offset
ConfigResult ConfigController::setTimezoneOffset(const int8_t offset)
{
	if (_config == nullptr)
		return ConfigResult::InvalidConfig;

	// Validate range: -12 to +14 hours
	if (offset < -12 || offset > 14)
		return ConfigResult::InvalidParameter;

	_config->system.timezoneOffset = offset;
	return ConfigResult::Success;
}
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

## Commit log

2025-11-16 Auto name relay for sound commands Include BroadcastManager for multi serial comms
2025-11-17 Sensor management part 1 (#32)
    * Sensor management part 1
    * Update StaticElectrics/WaterSensorHandler.h
    * Update StaticElectrics/SensorManager.h
    * Update StaticElectrics/Dht11SensorHandler.h
    * Update StaticElectrics/WaterSensorHandler.h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
2025-11-19 Integrate Temp/Humidity sensor (#34)
    * Integrate Temp/Humidity sensor
    ---------
    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
2025-11-20 Feature/shared code (#36)
    * Initial sharing of code between projects using symbolic links
    * Add board used in local
2025-11-24 Update warning page, extend for default configuration both sides. (#45)
    Fix memory issue on UnoR4
    Cpu Monitoring and new monitor page on nextion
    [Dht11SensorHandler.h, SharedConstants.h]
2025-11-29 Feature/move sensors to shared (#52)
    * Fix issue with BroadcastManager and add queue to shared
    * Move sensors to common shared area
    * Update Shared/Queue.h
    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
    [Dht11SensorHandler.h]
2025-12-01 Feature/wifi (#54)
    * Initial non blocking wifi server
    * Implement with wifi controller
    * Pre full integration test
    * Integrate wifi into smart fuse box, only has relay at present, the remainder will form part of other PRs
2025-12-06 Feature/json updates and api index (#72)
    * Initial working version
    * Partially complete
    * Add api index, initial implementation
    * Update SmartFuseBox/SmartFuseBox.ino
    * Update Shared/Sensors/Dht11SensorHandler.h
    * Initial plan (#73)
    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
2025-12-16 Bug fixes and add Cardianl markers page (#86)
    [ConfigCommandHandler.cpp]
2025-12-21 Feature/always on relays (#89)
    * Convert to use ConfigController middleware
    * ConfigCommandHandler
    * set auto on relays, update json being sent for config, introduce LedManager
    * Integrate LedManager
    * Finalize initial on relays
2025-12-25 Compiler flag for LED matrix on R4 (#92)
2026-01-11 Feature/gps plus temp and light modules (#93)
    * Initial implementation
    * Move Gps sensor to boat controller
    * Working - ish
    * Final fix of GPS integration
    * Update Commands.md
    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
2026-01-25 Configure Config settings from nextion device (#97)
2026-01-28 Integrate LED light into control panel (#101)
2026-02-18 Feature/sd card driver (#111)
    * MicroSdDriver
    * Integrate warnings
2026-03-08 Adds “Scheduled events / timers” support to SmartFuseBox
    * Update config for timers and ensure the board itself has enough EEPROM to handle config
    * Updates for scheduled events
    * Shell Files for scheduler
    * Complete scheduled events
    * Update SmartFuseBox/Local.h
    * comments from code review
    * Fix typo
    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
    [Config.h, ConfigManager.cpp]
2026-03-11 Integrate light sensor analogue pin auto turn on light relay if dark (#126)
    * Integrate light sensor analogue pin auto turn on light relay if dark
    * Updates from code review
2026-03-11 Prep for KiCad, add Esp32.md and images (#127)
    Update .gitattributes to make life easier so as not to accidentally override .ino and Local.h
    [Comms_Monitoring.kicad_sch, ESP32_Module.kicad_sch, Power.kicad_sch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]
2026-03-12 Introduce BoardConfig.h to split Board capabilities away from Local.h
    Update documentation
2026-03-16 Fix warnings and ensure compiles on esp32 (#137)
    * Fix warnings and ensure compiles on esp32
    * Potential fix for pull request finding
    * Potential fix for pull request finding
    * Potential fix for pull request finding
    * Potential fix for pull request finding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
    [ConfigNetworkHandler.cpp]
2026-03-17 Configurable names for sensors (#138)
2026-03-19 Enhance MQTT Support (#139)
    * Enhance MQTT Support
    * Fixes from code review plus add sensor mqtt update frequency
    [Dht11SensorHandler.h]
2026-03-27 Re-factor how relay information is stored in EEPROM (#148)
    * Re-factor how relay information is stored in EEPROM
    Does not change actual relay code yet but set's the ground work
    * Updates from code review and update boatcontrolpanel
2026-03-28 Restructure code to individual repositories (#149)
    * Remove sub folders to own repositories
    * Replace sym link files with proper copies
    * Boat control panel is in it's own repo
    * shared files form part of the main projects
    * Remove symlink files as no longer required and move 3mf items to own repository
    [Aviation Connector Covers.3mf, Boat Sensor Housing.3mf, BoatFuseBox.3mf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]
2026-03-29 Update relay commands, (#150)
    This PR updates the relay/config command protocol to avoid command-prefix ambiguity and expands relay configuration capabilities (rename/color/default/link/actionType/pin), including persistence format changes (Config v4) and updated docs.
    [Config.h, ConfigCommandHandler.cpp, ConfigController.cpp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]
2026-03-31 Dynamically create sensors based on Config (#154)
    * Dynamically create sensors based on Config
    * Fixes from code review
    [ConfigCommandHandler.cpp, Dht11SensorHandler.h]
2026-04-02 Refactor GitHub Actions for ESP32 and ESP32-S3 builds
2026-04-02 OTA Updates based on tags created via git (#159)
    * OTA Updates based on tags created via git
    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
    [Config.h, Dht11SensorHandler.h]
2026-04-07 Set lat lon from home assistant so it can be used to find sunset/sunr… (#171)
    * Set lat lon from home assistant so it can be used to find sunset/sunrise times
    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
2026-04-12 Add ability to test SFB (#174)
    [config-commands.txt]
2026-04-18 Include Nextion code, increase test coverage (#178)
    This PR expands SmartFuseBox firmware support for Nextion-based UI pages and new configuration surfaces (pins, RTC, external sensors), and extends the repository’s command-driven test datasets to cov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
2026-04-21 Minor fixes and updates (#182)
    * Minor fixes and updates
    [Config.h, ConfigCommandHandler.cpp, ConfigManager.cpp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]
2026-04-26 Add initial home page to control/view relay statuses and view sensor … (#183)
    * Add initial home page to control/view relay statuses and view sensor data
    * fixes from code review
    [Dht11SensorHandler.h]
2026-04-29 Rename and restructure
    * Initial rename/new structure
    * Add files to sln
    * update build and release files
    * rename elements
    * final elements after local build
    [Aviation Connector Covers.3mf, Boat Sensor Housing.3mf, BoatFuseBox.3mf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]
2026-05-01 PCBWay (#187)
2026-09-13 Add reed sensor and document how to add sensors (#236)

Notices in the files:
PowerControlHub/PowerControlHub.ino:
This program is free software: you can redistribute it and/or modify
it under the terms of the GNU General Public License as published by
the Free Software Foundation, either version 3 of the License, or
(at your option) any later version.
